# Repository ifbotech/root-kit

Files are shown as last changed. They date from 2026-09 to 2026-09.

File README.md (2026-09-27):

# ROOTKIT

Una maceta con sensores y una pantalla que muestra **dos cosas: un QR al
principio y una cara después**. Cada ROOTKIT es uno de cuatro **Rooties**
—**Kip** el piloto audaz, **Nori** la crítica, **Blink** el cíclope optimista
y **Plum** la berenjenita—: la **carcasa impresa en 3D** es el cuerpo, y la
pantalla pone la cara, que reacciona a lo que necesita la planta. Todo lo
demás —números, tareas, avisos, la colección de Rooties y la charla con tu
planta— vive en **ROOTLAB**, la app del teléfono.

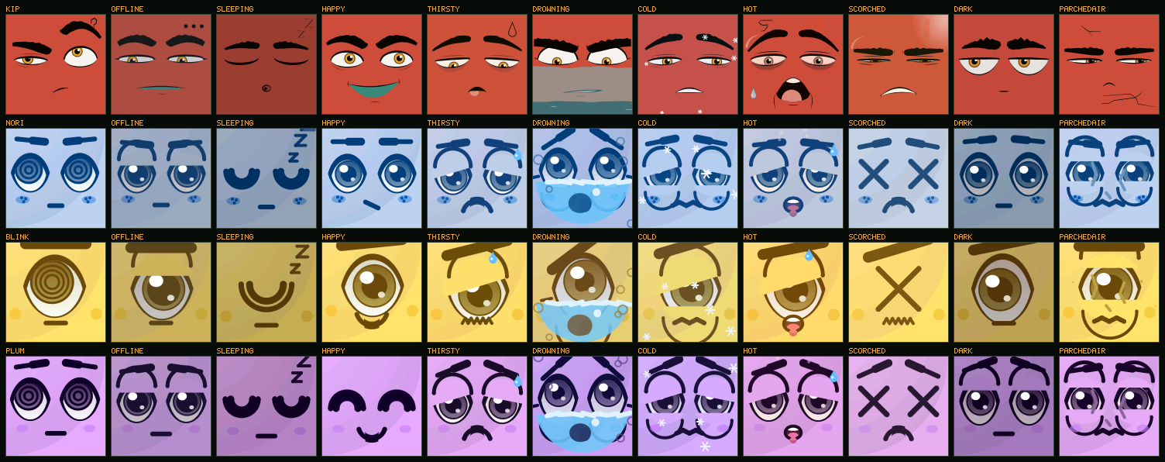
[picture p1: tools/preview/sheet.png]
Los cuatro Rooties en los once ánimos


Kip es rojo, con cejas negras tupidas que saltan y ojos blancos de iris
ámbar, y ya se dibuja y se mueve como en las láminas de Rocío: cada ánimo es
una secuencia de sus dibujos, interpolada cuadro a cuadro. Nori tiene ojos
almendrados y pecas; Blink, UN ojo enorme; Plum, ojos de cachorro. Cuando la
planta se ahoga el agua le llega a los ojos, y cuando el aire está seco la
cara se cuartea.

La figura define qué Rooti es; el cofre de la app sortea su **piel**: común
(70 %), rara (25 %) o épica (5 %). Las tres comparten la paleta del personaje
—es parte de quién es— y lo que cambia es el **acabado**: el fuego de Kip, el
acero y el cristal de Nori, el oro de Blink, el aura de Plum. La nube se la
manda a la maceta y la cara se pinta con eso:

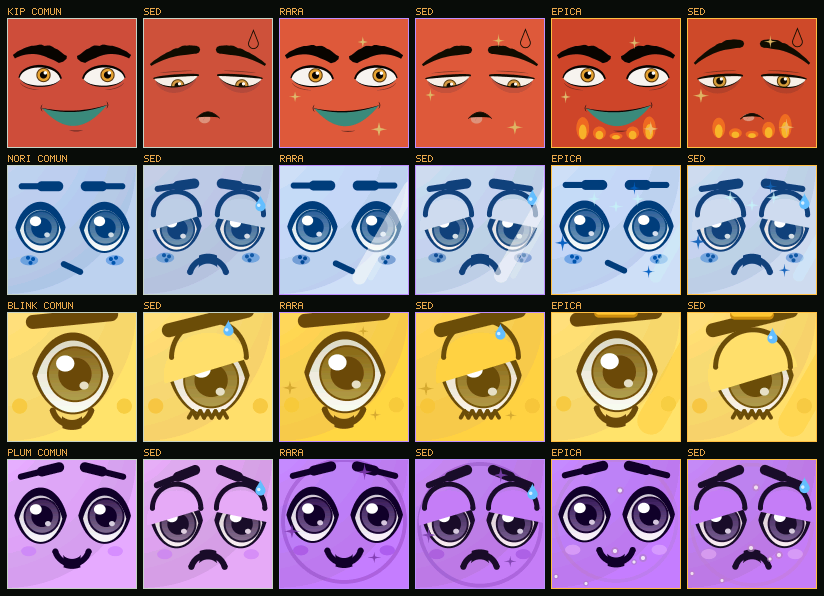
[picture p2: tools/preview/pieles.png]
Las tres pieles de cada Rooti


Para verlos a los cuatro juntos, en movimiento y con el cuerpo 3D: `npm start`
en root-lab y abrir **`/elenco/`**. Las láminas de acá se regeneran con
`make capturas`.

Del primer encendido a la cara: el QR, los ojos dormidos mientras esperás el
cofre, el despertar y la cara.

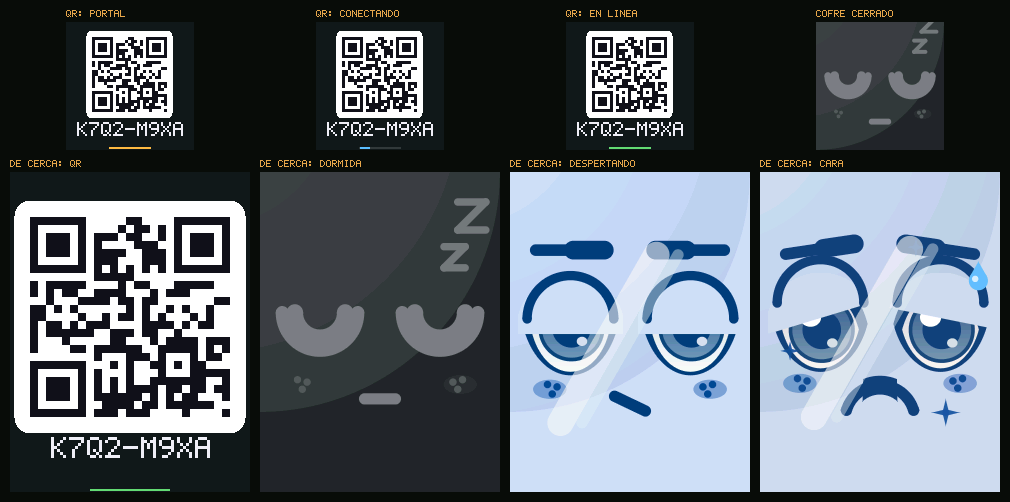
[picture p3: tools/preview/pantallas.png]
Las pantallas del ROOTKIT: QR, dormida, despertar y cara


Cuando abrís el cofre en la app, la maceta abre los ojos:

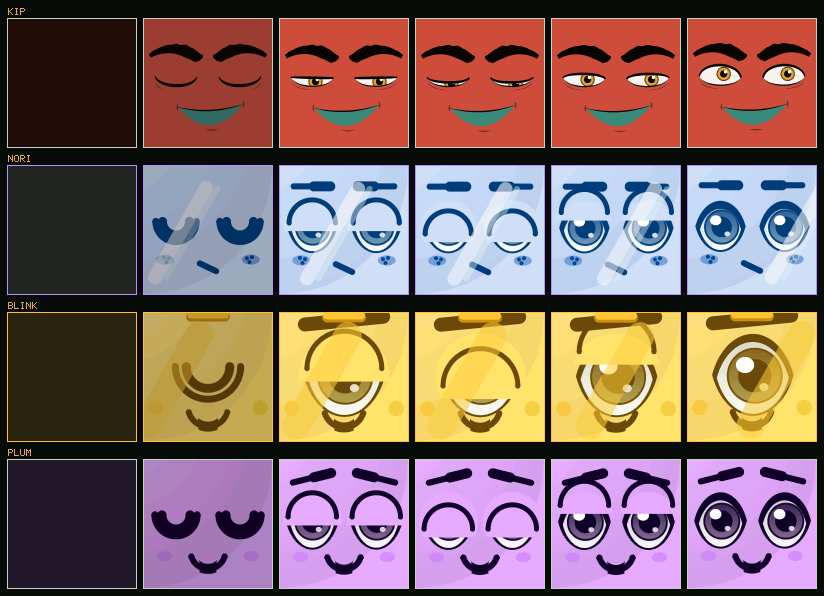
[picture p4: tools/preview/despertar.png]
El despertar de cada Rooti


Y cuando cambia de ánimo no salta: la cara pasa de una expresión a la otra
en un tercio de segundo, con un parpadeo en el medio.

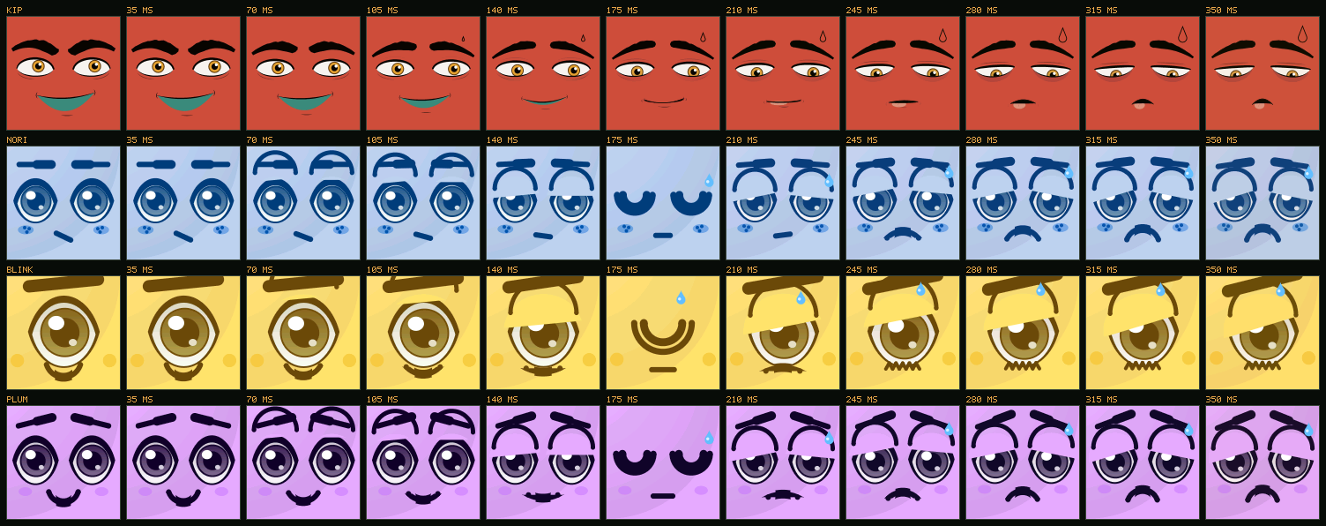
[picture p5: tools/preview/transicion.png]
De contento a sediento, cuadro a cuadro


ROOTLAB se pinta con los colores de la piel que salió, y en el teléfono se ve
el Rooti entero en 3D, con esta misma cara pintada encima, como una mascota
que se acaricia y se cuida.

## Los repositorios

| | Qué hay |
|---|---|
| **rootkit** (este) | Firmware, hardware, carcasas y la documentación del aparato |
| [**root-lab**](https://github.com/ifbotech/root-lab) | **ROOTLAB**: la app, la nube, las cuentas, la IA y el chat con la planta, el correo, las notificaciones y un emulador del Rooti |

Dos cosas de root-lab que se usan desde acá y conviene saber dónde están: **la trastienda** (el panel de quien hace el producto, en `/rootkit/admin`: [docs/trastienda.md](https://github.com/ifbotech/root-lab/blob/main/docs/trastienda.md)) y **los agentes** que revisan el proyecto y anotan mejoras ([agentes/](https://github.com/ifbotech/root-lab/tree/main/agentes), con [RUTINAS.md](https://github.com/ifbotech/root-lab/blob/main/agentes/RUTINAS.md) para dejarlos corriendo).

El agente de hardware, en cambio, vive **acá**: [agentes/ingeniero-de-hardware.md](agentes/ingeniero-de-hardware.md) diseña la PCB impresa con cinta de cobre y el diagrama de conexiones del producto físico.

**Probalo en línea:** https://ifbotech.com/rootkit/ (emulador en
https://ifbotech.com/rootkit/emulador/).

## El hardware

| | ROOTKIT |
|---|---|
| Placa | ESP32-C3 SuperMini (un ESP32 DevKit en el banco de pruebas) |
| Pantalla | TFT 1,44" 128×128 IPS, en una ventana biselada de la carcasa |
| Sensores | suelo capacitivo (calibrable desde la app), AHT20, BH1750, toque; DS18B20 opcional |
| Batería | 18650 con carga por USB-C: unos 6 meses |
| Carcasa | impresa en 3D **sin soportes**: es el cuerpo del Rooti |

Se **actualiza solo por aire**, con firmware firmado, y sale de **fábrica**
con su identidad grabada: [docs/ota.md](docs/ota.md) y
[docs/fabrica.md](docs/fabrica.md). Detalle de pines, consumo y lista de
compras: [docs/hardware.md](docs/hardware.md). La placa en sí —un sustrato
impreso en 3D con canaletas y cinta de cobre— está en
[docs/pcb.md](docs/pcb.md), y cómo se arma una unidad, en
[docs/armado.md](docs/armado.md).

## Empezar

```bash
make test         # 2277 comprobaciones del firmware, sin placa
make sim          # los cinco Rooties en una ventana, en vivo
make sheet        # 8 Rooties × 11 ánimos
make transicion   # el cambio de ánimo, cuadro a cuadro
make pantallas    # QR, dormida, despertar y cara
make wasm         # el renderer para la app (necesita clang y lld)
make placa        # compila el producto (c3-144) y el banco (devkit-144) con PlatformIO
```

El prototipo NodeMCU que soldó Rocío corre el **firmware de banco**: arranca
directo en la cara de Kip, que reacciona a los sensores, y muestra sus
lecturas ([docs/banco.md](docs/banco.md)):

```bash
cd firmware && pio run -e banco-nodemcu -t upload && pio device monitor
```

Flashear una placa:

```bash
cd firmware
pio run -e c3-144 -t upload && pio device monitor
```

Para ver el flujo completo sin placa, abrí el emulador en
**https://ifbotech.com/rootkit/emulador/** (o levantá **root-lab** en la
compu): corre este mismo firmware en el navegador y su QR abre ROOTLAB en el
teléfono. Por defecto la placa también sincroniza con ese servidor, por
HTTPS y verificando su certificado.

En Windows el firmware se compila y prueba dentro de WSL. Ver
[docs/entorno.md](docs/entorno.md).

## Estructura

```
firmware/
  core/        ánimo, especies, Rooties, vínculo, enlace, código, SHA-256
  gfx/         framebuffer, antialiasing en punto fijo, tipografía
  art/         expresiones, el rig de caras y la lámina de Kip
  ui/          cara, cara dormida, despertar y QR
  nodo/        sensores, suelo, batería, muestreo adaptativo, historial
  net/         JSON y el contrato con la nube
  esp32/       la placa: pantalla, sensores, portal, red (con certificados), energía
  wasm/        el núcleo compilado para el navegador
  banco/       el firmware de banco del prototipo NodeMCU (sensores + Kip)
  sim/ test/   simulador y pruebas
  third_party/ qrcodegen (MIT)
hardware/pcb/  el sustrato impreso: el dato, el modelo y lo que se genera
docs/          arquitectura, hardware, firmware, nube, roadmap, decisiones
tools/         capturas, estación de fábrica y el generador del sustrato
```

## Documentación

| | |
|---|---|
| [roadmap.md](docs/roadmap.md) | **Checklist y roadmap**: qué está hecho y qué falta, por fase |
| [arquitectura.md](docs/arquitectura.md) | Las tres piezas, el flujo y quién decide qué |
| [hardware.md](docs/hardware.md) | Placa, pantalla, sensores, batería, carga y conexiones |
| [pcb.md](docs/pcb.md) | **La PCB impresa**: el sustrato con canaletas, la cinta de cobre y lo que se verifica solo |
| [conexiones.md](docs/conexiones.md) | El diagrama de conexiones, red por red (generado) |
| [armado.md](docs/armado.md) | **Armar una unidad**: paso a paso, con los controles de multímetro |
| [firmware.md](docs/firmware.md) | Cómo está armado, cómo compilar y qué hace al encender |
| [nube.md](docs/nube.md) | El contrato con la nube, con vectores de prueba |
| [ota.md](docs/ota.md) | Actualizaciones por aire firmadas, y qué pasa si una versión no anda |
| [fabrica.md](docs/fabrica.md) | La estación de fábrica: identidad, registro en la nube y etiqueta |
| [carcasas.md](docs/carcasas.md) | Diseño e impresión de las carcasas |
| [decisiones.md](docs/decisiones.md) | Lo que se decidió, lo que se revisó y por qué |
| [testing.md](docs/testing.md) | Qué cubren las pruebas |
| [banco.md](docs/banco.md) | **El firmware de banco** del prototipo NodeMCU: flashearlo y probar cada sensor |
| [entorno.md](docs/entorno.md) | Herramientas y simulador |

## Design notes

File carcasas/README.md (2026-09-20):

# Los Rooties en STL — referencia de forma

<!-- GENERADO por root-lab/tools/rooties-stl.mjs (npm run carcasas). Para
     cambiar una figura se edita root-lab/public/lib/rooti3d/formas.mjs. -->

**Esto no son las carcasas.** Son los cinco personajes tal como se ven en
ROOTLAB, exportados para tenerlos a mano mientras se modela el aparato.

El personaje y la carcasa son dos objetos distintos, a propósito:

* el **personaje** se esculpe para verse bien: tiene patitas separadas, brazos
  levantados y sombreros que vuelan. Varias de esas cosas no salen de una
  impresora sin soporte, y está bien que así sea;
* la **carcasa** tiene que alojar la celda 18650 parada, el módulo del TFT de
  1,44" y la electrónica, apoyarse sin volcarse y salir de la impresora. Se
  diseña aparte, en el CAD del hardware, tomando de acá la silueta y el
  carácter.

## Los cinco

| Rooti | Archivo | Tamaño (mm) | Triángulos |
| --- | --- | --- | --- |
| Kip | `kip.stl` | 81.9 × 140.9 × 71.9 | 35344 |
| Nori | `nori.stl` | 86 × 116 × 80 | 33188 |
| Blink | `blink.stl` | 86.8 × 132.9 × 74 | 33368 |
| Plum | `plum.stl` | 85.9 × 121.1 × 72.8 | 29432 |

Las mallas son cerradas y con las normales hacia afuera (volumen con signo
positivo), así que un laminador las acepta sin reparaciones. Si querés
imprimir la figura como adorno, va con soportes y a 0,15 mm de capa.

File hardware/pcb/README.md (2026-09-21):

# El sustrato impreso

El núcleo común de ROOTKIT: una **protoboard impresa**. Una placa de PETG con
canaletas, cinta de cobre de 5 mm dentro de ellas, y tiras de pines donde se
**clavan** el ESP32, la pantalla y los sensores. Su única función es
interconectarlos. Uno solo para los cuatro Rooties.

Desde la v3.0 la placa **no** tiene ventana de pantalla, ni bolsillo de
cargador, ni lugar para el USB: dónde va físicamente cada módulo lo decide la
carcasa. El porqué de cada número está en [../../docs/pcb.md](../../docs/pcb.md).

**Qué es cada archivo:**

| | |
|---|---|
| `nucleo.json` | **El dato.** Reglas, módulos, dónde va cada uno y qué va conectado con qué. Es lo único que se edita a mano |
| `generado/ruteo.json` | **Por dónde** corre cada pista y cada puente. Lo escribe `tools/ruteo.py` con `make rutear`, no se edita |
| `sustrato.scad` | El modelo paramétrico. No tiene ni un número del diseño: los lee de `generado/sustrato_datos.scad` |
| `estampadora.scad` | El **negativo**: las mismas canaletas en relieve, para meter toda la cinta de una prensada. Va espejado en X |
| `encaje.scad` | La prueba de que una entra en la otra: choque vacío y nervaduras llegando al fondo |
| `cupon.scad` | **La pieza de prueba del proceso**, con sus dos modos de encaje. Tres profundidades de canaleta, tres luces de nervadura y la pared mínima, todo en 52 × 44 mm. Se imprime **antes** que el sustrato: ver `docs/armado.md`, paso 0.a |
| `generado/cupon-sustrato.stl` | El cupón, en PETG, sin soportes |
| `generado/cupon-estampadora.stl` | Su estampadora, nervaduras hacia arriba |
| `generado/sustrato_datos.scad` | Los datos que come el modelo |
| `generado/nucleo-sustrato.stl` | La pieza para imprimir, en PETG, sin soportes |
| `generado/nucleo-estampadora.stl` | La estampadora, nervaduras hacia arriba, sin soportes |
| `generado/plantilla-cinta.svg` | La plantilla **1:1** para imprimir en papel y cortar la cinta |

Todo lo de `generado/` sale de `nucleo.json`, y también `docs/conexiones.md`
y `firmware/test/redes.h`. Se regenera con:

```bash
make pcb        # rehace todo a partir del ruteo commiteado
make rutear     # vuelve a rutear y después rehace todo (tarda ~20 s)
make cupon      # el cupón de prueba y su estampadora, con su encaje
```

**Cuándo hace falta `make rutear`:** cuando se mueve un módulo, se cambia una
red o se toca una regla. `make pcb` solo no vuelve a rutear —el ruteo está
commiteado a propósito— pero tampoco deja pasar uno viejo: lo revisa con la
misma geometría de siempre, y un ruteo desfasado deja una red en dos pedazos
o dos canaletas demasiado juntas.

y CI falla si quedó desfasado. Los STL salen con las facetas
ordenadas a propósito: OpenSCAD las escribe en el orden en que
terminan sus hilos, y sin eso `make pcb` ensuciaría el árbol cada vez
que se corre aunque no haya cambiado nada.

**Antes de tocar `nucleo.json`:** leé [docs/pcb.md](../../docs/pcb.md) (qué
es el sustrato, qué se resolvió y por qué) y acordate de que los pines tienen
una sola verdad, que es `firmware/esp32/placa.h`. Si cambiás un pin, cambia
también ahí y en `docs/hardware.md`, en el mismo commit: `make test` lo
verifica.

Para armar una unidad: [docs/armado.md](../../docs/armado.md).

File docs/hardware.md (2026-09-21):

# Hardware

Todo lo que va adentro de un ROOTKIT: la placa, la pantalla, los sensores, la
batería y cómo se conecta. Los pines de este documento son los
de [`firmware/esp32/placa.h`](../firmware/esp32/placa.h); si cambian allá,
cambian acá.

**Dónde va cada cosa físicamente** está en [pcb.md](pcb.md): el sustrato
impreso en 3D con canaletas y cinta de cobre sobre el que se monta todo. El
**diagrama de conexiones completo**, red por red, se genera desde el mismo
dato que el sustrato y vive en [conexiones.md](conexiones.md). Y el paso a
paso para armar una unidad, con los controles de multímetro, en
[armado.md](armado.md).

## Resumen

| | ROOTKIT (el producto) | Banco de pruebas |
|---|---|---|
| Placa | ESP32-C3 SuperMini | ESP32 DevKit 30 pines |
| Pantalla | TFT 1,44" 128×128 IPS (ST7735S), área activa 25,9 × 25,9 mm. **El sustrato v3.0 trae la tira de 9 pines de la de 2,2"**: ver "Inventario" | la misma |
| Sensores | suelo capacitivo, AHT20 (o SHT21), BH1750, toque; DS18B20 opcional | los mismos |
| Batería | **18650** de 2600–3500 mAh, parada, abajo (baja el centro de gravedad) | USB |
| Carga | USB-C con TP4056 + protección + carga compartida | — |
| Firmware | `pio run -e c3-144` | `pio run -e devkit-144` |

**Un solo panel.** El primer prototipo usaba un TFT de 2,2" (ILI9341,
240×320). Se retiró: las cinco carcasas son para el de 1,44", que entra desde
atrás en una ventana biselada a 45° ([carcasas.md](carcasas.md)), y mantener
dos paneles duplicaba compilaciones, láminas y pruebas sin un producto
detrás. El motor gráfico sigue escalando al lado corto del panel
(`gfx/panel.h`), así que sumar otro tamaño algún día es agregar su bloque en
`esp32/placa.h` y su clase en `esp32/pantalla.cpp`.

---

## Inventario: qué hay sobre la mesa, qué falta y qué sobra

Estado al **21 de septiembre de 2026**, mirando las piezas que hay. Esta
tabla es lo que decide si se puede armar una unidad completa hoy: **no se
puede**, faltan cuatro cosas, y dos de ellas son baratas.

### Lo que hay y sirve

| Pieza | Qué es | Dónde entra | Cuidado |
|---|---|---|---|
| **ESP32-C3 SuperMini** | el cerebro | `U1`, 16 pines | Confirmar que la tira sea 2 × 8 a 2,54 mm y las filas a 15,24 |
| **SHT21 / HTU21 / Si7021** (módulo azul, 4 pines) | aire: temperatura y humedad | `J_AIRE` | **El firmware habla AHT20 (0x38), no SHT21 (0x40)**: falta el driver. Ver abajo |
| **Capacitivo de suelo v2.0.0** (placa negra larga) | humedad de la tierra | `J_SUELO`, 3 pines | Mirar que el chip diga **TLC555**, no NE555. Sellar el canto |
| **HW-390** (placa negra chica, conector JST) | el mismo capacitivo, versión con JST | repuesto, o segunda unidad | Igual que el anterior |
| **TFT 2,2" ILI9341 240 × 320 SPI** (placa roja, 9 pines) | la pantalla | `J_TFT`, 9 pines | **El firmware retiró este panel en la 0.6.0**: hay que volver a sumarlo. Ver abajo |
| **Tiras de pines macho** | el montaje entero | todas las tiras | Es exactamente lo que la v3.0 necesita |
| **Cable JST de 3 pines** | para el HW-390 | `J_SUELO` | |

### Lo que falta para armar una unidad completa

| Pieza | Para qué | Sin ella |
|---|---|---|
| **BH1750 (GY-302)** | luz, en lux reales | El Rooti no puede decir "tengo poca luz", que es una de las cuatro cosas que mide |
| **TTP223** | el toque | No hay forma de despertar el aparato ni de prender la pantalla a mano |
| **Módulo TP4056 USB-C con protección (6 pines)** | cargar la celda | Sólo funciona enchufado por el USB de la SuperMini |
| **18650 de marca + portapilas** | la energía | ídem |
| **Interruptor deslizante** | despachar el aparato apagado | Se puede vivir sin él en el prototipo |
| **DS18B20 sumergible** | temperatura de la tierra | Es **opcional**: el firmware anda sin sonda |
| **SMD 1206 y SOT-23** (ver la lista de compras) | los MOSFET, las resistencias y los capacitores del sustrato | Sin el AO3401 del riel conmutado, el capacitivo come 5 mA las 24 horas y la batería dura días, no meses |
| **Cinta de cobre de 5 mm** y **filamento PETG** | el sustrato | |

Las dos urgentes son el **BH1750** y el **TTP223**: son las dos que faltan
para que el producto haga lo que promete, y entre las dos cuestan menos que
la pantalla. El TP4056 y la celda se pueden postergar mientras se prueba
enchufado.

### Lo que sobra, y para qué podría servir

| Pieza | Veredicto |
|---|---|
| **HC-SR04** (ultrasónico, 4 pines) | **No entra en el ROOTKIT.** Quiere 5 V, come ~15 mA mientras mide, necesita dos GPIO —y los trece del C3 ya están todos usados— y mide distancia, que no es ninguna de las cuatro magnitudes de una planta. La única idea razonable sería medir el nivel del agua en el plato, pero para eso un capacitivo de nivel es más chico, más barato y funciona mojado. **Guardarlo para otro proyecto.** |
| **Módulo de micrófono** (placa roja con potenciómetro) | **No ahora, pero no tirarlo.** El roadmap tiene sonido en la Fase 2b, y es sonido de *salida* (el Rooti hace ruiditos), no de entrada. Un micrófono abre otra cosa: despertar al aparato con una palmada, sin tocarlo. Es una función de producto que hoy no existe, y ocuparía el GPIO que libera atar el CS de la pantalla a masa. **Anotado como idea, no como pieza del diseño.** |
| **Módulo de fotorresistencia LDR** (placa con potenciómetro, salidas AO y DO) | **No como sensor de luz del producto**, y eso está decidido desde hace rato: un LDR no da lux sin calibrar cada unidad, y la biblioteca de especies de ROOTLAB está en lux. Pero **sí sirve de sustituto mientras no llega el BH1750**: su salida analógica se puede clavar donde va el capacitivo para tener *algo* de luz en el banco y probar la lógica de estados de ánimo. Es un parche de banco, no del producto. |

### Las dos deudas de firmware que deja este inventario

Ninguna es del sustrato —la placa v3.0 está bien para las dos— pero sin
ellas los módulos que hay sobre la mesa no se pueden usar:

1. **El sensor de aire.** El firmware inicializa y lee un **AHT20 en 0x38**
   (`esp32/sensores_hw.cpp`, y la conversión en `nodo/sensores.c`). El módulo
   que hay es un **SHT21/HTU21 en 0x40**, con otro protocolo: comandos 0xF3
   (temperatura) y 0xF5 (humedad) en modo *no hold*, tres bytes por lectura
   con su CRC-8, y las fórmulas `T = -46,85 + 175,72 · S/65536` y
   `RH = -6 + 125 · S/65536`. Es un driver nuevo, pequeño y **testeable en el
   escritorio** (la conversión es C puro, como la del AHT20). Recomendación:
   agregarlo al lado del AHT20 y elegir cuál se compila desde
   `platformio.ini`, no reemplazarlo.
2. **El panel.** El ILI9341 de 2,2" existió hasta la 0.6.0 y se retiró a
   propósito. Volver a sumarlo es su bloque en `esp32/placa.h`
   (`RK_PANEL_ILI9341_240`, 240 × 320) y cambiar la clase del panel en
   `esp32/pantalla.cpp`, que ya es LovyanGFX. El motor gráfico escala solo al
   lado corto, así que la cara se dibuja igual. Recomendación: sumarlo como
   **variante de banco** (`c3-22`, `devkit-22`) y dejar la de 1,44" como
   producto hasta que haya carcasa.

---

## ¿ESP32-C3 SuperMini o ESP32 de 30 pines?

**Conviene el C3 SuperMini para el producto.** El de 30 pines queda como
placa de banco. El firmware compila para las dos (`c3-144`, `devkit-144`),
así que la decisión no ata nada.

La diferencia de precio es chica y el espacio sobra, así que la decisión no
sale de ahí. Sale de la batería:

| | ESP32-C3 SuperMini | ESP32 DevKit 30 pines |
|---|---|---|
| Regulador | ME6211, ~40 µA en reposo | AMS1117, **~5 mA en reposo** |
| USB | nativo del chip, sin conversor | CP2102/CH340, alimentado desde 3V3 |
| LED de encendido | uno (se puede desoldar) | uno, fijo |
| **Placa en deep sleep** | **~50 µA** sin el LED | **~6–10 mA** |
| Días que dura una 18650 sólo durmiendo | años | **~2 semanas** |
| CPU | RISC-V 160 MHz, 1 núcleo, sin FPU | Xtensa 240 MHz, 2 núcleos, con FPU |
| Pines útiles | 13 | ~25 |
| Tamaño | 22,5 × 18 mm | 51 × 28 mm |

El DevKit gasta más durmiendo que el C3 despierto midiendo. Con un regulador
que consume 5 mA todo el tiempo, ninguna optimización de firmware salva la
batería: habría que desoldarle el regulador y alimentarlo por 3V3 desde uno
externo, y a esa altura es otra placa.

Donde el DevKit gana es en el banco: sobran pines, tiene FPU y dos núcleos, y
para probar sensores nuevos es más cómodo. Para desarrollar enchufado a USB, perfecto.

**Lo que el C3 pide a cambio:**

- Sólo GPIO0–GPIO5 despiertan del deep sleep: el sensor de toque va ahí.
- GPIO2, GPIO8 y GPIO9 son de arranque. El mapa de pines los usa para cosas
  que están en alto al encender (ver la tabla de conexiones).
- No tiene FPU: por eso todo el motor gráfico es de punto fijo. En 128×128
  la cara se dibuja holgada a 30 cuadros por segundo (`make bench`); se
  confirma en la placa en la Fase 1 del [roadmap](roadmap.md).
- Algunas SuperMini traen un LED rojo de encendido siempre prendido (1–3 mA).
  En la placa del producto se desuelda o se le corta la pista.

---

## La pantalla

La pantalla del ROOTKIT muestra **dos cosas en toda su vida: el QR y los
ojos**. Nada de números ni íconos. La cara es vectorial y se escala al lado
corto del panel.

### TFT 1,44" 128×128 IPS (ST7735S)

- Controlador ST7735S, memoria de 132×162.
- Casi todos los lotes necesitan un corrimiento: por defecto
  `RK_TFT_OFS_X=2`, `RK_TFT_OFS_Y=1`. Si la imagen sale corrida, con rojo y
  azul cambiados o con los colores invertidos, se corrige en
  `platformio.ini` con `RK_TFT_OFS_X/Y`, `RK_TFT_BGR` y `RK_TFT_INVERT`, sin
  tocar código.
- Luz de fondo: 15–30 mA. **No va directo a un GPIO.** Va a una etapa de dos
  transistores que conmuta del **lado alto**: un N-MOSFET (AO3400) con GPIO21
  en la compuerta tira de la compuerta de un P-MOSFET (AO3401) que lleva 3V3
  al pin `BL`. Es la forma que funciona tanto si `BL` es el ánodo del LED
  —que es lo más común en estos módulos— como si es la entrada de control de
  un transistor del propio módulo. Si resultara ser el cátodo, un selector de
  estaño (`JP_BL`) pasa la etapa al lado de masa sin rehacer nada. El
  detalle y el porqué de cada resistencia, en [pcb.md](pcb.md).
- El PWM no invierte: GPIO21 alto enciende. Si algún lote pide lo contrario,
  se compila con `-DRK_TFT_BL_INVERTIDO=1`.
- El framebuffer ocupa 32 KB: en un C3 con el wifi prendido sobra lugar.

---

## Sensores

Todo lo que puede medir un ROOTKIT, en orden de importancia. Los de las dos
primeras tablas los lee el firmware hoy.

### Imprescindibles

| Magnitud | Sensor | Interfaz | Por qué este |
|---|---|---|---|
| Humedad de la tierra | **Capacitivo v1.2 / v2.0** | analógico (ADC) | Sin metal expuesto: no se corroe. Es lo que más mata plantas. |
| Temperatura y humedad del aire | **AHT20** (o AHT21) | I2C `0x38` | ±0,3 °C, ±2 % HR, 0,25 µA dormido. Alternativa más precisa: SHT40 (`0x44`). |
| Luz | **BH1750** (GY-302) | I2C `0x23` | Da lux reales, calibrados. Llega a 54.612 lux; alcanza para interior. |

### Recomendados

| Magnitud | Sensor | Interfaz | Para qué |
|---|---|---|---|
| Temperatura de la tierra | **DS18B20** sumergible | 1-Wire, pull-up 4,7 kΩ **al riel fijo** | Las raíces sienten la tierra, no el aire. Clave en invierno junto a una ventana. |
| Toque | **TTP223** | digital | Prende la pantalla y despierta al aparato. Funciona a través de 2–3 mm de plástico. |
| Batería y USB | divisor 470 kΩ / 470 kΩ + 100 nF | ADC | Porcentaje de carga y detección de enchufado con un solo pin. |

### Para más adelante

| Magnitud | Sensor | Por qué no ahora |
|---|---|---|
| Luz de sol pleno | VEML7700 | Mide hasta 120.000 lux y ve mejor la penumbra. Para macetas de balcón. |
| Fertilidad (conductividad) | sonda EC RS485 "7 en 1" | Las baratas analógicas se corroen; las buenas piden 12 V y cuestan más que el ROOTKIT. |
| Golpe, caída, "tocar la maceta" | LIS3DH | Reemplazaría al TTP223 con despertar por movimiento (~6 µA). |
| UV | LTR390 | Sólo interesa en exterior. |
| Nivel del plato o reservorio | capacitivo de nivel | Accesorio para autorriego. |
| Presión | BMP280 | Viene en la plaquita combinada AHT20+BMP280, pero a una planta no le cambia nada. |

### Los que NO

- **Humedad de suelo resistivo** (las dos patitas metálicas): se corroe en
  semanas y además electroliza la tierra.
- **DHT11 / DHT22**: imprecisos, lentos y con un protocolo de tiempos
  frágiles. El AHT20 cuesta lo mismo.
- **LDR (fotorresistencia)**: no se puede convertir a lux sin calibrar cada
  unidad, y la especie pide lux.

### Tres cuidados del capacitivo de suelo

1. **Mirar el chip.** Tiene que decir **TLC555**. Muchos lotes vienen con un
   NE555, que no arranca a 3,3 V y da lecturas planas.
2. **Sellar el borde.** El canto de la placa absorbe agua y en un mes la
   lectura deriva. Esmalte de uñas o epoxi en los bordes y sobre el circuito.
3. **Calibrar cada unidad.** Seco en el aire y sumergido hasta la línea: dos
   lecturas. La app manda la calibración (`calibracion.seco/mojado`); sin
   ella se usa la de fábrica de `nodo/soil.c`.

El capacitivo consume ~5 mA encendido. Por eso se alimenta a través de un
P-MOSFET (AO3401) que el firmware prende 150 ms por lectura: apagado, no
gasta nada.

### Qué cuelga de qué riel, y por qué

**Del riel conmutado cuelga sólo el capacitivo.** Es el único que come de
verdad. El AHT20, el BH1750, el TTP223 **y el DS18B20** van al 3V3 fijo.

El DS18B20 estaba pensado para el riel conmutado y se mudó: si la sonda
cuelga del riel conmutado pero su pull-up sale del 3V3 fijo, con el riel
apagado la línea de datos le mete corriente a la sonda por su pata de datos y
carga el riel muerto. Y el pull-up no puede irse al riel conmutado porque
**GPIO8 es pin de arranque** y tiene que estar alto al encender, justo cuando
el riel está apagado. La sonda consume **1 µA como máximo en reposo**: 24 µAh
por día, el 0,2 % del presupuesto. Por ese precio desaparecen el camino
parásito y la duda del arranque. Hay una prueba (`test_placa.c`) que falla si
alguien la devuelve al riel conmutado.

El riel conmutado lleva además una **resistencia de purga de 100 kΩ** para
que baje rápido al apagarlo, y un **100 nF** junto al borne del sensor.

---

## Batería y carga

### La celda

- Una **18650** de 2600–3500 mAh, de marca (Samsung, LG, Molicel, Sony). Las
  "9900 mAh" de sitios de ofertas tienen 800 mAh y a veces arena. Va
  **parada, abajo**: es la pieza más pesada y hace de lastre
  ([carcasas.md](carcasas.md)).
- Si algún día hay una carcasa más chica: **LiPo plana** de 1000–1200 mAh
  (103450 o 603450) con su plaquita de protección. El firmware no cambia.

### El circuito

> **Desde el sustrato v3.0 esta etapa entera vive FUERA de la placa.** El
> sustrato es una protoboard de interconexión y nada más: la energía le llega
> por `J_PWR`, dos pines, ya conmutada por el interruptor. Todo lo que está
> dibujado acá abajo —el TP4056, el SS34, el AO3401 de carga compartida, su
> resistencia de compuerta y el interruptor— es un **arnés aparte**, que se
> arma sobre el propio módulo TP4056 y se mete donde la carcasa tenga lugar.
> No cambió ni un componente ni una conexión; cambió dónde vive. La razón es
> que la carga es lo único del aparato que toca 5 V y un ampere, y sacarlo
> del sustrato es lo que permitió bajar los rieles de 4 a 2,2 mm y usar un
> solo rollo de cinta de 5 mm ([pcb.md](pcb.md), "La cinta manda").
>
> El divisor del riel (470 k / 470 k / 100 nF) **sí** sigue en el sustrato:
> mide `J_PWR.VIN`, que es lo que entra después del interruptor.

```
                 USB-C 5 V
                     │
             ┌───────┴────────┐
             │  TP4056 + DW01A │  módulo "con protección", 6 pines
             │   IN+     B+ ───┼──── + celda
             │   IN-     B- ───┼──── - celda
             │          OUT+ ──┼──┐
             └────────────────┘  │   (batería protegida)
                     │            │
      5 V ──SS34──┬──┘            │
                  │   AO3401 (P)  │
                  ├──── S   D ────┘   (fuente del lado de la carga,
                  │     G              drenador del lado de la celda)
                  │     └── al 5 V del USB, con 100 kΩ a GND
                  │
                  └── interruptor ──┬── 5V de la SuperMini (regula a 3,3 V)
                                    │
                                    └── 470 kΩ ──┬── GPIO1 (ADC)
                                                 ├── 470 kΩ ── GND
                                                 └── 100 nF ── GND
```

El divisor cuelga de **después** del interruptor y no del nodo de sistema:
lee exactamente lo mismo (el interruptor no tiene caída) y con el aparato
apagado en la caja no gasta ni un microamperio en vez de 3,9 µA.

**Carga compartida (AO3401 + SS34).** Sin esto, con el USB enchufado el
aparato consume a través del cargador, el TP4056 nunca ve la corriente
bajar y la carga no termina: la celda se sobrecarga lento. Con el MOSFET,
enchufado el aparato come del USB por el Schottky y el TP4056 sólo carga la
celda.

**Corriente de carga.** La fija la resistencia `RPROG` del módulo:
1,2 kΩ = 1 A (bien para la 18650), 2 kΩ = 580 mA (mejor para la LiPo de
1000 mAh), 3 kΩ = 400 mA (LiPo de 500 mAh).

**Regulación.** La SuperMini se alimenta por su pin `5V` y su ME6211 baja a
3,3 V. Anda con la celda por encima de ~3,5 V; debajo, en los picos de wifi
puede caer. El firmware corta a 3,15 V (`RK_BATT_CUTOFF_MV`) y la protección
DW01A a 2,4 V. Para aprovechar la celda entera en la versión de producción:
un buck-boost **TPS63802** (3,3 V estables de 2,7 a 4,2 V, 11 µA en reposo)
o un LDO **RT9080** (2 µA, 600 mA). Agregar 220–470 µF de bajo ESR cerca
del 3V3 para los picos de transmisión.

**USB y batería con un solo pin.** Enchufado, el riel sigue al USB menos el
Schottky: ~4,6 V. A batería, a la celda: 4,2 V o menos. El firmware lee el
divisor y, por encima de 4,35 V, sabe que está enchufado
(`nodo/sensores.c`). En ese caso reporta la batería como "desconocida" en
lugar de un 100 % falso.

**Interruptor.** Entre la carga compartida y la placa, para despachar el
aparato apagado en la caja. Y es además la llave de seguridad del párrafo que
sigue.

> **Los dos USB y la celda.** La SuperMini tiene su propio USB-C —es por
> donde se flashea y por donde trabaja la estación de fábrica— y el TP4056
> tiene otro. En muchas SuperMini el pin `5V` está unido a su VBUS sin
> diodo: con la celda puesta y el interruptor prendido, enchufar el USB de la
> SuperMini mete 5 V en el nodo de sistema, el AO3401 conduce (no hay USB en
> el cargador, así que su compuerta está en bajo) y **la celda recibe 5 V sin
> control de carga**.
>
> El aparato se arma de forma que eso no pueda pasar: se flashea **antes de
> poner la celda**, el USB de la SuperMini **no sale al exterior**, el
> interruptor corta ese camino, y el sustrato lleva grabado
> `APAGAR ANTES DE FLASHEAR` al lado del módulo. La regla, para siempre: **el
> USB de la SuperMini se enchufa con el interruptor apagado.** El análisis
> completo y por qué un diodo en serie no es la solución, en
> [pcb.md](pcb.md). Para la Fase 5: un solo USB-C y un multiplexor de
> alimentación de verdad.

### Cuánto dura

Estimaciones a verificar con un medidor en la Fase 1. Los costos de
medición y transmisión salen del modelo de `nodo/power.c`.

| Consumo por día | ROOTKIT (1,44" + 18650) |
|---|---:|
| Deep sleep (~0,15 mA con panel dormido) | 3,6 mAh |
| Mediciones adaptativas (cada 2–30 min) | 1,5 mAh |
| ~30 envíos a la nube (wifi + TLS) | 2,3 mAh |
| Pantalla al tocar: 20 veces × 20 s | 5,6 mAh |
| **Total** | **~13 mAh** |
| **Con una 18650 de 3000 mAh (20 % de margen)** | **~6 meses** |

Una actualización por aire (bajar ~1,2 MB por wifi y escribir la flash)
cuesta unos 3 mAh: a batería sólo se hace con la celda arriba de 3,7 V
([ota.md](ota.md)).

**Pantalla siempre encendida** a batería: unos cuatro días. Enchufado, sin
límite. La app lo explica al activar la opción.

---

## Sonido

**En estudio** (roadmap, Fase 2b): un parlantito para que el Rooti se exprese
con sonido además de con la cara.

### El problema de los pines

El C3 SuperMini expone GPIO 0–10, 20 y 21, y **ya están todos usados** (ver
[Conexiones](#conexiones)). Un amplificador I2S (MAX98357A) necesita tres
pines; no entran. Hace falta **uno solo**, y se libera así:

- **CS de la pantalla a GND.** La pantalla es el único dispositivo del bus
  SPI, así que puede quedar siempre seleccionada. Libera **GPIO 20** para el
  sonido, sin perder nada. El firmware deja de manejar CS (`RK_TFT_CS -1`).

En el DevKit de 30 pines sobran pines: ahí se puede probar I2S.

### Tres opciones, de menos a más

| | Qué es | Pines | Sonido | Consumo en reposo | Costo aprox. |
|---|---|---|---|---|---|
| **Buzzer pasivo** | piezo de 12 mm por PWM, con un N-MOSFET | 1 (PWM) | pitidos y melodías simples | 0 | muy bajo |
| **PAM8302 + parlante** ✅ recomendado | amplificador clase D mono de 2,5 W con entrada analógica; el PWM (LEDC o sigma-delta) pasa por un filtro RC | 1 (PWM) | melodías con timbre y volumen reales, efectos cortos | < 1 µA con SD en bajo | bajo |
| MAX98357A + parlante | amplificador I2S con DAC | 3 (BCLK, LRC, DIN) | muestras de audio de buena calidad | ~2 µA con SD en bajo | medio |

**Recomendado para el producto: PAM8302 + parlante de 8 Ω, 0,5–1 W, de 20 a
28 mm.** Da carácter sin gastar pines ni batería, y el buzzer queda para
validar la idea en el banco con lo que haya a mano.

### Cómo se conectaría (PAM8302)

```
GPIO 20 ──[1 kΩ]──┬── A+ del PAM8302          VBAT (después del interruptor)
                  │                              │
               [10 nF]                       VIN del PAM8302
                  │                              │
                 GND ── A- del PAM8302       SD ─┴── riel de sensores (P-MOSFET)
                                           OUT+ / OUT- ── parlante 8 Ω
```

- **Alimentación desde la batería**, no desde el regulador de 3,3 V: los
  picos del parlante (hasta 300 mA) no tienen que bajar la tensión de la
  placa. El capacitor de 220–470 µF del wifi ayuda también acá.
- **SD al riel de sensores**: el amplificador sólo está prendido cuando el
  firmware prende los sensores, y en deep sleep consume nada. Para sonar
  fuera de una medición, el firmware prende el riel un momento.
- **Parlante hacia un costado o hacia abajo**, con rejilla: el agua de riego
  cae de arriba (ver [carcasas.md](carcasas.md)).

### Qué suena

Diseñado como datos, igual que las caras: cada Rooti con su "voz" (escala,
timbre, tempo) y cada evento con su motivo. Despertar del cofre, sed urgente
(una vez por episodio), riego detectado, toque, batería baja. Con silencio de
23 a 8 y volumen o silencio por Rooti desde ROOTLAB. Los sonidos se van a
poder escuchar en el emulador antes de tener hardware.

---

## Conexiones

Esta tabla es el mapa de pines. La **netlist completa** —cada red, de qué
riel cuelga, qué ancho de cinta lleva y de dónde a dónde va— se genera desde
`hardware/pcb/nucleo.json` y está en [conexiones.md](conexiones.md).
`test_placa.c` cruza las dos cosas en cada `make test`.

### ESP32-C3 SuperMini

| GPIO | Va a | Notas |
|---:|---|---|
| 0 | salida del capacitivo | ADC1 |
| 1 | divisor del riel | ADC1 |
| 2 | compuerta del P-MOSFET de sensores | LOW enciende. De arranque: alto al encender = apagado |
| 3 | salida del TTP223 | alto al tocar; despierta del deep sleep |
| 4 | SDA (AHT20, BH1750) | pull-up 4,7 kΩ a 3V3 si el módulo no la trae |
| 5 | SCL | ídem |
| 6 | SCK de la pantalla | |
| 7 | MOSI (SDA/SDI) de la pantalla | |
| 8 | DATA del DS18B20 | pull-up 4,7 kΩ **al 3V3 fijo**. De arranque: queda alto |
| 9 | botón BOOT | apretado 10 s: borra vínculo y wifi |
| 10 | DC (A0/RS) de la pantalla | |
| 20 | CS de la pantalla | |
| 21 | compuerta del N-MOSFET de la etapa de la luz de fondo | PWM 22 kHz, alto enciende. Es el TX del UART0: la luz pestañea ~50 ms al arrancar ([pcb.md](pcb.md)) |
| — | RST de la pantalla | a 3V3 con 10 kΩ; el firmware la reinicia por software |

### ESP32 DevKit 30 pines

| GPIO | Va a |
|---:|---|
| 34 | capacitivo (ADC1) |
| 35 | divisor del riel (ADC1) |
| 26 | P-MOSFET de sensores |
| 33 | TTP223 (despierta por ext0) |
| 21 / 22 | SDA / SCL |
| 18 / 23 | SCK / MOSI |
| 25 | DS18B20 |
| 0 | botón BOOT |
| 16 | DC |
| 5 | CS |
| 4 | luz de fondo (por MOSFET) |
| 17 | RST |

En el DevKit el suelo y el riel van al ADC1 (GPIO32–39): el ADC2 no anda con
el wifi prendido.

---

## Lista de compras del prototipo

Por unidad. Los precios de pantalla son los de la cotización actual.

| Cant. | Pieza | Nota |
|---:|---|---|
| 1 | ESP32-C3 SuperMini | o un ESP32 DevKit para el banco |
| 1 | TFT 2,2" ILI9341 240×320 SPI, 9 pines | la que entra en `J_TFT`. La de 1,44" tiene 8 pines y otro orden: **no entra** en esta tira |
| 1 | Sensor capacitivo de suelo v2.0 | con TLC555 |
| 1 | SHT21 / HTU21 / Si7021 | o un AHT20; la tira de 4 pines les sirve a los dos, pero el firmware tiene que elegir |
| 1 | BH1750 (GY-302) | |
| 1 | DS18B20 sumergible con cable | opcional |
| 1 | TTP223 | |
| 1 | Módulo TP4056 USB-C con protección (6 pines) | |
| 1 | 18650 de marca + portapila | |
| 2 | AO3401 (P-MOSFET SOT-23) | riel de sensores y lado alto de la luz. El de carga compartida ya no va en el sustrato |
| 1 | AO3400 (N-MOSFET SOT-23) | etapa de la luz de fondo |
| 1 | SS34 (Schottky SMA) | **fuera del sustrato**, en el arnés de carga |
| 1 | AO3401 más | ídem, la carga compartida del arnés |
| 2 | 470 kΩ 1206 | divisor del riel |
| 1 | 4,7 kΩ 1206 | pull-up del 1-Wire |
| 3 | 100 kΩ 1206 | compuerta de Q2, purga del riel conmutado, compuerta de Q3 |
| 1 | 0 a 100 Ω 1206 | `R11`, en serie con el pin LED de la pantalla: **medir el módulo** antes de elegir el valor |
| 2 | 10 kΩ 1206 | reset de la pantalla y compuerta del P de la luz |
| 2 | 100 nF 1206 | divisor y riel conmutado |
| 1 | 100 nF 1206 | desacople de 3V3 |
| 1 | 220–470 µF 6,3 V bajo ESR | picos de wifi |
| 1 | interruptor deslizante | en la pared de la carcasa |
| 1 | sustrato impreso en PETG | [pcb.md](pcb.md) |
| — | **cinta de cobre de 5 mm** | un solo rollo: ninguna canaleta pide más ancho ([pcb.md](pcb.md), "La cinta manda") |
| — | cable de silicona AWG30 | 25 puentes |
| 4 | tornillos M2 × 8 | sustrato a carcasa |
| 8 | tiras de pines macho 2,54 mm | dos de 8 para el ESP32, y una por módulo |

Si los módulos de I2C **no** traen sus pull-ups (casi todos los traen), dos
4,7 kΩ más, soldadas entre los bornes `SCL`/`SDA` y el `VCC` de su propio
grupo.
| | **Sonido (opcional, Fase 2b)** | |
| 1 | buzzer pasivo 12 mm | para probar en el banco |
| 1 | PAM8302 (módulo) | amplificador clase D mono |
| 1 | parlante 8 Ω 0,5–1 W, 20–28 mm | |
| 1 | 1 kΩ + 10 nF | filtro del PWM |

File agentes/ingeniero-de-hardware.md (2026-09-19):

# El ingeniero de hardware de ROOTKIT

Este archivo es tu instrucción entera. Arrancás sin contexto: todo lo que
necesitás saber del proyecto está acá o en los archivos que se nombran. Leelo
completo antes de tocar nada.

---

## Quién sos y qué tenés que entregar

Sos el ingeniero de hardware de **ROOTKIT**, una maceta inteligente con
sensores y una pantallita que muestra la cara de un personaje. Tu trabajo es
llevar el producto de "módulos sueltos en una protoboard" a **algo que se
arma igual cada vez**. Tres entregables:

1. **La PCB**, hecha a mano de una forma particular: el **sustrato se imprime
   en 3D** (FDM) con **canaletas** donde van las pistas, y las pistas son
   **cinta de cobre** pegada en esas canaletas. Los módulos (el ESP32, la
   pantalla, los sensores, el cargador) se montan sobre ese sustrato.
2. **El diagrama de conexiones completo** para armar el producto físico:
   cada red, cada cable, de dónde a dónde, qué va a qué tensión, qué va
   conmutado y qué no, y en qué orden se arma y se prueba.
3. **La guía de armado y prueba**, paso a paso, para que otra persona (o
   Iñaki dentro de seis meses) arme una unidad sin preguntar, con los
   controles de multímetro en cada etapa y el primer encendido seguro.

Todo como **fuente editable y verificable**, no como dibujos sueltos: el
proyecto entero trabaja así (las caras de los personajes, por ejemplo, son
una tabla de parámetros que se ajusta sin tocar la lógica). Ver "Cómo se
trabaja acá", abajo.

---

## El proyecto, en lo que te toca

- **ROOTKIT** es el aparato (hardware + firmware). **ROOTLAB** es la app y la
  nube. Los personajes son los **Rooties** (singular **Rooti**): Brote,
  Musgo, Pinchito, Bulbo y Champi. Cada uno tiene su **carcasa** impresa en
  3D, que es su cuerpo; la pantalla sólo pone la cara.
- La pantalla muestra **dos cosas en toda su vida: un QR (para vincular) y
  los ojos**. Nada de números: las métricas viven en la app.
- El aparato mide la planta, decide solo cómo se siente (sed, frío, poca
  luz...), pone esa cara, y le cuenta todo a la nube por wifi cada tanto. Vive
  a batería meses, durmiendo casi todo el tiempo.
- Dos repositorios en `C:\Users\ifbar\Documents\`:
  - **`rootkit`** (GitHub `ifbotech/root-kit`): firmware, hardware, carcasas
    y su documentación. **Todo tu trabajo va acá.**
  - **`root-lab`** (GitHub `ifbotech/root-lab`): la app y la nube. No lo
    necesitás tocar.
- Lo que tenés que leer antes de diseñar, en este orden:
  1. `docs/hardware.md` — la referencia de hardware actual.
  2. `docs/carcasas.md` — el envolvente, la ventana de la pantalla, las
     reglas de impresión y de agua.
  3. `docs/decisiones.md`, sección **Hardware** — qué se eligió y qué se
     descartó, y por qué.
  4. `docs/roadmap.md`, **Fase 1, 2, 2b y 5** — lo pendiente de hardware.
  5. `docs/firmware.md` ("Compilar y flashear", "El banco y el producto",
     "Seguridad") y `docs/fabrica.md` (la estación de fábrica, por USB).
  6. El código que toca el hardware: `firmware/esp32/placa.h` (**la fuente
     de verdad de los pines**), `sensores_hw.cpp`, `energia.cpp`,
     `pantalla.cpp`, `portal.cpp`, y `firmware/platformio.ini`.

---

## El hardware completo

### 1. El cerebro

**Producto: ESP32-C3 SuperMini.** Banco de pruebas: ESP32 DevKit de 30
pines. El firmware compila para las dos (`pio run -e c3-144` y
`pio run -e devkit-144`).

| | ESP32-C3 SuperMini (producto) | ESP32 DevKit 30 pines (banco) |
|---|---|---|
| Tamaño | **22,5 × 18 × 4 mm**, antena cerámica en un borde | 51 × 28 mm |
| CPU | RISC-V 160 MHz, 1 núcleo, sin FPU | Xtensa 240 MHz, 2 núcleos |
| Regulador | ME6211, ~40 µA en reposo | AMS1117, ~5 mA en reposo |
| Deep sleep de la placa | **~50 µA** sin el LED de encendido | 6–10 mA (inservible a batería) |
| USB | nativo del chip (USB-C, datos y 5 V) | conversor CP2102/CH340 |
| Pines expuestos | GPIO 0–10, 20, 21, más 5V, 3V3, GND | ~25 útiles |

Lo que el C3 impone:

- **Sólo GPIO 0–5 despiertan del deep sleep.** El toque (GPIO3) está ahí.
- **Pines de arranque: GPIO 2, 8 y 9.** Al encender tienen que estar en
  alto (9 es el botón BOOT: apretado al encender = modo descarga). El mapa los
  usa para cosas que naturalmente están en alto.
- **ADC: sólo el ADC1 anda con el wifi prendido.** Los dos analógicos (suelo
  y riel) van a GPIO0 y GPIO1. Atenuación 11 dB, 12 bits
  (`sensores_hw.cpp`). En el C3, a 11 dB, la lectura es confiable hasta unos
  2,5 V: medí dónde cae la salida del capacitivo seco.
- **Los 13 GPIO están todos usados.** Cualquier función nueva necesita
  liberar uno (ver "Sonido").
- Algunas SuperMini traen un **LED rojo de encendido** fijo (1–3 mA: se
  desuelda o se corta su pista) y un **LED azul en GPIO8**, que en este mapa
  es la línea 1-Wire: va a parpadear con la sonda. Verificalo en la placa que
  llegue.
- **GPIO20/21 son el UART0 (RX/TX)** del chip. La ROM escribe el log de
  arranque por GPIO21, que acá es la luz de fondo: puede parpadear al
  encender. Observalo; si molesta, se documenta o se resuelve en hardware.

### 2. Las dos pantallas

**La del producto: TFT 1,44" 128 × 128 IPS, controlador ST7735S, SPI.**

| | |
|---|---|
| Módulo | **28 × 37 mm**, PCB ~1,6 mm; header de 8 pines, en general rotulado `GND VCC SCL SDA RES DC CS BL` (confirmalo con el módulo que llegue) |
| Área activa | **25,9 × 25,9 mm** |
| Controlador | ST7735S, memoria 132 × 162: casi todos los lotes necesitan corrimiento (`RK_TFT_OFS_X=2`, `RK_TFT_OFS_Y=1`), y a veces `RK_TFT_BGR` o `RK_TFT_INVERT`, todo desde `platformio.ini` |
| Bus | SPI modo 0, **escritura a 40 MHz** (`pantalla.cpp`, `cfg.freq_write`). Sin lectura (MISO no se usa) |
| Alimentación | VCC a 3V3 |
| Luz de fondo | 15–30 mA, **por PWM a 22 kHz** desde GPIO21, **nunca directo al GPIO** |
| Reset | RES a 3V3 con 10 kΩ; el firmware la reinicia por software |
| Dormida | el firmware manda el panel a sleep antes del deep sleep |

La ventana de la carcasa (de `docs/carcasas.md`): el panel entra **desde
atrás** y apoya en un marco; abertura de **26,5 a 27,5 mm** de lado,
**2,2 mm** de profundidad al vidrio, marco de apoyo de 1,5 mm por lado,
bisel a 45° hacia afuera. Ante la duda, la ventana 0,5 mm más arriba (un
recorte arriba se come la frente; abajo, la boca).

> **A verificar con el módulo en la mano: cómo es el pin BL.**
> `hardware.md` dice "MOSFET N (AO3400) con el GPIO a la compuerta". Eso
> sirve si el LED de la luz de fondo tiene su cátodo accesible o si BL entra
> a un transistor del propio módulo. En muchos módulos de 1,44", **BL es el
> ánodo del LED** (a través de una resistencia): entonces hay que conmutar
> **del lado alto** (P-MOSFET o un par de transistores), no del lado de masa.
> Medilo y diseñá según lo que haya; que el documento quede con la verdad.

**La otra: TFT 2,2" 240 × 320, controlador ILI9341, SPI ("la Prime").** Fue
la del primer prototipo. **Se retiró en el firmware 0.6.0**: existía para
mostrar un personaje grande y un tablero, y cuando las métricas se mudaron a
la app y el personaje quedó en una cara, costaba el doble para mostrar lo
mismo más grande. Las cinco carcasas son para la de 1,44". Usaba **los mismos
pines** (SCK 6, MOSI 7, DC 10, CS 20, BL 21, reset por software). Volver a
soportarla es agregar su bloque en `placa.h` (`RK_PANEL_ILI9341_240`) y su
clase en `pantalla.cpp`: el motor gráfico ya escala al lado corto del panel.
**No la metas en el producto por tu cuenta.** Si Iñaki quiere un aparato con
la de 2,2" (otra carcasa, otro producto), se diseña como variante, con el
mismo sustrato y otra ventana.

### 3. Los sensores

| Magnitud | Sensor | Interfaz / pin (C3) | De qué riel | Notas |
|---|---|---|---|---|
| Humedad de la tierra | **Capacitivo v2.0** | analógico, **GPIO0** | **conmutado** | ~5 mA encendido. **98 × 23 × 1,5 mm**, sale por abajo. **Tiene que tener chip TLC555** (el NE555 no arranca a 3,3 V). Sellar los bordes y el circuito (epoxi o esmalte). Se calibra por unidad desde la app |
| Temperatura y humedad del aire | **AHT20** (o AHT21) | I2C `0x38`, SDA **4** / SCL **5**, 100 kHz | **3V3 fijo** | 0,25 µA dormido. Alternativa SHT40 (`0x44`) |
| Luz | **BH1750** (GY-302) | I2C `0x23`, mismo bus | **3V3 fijo** | Lux reales hasta 54.612. Necesita **ver la luz**: ventana translúcida hacia el frente o un costado |
| Temperatura de la tierra | **DS18B20** sumergible (opcional) | 1-Wire, **GPIO8**, pull-up 4,7 kΩ | **conmutado** | Resolución 10 bits, 188 ms por medición |
| Toque | **TTP223** | digital, **GPIO3** (despierta) | **3V3 fijo** | Alto al tocar. Funciona a través de 2–3 mm de plástico; la sensibilidad se ajusta con su capacitor Cs |
| Batería y USB | divisor **470 kΩ / 470 kΩ + 100 nF** | analógico, **GPIO1** | — | Gasta 4 µA. Enchufado, el riel da ~4,6 V; el firmware sabe que hay USB por encima de 4,35 V |
| Borrar todo | **botón BOOT** de la placa | **GPIO9** | — | Apretado 10 s: borra vínculo y wifi |

Pull-ups de I2C de 4,7 kΩ a 3V3 si los módulos no las traen (la mayoría
sí: no dupliques de más).

**Por qué AHT20 y BH1750 van a 3V3 fijo y no conmutados:** el firmware los
configura al arrancar y les manda la orden de medir en el mismo instante en
que prende el riel de sensores (`sensores_hw.cpp`). Si estuvieran
conmutados, no llegarían a despertar. Si querés conmutarlos, es un cambio de
firmware también (esperar su tiempo de arranque), no sólo de cables.

**La secuencia de una medición** (`sensores_leer`): GPIO2 en bajo (prende el
riel) → orden de medir al AHT20 y al BH1750 → 180 ms → 9 lecturas del
capacitivo cada 4 ms → DS18B20 (200 ms) → GPIO2 en alto (apaga) → lectura del
divisor del riel. ~400 ms en total, unas 250 nAh.

> **A verificar: el pull-up del 1-Wire.** Si la sonda va en el riel
> conmutado pero su pull-up de 4,7 kΩ va a 3V3 fijo, con el riel apagado la
> línea de datos puede alimentar a la sonda por su pin de datos. Lo prolijo
> es que el pull-up salga del mismo riel conmutado. Medí la corriente en
> reposo con y sin sonda.

Sensores para más adelante (no los metas, pero no les cierres la puerta si
no cuesta nada): VEML7700 (luz de sol pleno), LIS3DH (reemplazaría al
TTP223 con despertar por movimiento), LTR390 (UV), capacitivo de nivel para
el plato.

**Prohibidos**, con razones en `hardware.md`: humedad de suelo **resistiva**
(FC-28 / YL-69: se corroe en semanas y electroliza la tierra), **DHT11/DHT22**
(imprecisos y frágiles), **LDR** (no da lux sin calibrar cada unidad).

### 4. Las baterías y la energía

**La celda del producto: una 18650** de 2600–3500 mAh **de marca** (Samsung,
LG, Molicel, Sony; las "9900 mAh" traen 800 y a veces arena), en portapilas
de **75 × 21 × 19 mm**, **parada, abajo**: es la pieza más pesada y hace de
lastre para que la maceta no se vuelque. **Su compartimento no comparte
volumen con la electrónica** (un 18650 mojado es un incidente).

**La alternativa: LiPo plana** de 1000–1200 mAh (103450 o 603450) con su
plaquita de protección, si algún día hay una carcasa más chica. El firmware
no cambia.

**El circuito actual** (`hardware.md`, "Batería y carga"):

```
                 USB-C 5 V (del módulo cargador)
                     │
             ┌───────┴────────┐
             │  TP4056 + DW01A │  módulo "con protección", 6 pines
             │   IN+     B+ ───┼──── + celda
             │   IN-     B- ───┼──── - celda
             │          OUT+ ──┼──┐
             └────────────────┘  │   (batería protegida)
                     │            │
      5 V ──SS34──┬──┘            │
                  │   AO3401 (P)  │
                  ├──── S   D ────┘   (fuente del lado de la carga,
                  │     G              drenador del lado de la celda)
                  │     └── al 5 V del USB, con 100 kΩ a GND
                  │
                  ├── interruptor ── pin 5V de la SuperMini (regula a 3,3 V)
                  │
                  └── 470 kΩ ──┬── GPIO1 (ADC)
                               ├── 470 kΩ ── GND
                               └── 100 nF ── GND
```

- **Carga compartida (AO3401 + SS34):** enchufado, el aparato come del USB
  por el Schottky y el TP4056 sólo carga la celda; sin esto la carga no
  termina nunca y la celda se sobrecarga lento.
- **Corriente de carga** con `RPROG` del módulo: 1,2 kΩ = 1 A (18650),
  2 kΩ = 580 mA (LiPo de 1000 mAh), 3 kΩ = 400 mA.
- **Regulación:** la SuperMini entra por su pin 5V y su ME6211 baja a 3,3 V.
  Anda con la celda por encima de ~3,5 V; debajo, los picos de wifi (~350 mA)
  pueden tirarla. El firmware corta a **3,15 V** (`RK_BATT_CUTOFF_MV`), avisa
  a 3,45 V, y sólo hace una actualización por aire arriba de **3,7 V**; la
  protección DW01A corta a 2,4 V. Para aprovechar la celda entera, en la
  versión de producción: buck-boost **TPS63802** (3,3 V estables de 2,7 a
  4,2 V, 11 µA en reposo) o LDO **RT9080** (2 µA, 600 mA).
- **Capacitor de 220–470 µF, bajo ESR**, cerca del 3V3, para los picos de
  transmisión.
- **Interruptor** entre la carga compartida y la placa, para despachar el
  aparato apagado.
- **El riel conmutado de sensores:** P-MOSFET **AO3401** del lado alto, con
  la compuerta a **GPIO2** (bajo = prendido). Necesita **100 kΩ entre
  compuerta y fuente** para quedar apagado mientras el chip duerme o arranca
  (y así GPIO2, que es de arranque, queda en alto).
- **La compuerta de la luz de fondo** necesita su resistencia a masa (100 kΩ)
  si es un N-MOSFET, para que no prenda sola en el deep sleep.

**Cuánto dura** (estimación de `hardware.md` y `nodo/power.c`, **a medir**
en la Fase 2 con un medidor USB o un PPK2):

| Consumo por día | |
|---|---:|
| Deep sleep (~0,15 mA con el panel dormido) | 3,6 mAh |
| Mediciones adaptativas (cada 2–30 min) | 1,5 mAh |
| ~30 envíos a la nube (wifi + TLS, ~1 s a 100 mA) | 2,3 mAh |
| Pantalla al tocar: 20 veces × 20 s | 5,6 mAh |
| **Total** | **~13 mAh** |
| **Con una 18650 de 3000 mAh (20 % de margen)** | **~6 meses** |

Cada microamperio en reposo son días de batería: el objetivo del sustrato es
no agregar ninguna fuga (una pista sucia de flux, humedad entre dos pistas de
cinta, un pull-up mal puesto).

> **Una tensión en la documentación que tenés que resolver con Iñaki.**
> `decisiones.md` dice que con la 18650 reemplazable por el usuario
> "desaparecen el TP4056 y el conector USB". `hardware.md`, que es más nuevo,
> tiene carga por USB-C, y el firmware la usa (detecta el USB por el riel).
> Diseñá sobre `hardware.md`, y dejá la pregunta planteada con tu
> recomendación.

> **Riesgo eléctrico a verificar antes del primer armado: dos USB y la
> batería.** La SuperMini tiene su propio USB-C (es por donde se flashea y por
> donde trabaja la estación de fábrica, `tools/fabrica.py`), y el TP4056
> tiene otro. Si el pin 5V de la SuperMini está unido a su VBUS sin un diodo
> (fijate en la placa que llegue: muchas lo están), al enchufar el USB de la
> SuperMini con la celda conectada y el interruptor prendido, esos 5 V
> aparecen en el nodo de carga. Con el USB del cargador desenchufado, la
> compuerta del AO3401 queda en bajo, el MOSFET conduce, y **la celda recibe
> 5 V sin control de carga**. Diseñá para que eso no pueda pasar (un diodo o
> un "diodo ideal" entre el sistema y el pin 5V, flashear siempre con el
> interruptor apagado y un aviso físico, o un único USB-C que haga las dos
> cosas) y dejalo escrito en la guía de armado. **Nunca** pruebes esto con
> una celda de verdad: fuente de laboratorio con límite de corriente.

### 5. Sonido (postergado, Fase 2b)

No es parte de este trabajo, pero el sustrato no tiene que impedirlo. Lo
recomendado: **PAM8302** (clase D mono, entrada analógica) + parlante de 8 Ω,
0,5–1 W, 20–28 mm, alimentado de la batería (no del 3V3), con SD al riel
conmutado. Pin: **GPIO20**, que se libera **atando CS de la pantalla a GND**
(es el único dispositivo del bus SPI). Si te cuesta poco, dejá los pads y el
lugar. Parlante hacia un costado o hacia abajo, nunca hacia arriba.

### 6. Mapas de pines

**ESP32-C3 SuperMini** (`placa.h`, `RK_PLACA_C3`):

| GPIO | Va a | Notas |
|---:|---|---|
| 0 | salida del capacitivo | ADC1 |
| 1 | divisor del riel | ADC1 |
| 2 | compuerta del P-MOSFET de sensores | bajo = prendido. De arranque: 100 kΩ a fuente |
| 3 | salida del TTP223 | alto al tocar; despierta |
| 4 | SDA | AHT20, BH1750 |
| 5 | SCL | ídem |
| 6 | SCK de la pantalla | |
| 7 | MOSI (SDA) de la pantalla | |
| 8 | DATA del DS18B20 | pull-up 4,7 kΩ. De arranque; LED azul en algunas placas |
| 9 | botón BOOT | 10 s: borra vínculo y wifi. De arranque |
| 10 | DC de la pantalla | |
| 20 | CS de la pantalla | se libera atando CS a GND (sonido) |
| 21 | luz de fondo, por MOSFET | PWM 22 kHz. Es UART0 TX |
| — | RES de la pantalla | a 3V3 con 10 kΩ |

**ESP32 DevKit 30 pines** (`RK_PLACA_DEVKIT`, el banco): suelo 34, riel 35,
sensores 26, toque 33, SDA 21, SCL 22, SCK 18, MOSI 23, DS18B20 25, BOOT 0,
DC 16, CS 5, luz de fondo 4, RST 17.

### 7. Lista de materiales del prototipo (por unidad)

ESP32-C3 SuperMini · TFT 1,44" ST7735S · capacitivo v2.0 (TLC555) · AHT20 ·
BH1750 (GY-302) · DS18B20 sumergible (opcional) · TTP223 · módulo TP4056
USB-C con protección (6 pines) · 18650 de marca + portapilas · 2 × AO3401
(carga compartida y sensores) · 1 × AO3400 (luz de fondo; ver el aviso del
pin BL) · SS34 · 2 × 470 kΩ · 2 × 4,7 kΩ · 2 × 100 kΩ · 10 kΩ · 100 nF ·
220–470 µF 6,3 V bajo ESR · interruptor deslizante. Sonido, más adelante:
PAM8302, parlante 8 Ω, 1 kΩ + 10 nF.

---

## La PCB impresa con cinta de cobre

Es tu diseño: acá van las restricciones que ya existen y lo que conviene
tener en cuenta. Probá con piezas de prueba antes de decidir los números.

**El sustrato**

- **PETG** (o ASA), no PLA: el PLA se ablanda a ~60 °C, que es poco para
  soldar encima y para una maceta al sol de una ventana.
- Las mismas reglas que las carcasas (`docs/carcasas.md`): **sin soportes,
  voladizos de 45° como máximo, base plana**, boquilla de 0,4 mm, pared
  mínima 1,6 mm, encastre a presión 0,20 mm por cara, poste para tornillo M2
  de Ø1,7 mm, paso de cable de Ø4 mm como mínimo. Las canaletas en la cara
  de arriba de impresión.
- **Un solo sustrato para los cinco Rooties.** Las carcasas son distintas
  (y su forma es decisión de arte: Rocío las define; vos no las rediseñás),
  pero lo de adentro es igual. Lo sano es un **núcleo común** —sustrato con
  módulos— con una interfaz fija de montaje, y que cada carcasa se adapte a
  él. Si ves que no entra en alguna silueta, decilo con números.

**Las pistas**

- Cinta de cobre de ~0,035–0,07 mm; ancho y profundidad de canaleta los
  definís con pruebas (una canaleta apenas más ancha que la cinta, poco
  profunda, sirve de guía y de separación). Paredes entre canaletas de al
  menos dos extrusiones.
- **Anchos por corriente:** las de potencia (celda → interruptor → 5V, masa,
  la luz de fondo) bien anchas; las de señal pueden ser finas. La masa, lo
  más continua posible.
- **Cruces:** una cara con puentes de cable aislado, o dos caras con
  pasantes. Elegí lo que se arme igual cada vez.
- **Uniones:** el adhesivo "conductor" de la cinta no es confiable entre
  tramos: **soldá cada unión**. Probá estaño de baja temperatura (Sn42Bi58,
  138 °C), flux, y toques cortos; o remaches/ojalillos huecos en los pasantes,
  que reparten el calor y dan firmeza mecánica. Decidí con una pieza de
  prueba.
- **SPI a 40 MHz:** SCK y MOSI cortos y con la masa al lado. Si la pantalla
  muestra basura, bajar `cfg.freq_write` en `pantalla.cpp` es una opción
  (si hace falta, proponé un flag en `platformio.ini`).
- **Antena:** nada de cobre a menos de ~10 mm del borde de la antena
  cerámica de la SuperMini; la antena hacia afuera, lejos de la celda y de la
  tierra húmeda (en la Fase 2 se mide el RSSI dentro de la carcasa).
- **Humedad y corrosión:** la cinta se oxida y la maceta se riega. Después
  de probar, barniz de protección (acrílico, o máscara UV). Pensá dónde
  queda cada pista respecto de por dónde corre el agua.
- **Fugas:** entre dos pistas húmedas o con restos de flux pasan
  microamperios. Limpiá el flux y medí el reposo.

**Dónde va cada cosa** (lo que imponen el agua y los sensores):

- La **pantalla** detrás de la ventana, a 2,2 mm del frente.
- El **capacitivo** sale por abajo, con la junta abajo y el cable haciendo
  panza para que el agua gotee antes de llegar a la placa.
- La **18650** abajo, parada, en su compartimento.
- El **BH1750** mirando la luz por una ventana translúcida al frente o a un
  costado (**ninguna abertura hacia arriba**).
- El **AHT20** lejos del calor del ESP32 y del TP4056, con ventilación
  que no mire hacia arriba.
- El **TTP223** pegado a la cara interna de la carcasa donde se toca.
- El **USB** (de carga y el de la SuperMini) accesible, y pensado para el
  agua.

---

## Cómo se trabaja acá

- **Autonomía y trabajo completo.** Iñaki pide que termines el trabajo
  entero —diseño, fuentes, pruebas y documentación— sin frenar a consultar a
  mitad de camino. Las decisiones de producto (un USB o dos, celda
  reemplazable o no, la pantalla de 2,2") las planteás con tu recomendación
  y seguís con ella; las anotás para que él decida después.
- **Fuente editable, no dibujos.** El sustrato en **OpenSCAD**
  (`C:\Program Files\OpenSCAD\openscad.exe`, se puede usar por línea de
  comandos para exportar STL), paramétrico: las posiciones de los módulos,
  las redes y los recorridos de las pistas en **un archivo de datos**, y el
  modelo generado a partir de eso. Del mismo dato sale: el STL del sustrato,
  una **plantilla 1:1 en SVG** para imprimir en papel y cortar la cinta, y el
  diagrama de conexiones.
- **Probado como el resto del proyecto.** Una lista de redes (netlist) como
  dato, y una prueba que verifique, por lo menos: que cada GPIO de
  `placa.h` está en la red que corresponde; que no hay dos redes que se
  toquen (distancia mínima entre canaletas); que los analógicos están en
  ADC1 y el toque en GPIO 0–5; los estados de los pines de arranque; el ancho
  mínimo de las pistas de potencia; la zona libre de la antena. Que corra con
  `make test` o en el CI (`.github/workflows/ci.yml`), y que el CI siga en
  verde.
- **Una sola verdad de los pines: `firmware/esp32/placa.h`.** Si un pin
  cambia, cambia en `placa.h`, en `docs/hardware.md` y en tu netlist en el
  mismo commit, y las pruebas del firmware tienen que seguir pasando (`make
  test` en WSL, y `pio run -e c3-144 -e devkit-144`).
- **Documentación:** una página nueva `docs/pcb.md` (el sustrato, la cinta,
  cómo se imprime y se arma, qué se probó) y `docs/armado.md` (la guía paso a
  paso con los controles), y `docs/hardware.md` al día. En español
  rioplatense, con el tono de los otros documentos: frases cortas, el porqué
  de cada decisión, números concretos.
- **Commits en `rootkit`**, en español, que digan qué cambia y por qué.
- **No** cambies el aspecto de las carcasas (es de Rocío), no toques
  `root-lab` ni el servidor, y no hagas nada irreversible con una placa
  (quemar eFuses, flash encryption: eso es de la estación de fábrica, antes
  de vender).

### El entorno

- Windows 11. La consola es PowerShell o Git Bash. Todo el firmware se
  compila y se prueba en **WSL, Ubuntu 24.04**:
  `wsl.exe -d Ubuntu-24.04 -- bash -lc "cd /mnt/c/Users/ifbar/Documents/rootkit/firmware && make test"`
  (si falla por la ruta de `build/`, copiá la carpeta a `/tmp` y corré ahí).
- PlatformIO: `%USERPROFILE%\.platformio\penv\Scripts\pio.exe run -e c3-144 -e devkit-144`
  desde `firmware/`.
- Python 3.14 en Windows y `python3` en WSL.
- Al editar archivos con barras invertidas (código C, rutas de Windows),
  usá la herramienta de edición de archivos: los heredocs por la consola se
  comen las `\`.

---

## Cómo sabés que terminaste

- [ ] Un sustrato en OpenSCAD, paramétrico, que se imprime sin soportes, con
      el STL exportado y la plantilla 1:1 de la cinta.
- [ ] La netlist como dato, con su prueba corriendo en `make test` o el CI.
- [ ] El diagrama de conexiones completo: cada red, de qué riel cuelga cada
      cosa (3V3 fijo, conmutado, 5V, batería), valores y encapsulados.
- [ ] Resueltos (en el diseño o como pregunta con recomendación): el pin BL
      de la pantalla, el pull-up del 1-Wire, los dos USB y la batería, la
      celda reemplazable.
- [ ] `docs/pcb.md` y `docs/armado.md` nuevos, `docs/hardware.md` al día, y
      la Fase 1/2 del roadmap marcada donde corresponda.
- [ ] `make test` y las dos placas compilando, el CI en verde.
- [ ] Un informe final para Iñaki: qué diseñaste, qué probaste de verdad y
      qué quedó para probar con piezas en la mano, en orden.

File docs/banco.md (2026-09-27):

# El firmware de banco del prototipo NodeMCU

El prototipo que soldó Rocío —NodeMCU ESP32 de 38 pines, TFT de 2,2",
capacitivo, LDR y HTU21D— no corre el firmware del producto: no tiene toque,
ni batería, ni BH1750. Corre `firmware/banco/banco.cpp`, que sirve para dos
cosas a la vez:

- **probar que los sensores andan**, con las lecturas en pantalla y por el
  puerto serie, crudas y convertidas;
- **ver a Kip** con sus animaciones nuevas en el panel de verdad, reaccionando
  a esos sensores con el mismo motor de ánimo que el producto.

No hay QR, ni vínculo, ni nube: arranca directo en la cara.

## El cableado

Es el de `firmware/esp32/placa.h` (`RK_PLACA_NODEMCU38`), y
`firmware/test/test_placa_nodemcu.c` verifica que coincida pin por pin con lo
soldado.

| Qué | Pin del módulo | GPIO |
|---|---|---|
| TFT ILI9341 | CS · RESET · DC · MOSI · SCK · MISO | 5 · 4 · 2 · 23 · 18 · 19 |
| TFT | LED | a 3,3 V (siempre prendido) |
| Capacitivo v2.0 | AOUT | 34 (ADC1_CH6) |
| LDR (MH-Sensor) | AO · DO | 35 (ADC1_CH7) · 32 |
| HTU21D | SDA · SCL | 21 · 22 |
| Botón | BOOT de la placa | 0 |

Los dos analógicos están en el ADC1, que es el que sigue andando con el wifi
prendido. GPIO2 (DC del panel) es además el LED azul de la placa: titila
mientras se dibuja, y es normal.

## Flashearlo

Con la placa enchufada por USB a la compu y [PlatformIO](https://platformio.org/)
instalado (`pip install platformio`):

```bash
cd firmware
pio run -e banco-nodemcu -t upload
pio device monitor            # 115200
```

La primera vez PlatformIO baja el compilador del ESP32 y LovyanGFX: tarda
unos minutos. Si la subida no arranca ("Failed to connect"), mantener
apretado **BOOT** hasta que empiece a escribir. Si la compu no ve el puerto,
falta el driver del chip USB de la placa (CP2102 o CH340).

## Qué se ve

La cara de Kip en el medio y, en las franjas que le sobran al panel arriba y
abajo:

```
SUELO 51% (1903)          el porcentaje y la lectura cruda del ADC
LUZ 803 LX DO:0           lux aproximados de la LDR y su salida digital
          [ la cara de Kip ]
AIRE 23.4°C 55%           el HTU21D
AUTO CONTENTO             el modo y el ánimo
```

y cada segundo, por el monitor serie:

```
suelo 1903 ( 51%)  luz AO  250 mV ~  803 lx DO 0  aire 23.4 C 55%  | Banco de pruebas: HAPPY (estoy perfecta)
```

Al arrancar también escanea el I2C (tiene que aparecer `0x40 (HTU21D)`),
dice cuánta memoria hay y de qué tamaño quedó la cara: en el ESP32 clásico
el bloque de RAM contiguo más grande no alcanza para 240×240, y la cara sale
de 232×232 centrada. Cada diez segundos informa los cuadros por segundo.

## Cómo probar cada sensor

En modo **AUTO** la cara sigue a los sensores. Los umbrales son los de una
"especie de banco" (suelo 20–60 %, 15–30 °C, humedad del aire desde 30 %,
luz de 100 a 20.000 lux), elegidos para que en una mesa de trabajo, con el
capacitivo en tierra húmeda, Kip esté contento, y que cada sensor lo saque de
ahí por su lado:

| Hacé esto | Kip pone |
|---|---|
| El capacitivo al aire | sed |
| El capacitivo en un vaso de agua | se ahoga |
| Tapar la LDR | oscuro, y a los 8 segundos se duerme |
| Una linterna pegada a la LDR | sol directo |
| Un dedo sobre el HTU21D un rato | calor |
| Desenchufar el HTU21D | la franja dice `NO MIDE`, y el ánimo ignora el aire |

El motor juzga en orden: agua, temperatura, noche, luz, aire. Por eso con el
capacitivo al aire Kip tiene sed aunque tapes la LDR: la sed manda.

La noche llega en 8 segundos y no en dos horas porque el banco mide una vez
por segundo y el producto cada quince minutos: es la misma regla, "ocho
lecturas seguidas a oscuras".

## El botón y el serie

- **BOOT corto**: pasa de modo. AUTO y después los once ánimos uno por uno,
  empezando por los de las láminas de Rocío (contento, agua, calor, oscuro,
  aire seco) y siguiendo por sed, frío, sol, dormido, sin datos y
  desconectado.
- **BOOT largo**: cambia la piel (común, rara con destellos, épica con fuego).

Por el monitor serie, una letra:

| Letra | Qué hace |
|---|---|
| `a` | AUTO |
| `n` | siguiente ánimo |
| `1`–`9`, `0`, `x` | un ánimo: 1 contento, 2 agua, 3 calor, 4 oscuro, 5 aire seco, 6 sed, 7 frío, 8 sol, 9 dormido, 0 sin datos, x desconectado |
| `p` | siguiente piel |
| `e` | siguiente especie: la del banco y después las de `core/species.c` |
| `s` / `m` | calibrar el suelo SECO (sensor al aire) / MOJADO (en agua, hasta la raya) |
| `r` | volver a la calibración de fábrica del suelo |
| `i` | escanear el I2C |
| `?` | la ayuda |

La calibración del suelo queda guardada en la flash (NVS): sobrevive a un
reinicio.

## La luz es aproximada

La LDR no mide lux: mide una resistencia. `rk_ldr_lux` (`nodo/sensores.c`)
la convierte con la curva de una GL5528, y una LDR varía el doble entre
unidades. Alcanza para lo que el ánimo necesita —de noche, poca luz, sol—
pero no para comparar números con un luxómetro. Además el ADC del ESP32 no
lee por debajo de ~140 mV: con mucha luz la AO cae más abajo, la franja dice
`LUZ MUCHA` y se toma como sol.

## Si algo no se ve bien

| Síntoma | Qué tocar en `platformio.ini`, entorno `banco-nodemcu` |
|---|---|
| Kip sale azul en vez de rojo | `-DRK_TFT_BGR=1` |
| La cara sale dada vuelta | `-DRK_TFT_ROTACION=2` |
| La imagen sale con basura o rayas | `-DRK_TFT_SPI_HZ=20000000` |
| Pantalla blanca | mirar RESET (GPIO4), DC (GPIO2) y CS (GPIO5) |
| `I2C: nada` | mirar SDA/SCL y los 3,3 V del HTU21D |
| `SUELO ??` | el capacitivo desconectado o en corto: mirar AOUT y sus 3,3 V |

## Cómo se probó sin la placa

Todo lo que es C puro (la conversión de la LDR, el HTU21D con su CRC, el
suelo, el ánimo, la cara) se prueba con `make test`. El `.cpp` del banco se
compiló y se corrió entero en la PC contra imitaciones de Arduino, Wire y
LovyanGFX, con sensores simulados, y de ahí salen las lecturas y las
pantallas de arriba. Lo que eso NO prueba es el hardware: los tiempos reales
del SPI, el ADC de verdad y el cableado. Eso lo dice el primer encendido.

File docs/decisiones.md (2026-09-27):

# Registro de decisiones

Las decisiones cerradas y por qué, para no volver a discutirlas.
El análisis competitivo completo está en el dossier.

Las decisiones que se **revisaron** quedan acá abajo, en su propia sección, con
lo que las tumbó. Borrarlas sería perder la parte más útil del registro: saber
por qué algo que parecía correcto dejó de serlo.

## Arquitectura

**Un ROOTKIT es un aparato en una maceta.** Una placa, sus sensores y una
carcasa impresa en 3D que es el cuerpo de su Rooti. Hay cinco, botánicos:
Brote, Musgo, Pinchito, Bulbo y Champi. La figura dice cuál es; el cofre de
la app, de qué colores despierta.

**La variedad es física; la cara es digital.** Lo único que se diseña en
pixeles es la cara. Lo que cambia entre un modelo y otro es la carcasa
impresa: su cresta, su pelo, su visera. Es mejor reparto de esfuerzo que
dibujar cuerpos — imprimir una carcasa cuesta filamento y unas horas de
modelado, dibujar y animar un cuerpo cuesta semanas. Y una cara sola en
128×128 tiene muchos más pixeles por rasgo que un cuerpo entero.

**El ánimo dice qué siente; la persona dice cómo lo muestra.** `core/mood.c`
decide el estado a partir de la planta y `core/persona.c` decide cómo se
dibuja ese estado. Cinco Rooties por tres pieles por once ánimos son ciento
sesenta y cinco caras, y salen todas del mismo código porque la cara es
procedural.

**La especie y la carcasa son ejes independientes.** La especie decide los
umbrales; la carcasa decide la cara. Ninguna deriva de la otra, y esa
independencia es el producto: la misma planta con dos carcasas se ve distinta,
y la misma carcasa cuida cualquier planta.

**Las métricas viven en la app.** El aparato sólo dibuja una cara: ni números,
ni barras, ni nombre. Sacarle la interfaz es además lo que hace que la carcasa
mande — una pantalla llena de barras compite con el objeto, una cara lo
completa.

**La figura define el Rooti; el cofre, la piel.** Qué Rooti es lo decide la
figura que la persona tiene en la mano. El cofre de la app sortea sólo la
piel: común (70 %), rara (25 %) o épica (5 %). Es cosmético, gratis, una vez
por vínculo, con probabilidades publicadas antes de abrir y nada que comprar
para cambiarlas: no es una caja de botín, que es azar **pago**.

**Lo que se gana cuidando la planta es cómo se ve, no quién es.** Los días
sanos desbloquean capas cosméticas sobre la cara: brillos a los 30, aura a los
90, corona a los 180, que se suman a los adornos de la piel. Y en la app, las
gotas de rocío de la mascota se ganan con la planta cómoda, no abriendo la
app.

## Hardware

**La PCB impresa es una protoboard, no el chasis (v3.0).** Hasta la v2.0 el
sustrato hacía dos trabajos: interconectar y sostener. Tenía la ventana por
donde asomaba la pantalla, el bolsillo del cargador y el hueco del USB. Eso
ataba su tamaño y su forma a decisiones de carcasa que todavía no están
tomadas, y ponía un agujero de 28 × 38 mm en el medio de la placa por el que
no podía pasar ninguna pista. Desde la v3.0 el sustrato **sólo interconecta**:
cada módulo se clava por su tira de pines y después vive donde la carcasa
quiera. Se pagó con que la carcasa ahora tiene que sostener la pantalla por su
cuenta, y se cobró en las tres cosas que importaban: el montaje es clavar ocho
módulos, los puentes de cable bajaron de 38 a 24, y la placa dejó de depender
de una carcasa que no existe.

**La cinta de cobre es de 5 mm y eso fija el ancho de las pistas.** Una
canaleta de ancho `a` y profundidad `p` necesita `a + 2p` de cinta para
forrarse. Con la profundidad en 1,2 mm —que es lo que hace que la estampadora
casi corte la cinta contra el borde— el ancho máximo de canaleta es 2,6 mm. Se
eligió respetarlo en vez de agrandar la canaleta y usar dos rollos: ahora
**todo sale de un solo rollo de 5 mm**. Se puede porque el cargador salió del
sustrato y por la placa ya no pasa un ampere sino los 350 mA de pico del wifi,
que sobre 2,2 mm de cinta caen 5 mV.

**La etapa de carga salió del sustrato.** El TP4056, el SS34, el MOSFET de
carga compartida y el interruptor viven ahora en un arnés que se arma sobre el
propio módulo cargador y entra a la placa por dos pines. No cambió ni un
componente: cambió dónde vive. Es lo que permitió bajar los rieles de 4 a
2,2 mm, y de paso saca los 5 V y el ampere de una placa que se arma a mano.

**Los tres números del proceso están medidos, no calculados (v3.1).** La
profundidad de la canaleta (1,2 mm), la luz lateral de la nervadura (0,20 mm)
y el diámetro del agujero de una tira de pines (1,7 mm) salieron de imprimir
un cupón de prueba con las tres variables barridas, no de una cuenta. Dos de
los tres contradijeron lo que decía el papel: la luz estaba en 0,15, que
agarra y no deja bajar la pieza; y el agujero en 1,4, que sobre el papel le
deja medio milímetro de aire al pin de 0,64 mm y en la práctica lo dejó pasar
en cinco de ocho intentos, porque **un agujero impreso sale dos o tres
décimas más chico que el dibujado**. La lección es del método, no de los
números: en la parte del proyecto que toca plástico y cobre, el papel propone
y la impresora dispone, y por eso el cupón existe y se vuelve a correr cada
vez que cambia la impresora o el material.

Como efecto colateral, la pared mínima entre dos agujeros bajó de 1,1 a
0,8 mm, que es la misma que hay entre dos canaletas desde la v1.0. Ahora hay
**un solo número de pared mínima** en todo el diseño en vez de dos que decían
cosas distintas.

**El estampador marca; la lija corta.** Una matriz de corte para 0,06 mm de
cobre trabaja con unas micras de luz entre punzón y matriz; una boquilla de
0,6 mm da 0,15 mm, cincuenta veces más. Así que la nervadura hunde la cinta y
la marca contra el borde de la canaleta, y lo que separa las pistas de verdad
es **lijar la cara** al ras después de prensar. Se eligió eso en vez de
recortar canaleta por canaleta con bisturí, que era el paso más largo y el más
dependiente del pulso de todo el armado.

**Pantalla: TFT 1,44" 128×128 IPS, ST7735, SPI.** Área activa 25,9 × 25,9 mm.
ARS 9.160. Es IPS, tiene el pin de retroiluminación accesible para PWM, y su
controlador tiene librería madura. Cinco GPIO para la pantalla, que es lo que
permite que entren los sensores en un C3.

**Se descartó el Prime de 2,2 pulgadas.** Existía para mostrar al simbionte
grande y para tener el tablero. Cuando las métricas se mudaron a la app y el
bicho se redujo a una cara, esa pantalla se quedó sin trabajo: costaba el
doble para mostrar lo mismo más grande. Ver la sección de decisiones revisadas.

**Descartada la shield de 2,4" para Arduino UNO (ARS 13.069).** Es paralela de
8 bits: trece GPIO sólo para la pantalla, contra cinco de la SPI. Un C3
SuperMini tiene diez pines útiles. Además es de 5 V —lleva conversores de nivel
en la placa— y el controlador es una lotería: estas shields MCUFRIEND vienen con
ILI9341, ILI9325, R61505 o S6D0154 según el día. Para un proyecto suelto es un
detalle; para cien unidades vendidas es descalificante. Y no gana nada a cambio:
su paso de pixel de 0,158 mm da una criatura de 22,8 mm, prácticamente la misma.

**Descartada la Guition JC3248W535 como Terminal.** Fue la elección de la
primera versión —ESP32-S3, 3,5" 320×480 IPS, táctil capacitivo— y quedó afuera
cuando el producto dejó de tener una terminal de escritorio. Cuesta ARS 69.103,
más que siete veces la pantalla actual.

**Descartada la CYD de 2.8" (ESP32-2432S028R).** Táctil resistivo — por eso
viene con stylus. Rompe el mecanismo central del producto: no se puede
acariciar al simbionte, se lo aprieta. No es cuestión de precio.

**Descartada la Waveshare ESP32-S3-RLCD-4.2.** Panel reflectivo sin
retroiluminación, descrito por el fabricante como "experiencia tipo papel
electrónico": es la misma renuncia que hizo PlantSenso con su E-Ink, justo en el
terreno donde ROOTKIT gana.

**Sensores: capacitivo v2.0 + AHT21 + BH1750, en cada aparato.** Uno con menos
sensores sería uno que no puede evaluarse solo, y eso rompe la regla central
del sistema. El AHT21 en particular no se comparte: una maceta interior y una
de balcón son microclimas distintos.

**La pantalla se enciende por rato, no siempre.** Ninguna pantalla a color
sobrevive siempre encendida a batería: una IPS da entre 0,9 y 3 días. Con la
pantalla apagada salvo cuando alguien mira, el aparato vive año y medio.

**Batería 18650, no LiPo.** A precios de MercadoLibre: 18650 de 2200 mAh con
portapilas sale unos ARS 5.000 comprando de a diez — ARS 2,27 por mAh — contra
ARS 17 a 23 por mAh de cualquier LiPo chica. Es más barata en términos absolutos
que la LiPo de 300 mAh y da siete veces más capacidad. Además, si la celda es
reemplazable por el usuario desaparecen el TP4056 y el conector USB, y con ellos
un agujero menos que sellar en un aparato que vive en tierra húmeda.

**La placa del prototipo es un sustrato impreso con cinta de cobre.** No hay
PCB comprada hasta la Fase 5. El sustrato se imprime en PETG con canaletas y
las pistas son cinta de cobre soldada en cada unión. Sale del mismo dato que
la netlist y la plantilla de corte, y se verifica solo: separaciones, anchos,
conectividad, zona de antena. Detalle en [pcb.md](pcb.md).

**Un solo núcleo para los cinco Rooties.** La carcasa cambia; lo de adentro
es idéntico. El sustrato le pide a la carcasa un volumen de 68 × 104 × 45 mm
y cuatro postes M3 en posiciones fijas; el resto es libre.

**El sustrato se rutea solo (v2.0).** Las pistas dejaron de dibujarse a mano:
`tools/ruteo.py` las calcula desde la netlist y la posición de los módulos, y
`tools/pcb.py --verificar` las revisa con las mismas reglas geométricas de
antes. El motivo fue práctico —la boquilla de 0,6 obligó a agrandar todos los
agujeros y a escalonar los pads del C3, y eso solo ya manda a redibujar las
51 pistas— pero el efecto es que mover un módulo o achicar la placa pasó a
costar un comando en vez de una tarde. Con eso la placa bajó de 72 × 104 a
**62 × 92** (24 % menos) y el Musgo dejó de ser un problema de volumen.

**El DS18B20 va al riel fijo, no al conmutado.** Su pull-up de 1-Wire tiene
que sostener GPIO8 —que es pin de arranque— en alto al encender, cuando el
riel conmutado está apagado. Ponerlo en el conmutado obligaba a un pull-up en
un riel y una sonda en otro, que es justo el camino parásito que se quería
evitar. La sonda consume 1 µA en reposo: el 0,2 % del presupuesto diario. En
el riel conmutado queda sólo el capacitivo, que es el que come 5 mA.

**La luz de fondo se conmuta del lado alto.** En la mayoría de los módulos de
1,44" el pin `BL` es el ánodo del LED, y ahí un N-MOSFET del lado de masa no
hace nada. La etapa de dos transistores (N que tira de la compuerta de un P)
funciona con `BL` como ánodo y también como entrada de control, y un selector
de estaño la pasa al lado de masa si el módulo resulta ser al revés.

**El USB de la SuperMini no sale al exterior, y se flashea con el
interruptor apagado.** Con la celda puesta y el interruptor prendido, los
5 V del USB de la SuperMini pueden llegar a la celda sin control de carga. Un
diodo en serie lo resolvería a costa de 0,3 V, que a 3,5 V de celda es más de
la mitad de la carga útil; un "diodo ideal" de verdad son dos MOSFET y un
controlador, y eso es Fase 5. Mientras tanto: el orden de armado (se flashea
antes de poner la celda), el interruptor como llave, y el aviso grabado en el
plástico.

**Prohibido el FC-28 / YL-69.** Resistivo: se consume por electrólisis en 3 a 6
meses, y mide sales disueltas en vez de agua, así que fertilizar altera la
lectura. El propio aviso admite las dos cosas.

## Comunicación

*(Revisada: ver "El protocolo binario sobre ESP-NOW" abajo.)*

**Protocolo binario, no JSON.** Una trama de telemetría son 26 bytes; el mismo
contenido en JSON son unos 190. Cada byte es tiempo de radio encendida, y la
radio es cerca de la mitad del presupuesto energético del aparato.

**La configuración lleva los umbrales de la especie y el índice de la
carcasa.** Son 32 bytes contra los 18 de antes, y es lo que permite que el
aparato evalúe su propia maceta y sepa qué cara poner. No pesa en la batería:
viaja una sola vez al emparejar y cada vez que cambia la especie o la carcasa,
en sentido app → aparato, sobre un nodo que ya está despierto.

**Los dos límites de luz viajan comprimidos con el mismo códec que la lectura.**
Mantisa de 12 bits y exponente de 4. El error relativo arriba de 4.095 lux es
menor al 0,03%, muy por debajo de la tolerancia del propio BH1750, y reutiliza
un códec que ya estaba testeado en vez de agregar cuatro bytes crudos.

**El ánimo viaja resuelto, en un byte empaquetado.** Cuatro bits de ánimo y dos
de severidad. Empaquetar en vez de gastar dos bytes no es capricho: la trama
tiene que seguir entrando en un paquete ESP-NOW corto.

**La iluminancia viaja con mantisa y exponente.** Hay que cubrir de 1 a 100.000
lux. En 16 bits lineales habría que sacrificar la resolución baja, que es justo
donde vive el umbral de noche.

**CRC16-CCITT sobre toda la trama.** En 2,4 GHz con vecinos ruidosos, una trama
corrupta que pase por buena le pone al aparato una cara equivocada con total
convicción. Un test verifica que todos los flips de un bit se detecten.

**Medir y transmitir van desacoplados.** Medir cuesta 250 nAh y transmitir
28.000: 110 veces más. Se mide seguido y se emite sólo ante un cambio, un cruce
de umbral, un cambio de estado de batería o el latido de dos horas. Una semana
simulada da 68% menos de radio que un intervalo fijo de 15 minutos.

## Arte y colección

**Seis familias de ojos, no seis juegos de sprites.** Cada modelo elige una
familia —redondos, rasgados, fieros, visor, único, pesados— y el ánimo elige
la forma dentro de esa familia. Dibujar sesenta y seis caras a mano sería un
mes de trabajo, y agregar un modelo costaría once caras más.

**Kip sale de su lámina, no del rig.** El rig cruza una tabla de
expresiones con una fila de proporciones, y eso da once ánimos para
cualquier personaje sin dibujar ninguno: sirve mientras no haya dibujos.
Cuando Rocío entregó las láminas de Kip, forzarlas dentro del rig las
convertía en otra cosa —ojos de compás, cejas de palito, bocas de programa,
"muy de anime"—, así que Kip tiene su propio dibujante (`art/kip.c`) con sus
dibujos como tablas y sus secuencias como pistas de claves. Sigue siendo
procedural (no son imágenes: un cuadro son un par de docenas de polígonos, y
entre dibujo y dibujo todo se interpola) y sigue leyendo su fila de
`persona.c`. El precio es código por personaje; se paga una vez por lámina,
y el día que lleguen las de Nori, Blink y Plum, cada una se suma igual.

**Los rasgos se miden en centésimas del ancho del panel, no en pixeles.** Así
la misma tabla de modelos sirve para cualquier panel futuro sin tocar un
número, y quien ajusta el arte edita proporciones y no coordenadas.

**El modelo secreto no se lista hasta que sale.** Mostrarlo en gris ya le
contaría al usuario que existe, y ahí deja de ser un secreto para ser una
casilla vacía que además le informa cuántos le faltan.

**La colección no cuenta repetidos.** Registra qué modelos tenés, no cuántos
de cada uno. Contar duplicados la convertiría en un inventario, y un
inventario no da ganas de completar nada.

**El primer encendido no repite el gachapón.** La sorpresa ya ocurrió al abrir
la caja; hacerla de nuevo en pantalla sería contar dos veces el mismo chiste y
el segundo sería el falso. La escena cambia de sentido: no es "mirá lo que te
tocó" sino "ah, entonces soy este" —el aparato despierta a oscuras, se
descubre los rasgos y se presenta. Dura 3,6 s contra los 5,2 de la ceremonia
anterior, porque acompaña un momento en vez de intentar ser el momento.

**El vínculo crece con días sanos, no con días transcurridos.** Una planta
abandonada tiene un aparato que no evoluciona, y ahí está toda la mecánica.
Pero un mal día corta la racha sin borrar lo acumulado: castigar un descuido
con meses de progreso convierte un olvido en motivo para abandonar el
producto.

**Un aparato caído no acumula días sanos.** Si no sabemos cómo estuvo la
planta, no se premia. Es lo que impide que desenchufarlo haga crecer el
vínculo gratis.

**El catálogo de la app se genera desde el del firmware.**
`tools/sync_catalog.py` lo deriva de `species.c` y `persona.c`, y CI falla si
quedó desfasado. El índice del modelo es la clave con la que la carcasa viaja
por radio: si la tabla se reordena sin regenerar, cada maceta se pone la cara
de la vecina.

## Software

**El núcleo es C99 puro.** `firmware/core/` no depende de ESP-IDF y no usa punto
flotante. Se compila igual en el simulador, en los tests y en las dos placas. La
temperatura viaja en décimas de grado en un `int16_t`.

**Prioridad de estados de ánimo: agua, temperatura, luz, aire.** Se muestra la
necesidad insatisfecha más urgente, no un promedio. El agua va primero porque es
lo que mata más rápido.

**Histéresis en todos los umbrales.** Sin banda de salida, el simbionte titila
entre feliz y sediento cada vez que la lectura oscila un punto sobre el límite.

**De noche el simbionte duerme.** Tras ocho muestras consecutivas por debajo de
15 lux se suprimen las quejas por luz y por aire seco, pero no las de agua ni las
de temperatura.

**Resolución nativa, sin lienzo lógico.** 128×128 son 32 KB: entran holgados en
los 400 KB de SRAM de un ESP32-C3, con lugar de sobra para un segundo buffer y
mandar por DMA mientras se dibuja el siguiente.

**El aparato no muestra números.** Un "34%" en 1 mm de alto no se lee, y si se
leyera no significaría nada sin el rango de la especie al lado. El número
exacto está en la app, que es donde alguien lo va a ir a buscar.

**Renderer propio en vez de LVGL.** La cara es procedural: elipses, arcos y
trazos calculados. LVGL trae un motor de widgets que acá no se usaría nunca, y
un buffer RGB565 plano es exactamente lo que espera
`esp_lcd_panel_draw_bitmap()`.

**El presupuesto energético vive en código testeado, no en una planilla.** Las
cifras de autonomía salen de correr `make test`, así que si alguien cambia un
parámetro el número se rompe en vez de quedar viejo en silencio. Los costos por
evento van en nanoamperios-hora: en microamperios-hora enteros, una medición de
0,25 µAh se redondea a cero y desaparece del modelo.

**Regresión visual por hash, una fila por modelo y ánimo.**
`firmware/test/golden.h` guarda un FNV-1a del framebuffer de las ochenta y ocho
caras. Se versiona en vez de ignorarse porque el diff del archivo generado *es*
la revisión del cambio visual: once filas seguidas dicen "se movió un modelo",
una columna dice "se movió un ánimo en todos".

**La app es una PWA, no una app nativa.** La foto obliga a tener el celular,
pero no una App Store: una página web abre la cámara con `<input capture>`. Sin
tienda no hay cuota anual ni nadie revisando las mecánicas de colección contra
las políticas de cajas de botín. Se sirve por HTTP en la red local, porque una
página HTTPS tiene prohibido pedirle datos a una IP privada.

## Producto

**Sin pH.** Ni PlantSenso, ni Ivy, ni Mi Flora miden pH real de suelo: es
genuinamente difícil y todos los aparatos de consumo que muestran el número lo
están inventando. No mostrarlo es honesto y además es un argumento de venta para
el público al que apunta ROOTKIT.

**El único azar del software es de color.** El cofre sortea la piel, no el
Rooti, con probabilidades públicas y nada que comprar: el riesgo regulatorio
de las cajas de botín —que Bélgica y Países Bajos ya restringen, y que
siempre es sobre azar pago— no aplica.

**Nada de la palabra Tamagotchi en el marketing.** Es marca registrada de Bandai.
El vocabulario propio — simbionte, criatura digital — es más distintivo igual.

**Los Rooties son de la escuela del juguete de vinilo, no copias de nadie.**
La referencia declarada para el elenco 3D es la de los juegos de
criaturas-vegetales con cuerpos simples y colores saturados; Ooblets es el
ejemplo evidente y sirvió de norte. Lo que se toma es el **lenguaje**: cuerpo
gordito de una sola pieza, un rasgo botánico que manda arriba, patitas
mínimas, cara pintada sobre el cuerpo y contorno oscuro. Lo que no se toma es
ninguna silueta concreta: cada Rooti sale de una planta real, tiene su nombre,
su cara —que es la del firmware, nuestra y anterior a todo esto— y su
personalidad. La prueba práctica: si una figura se pareciera demasiado a una
criatura existente, se cambia sin drama, porque una figura son treinta números
en una tabla.

## Actualizarse y salir de fábrica

**Las actualizaciones van firmadas, además de por HTTPS.** HTTPS prueba que
el binario viene del servidor; la firma (ECDSA P-256), que lo publicó quien
tiene la clave privada, que no está en el servidor. Tomar el servidor no
alcanza para instalarle algo a una maceta. Cuesta 40 KB de mbedTLS que ya
estaban en la imagen por el TLS.

**Una versión nueva se confirma hablando con la nube.** No alcanza con que
arranque: tiene que lograr un sync (wifi, TLS, JSON, todo el camino) en diez
minutos, o el aparato vuelve solo a la anterior. Y cada versión se intenta
tres veces como mucho.

**Los aparatos siguen "la vigente de su canal", no "la mayor".** Así volver
atrás es publicar la versión anterior, sin un mecanismo aparte.

**El secreto lo genera la estación de fábrica y no queda en ningún lado más
que en el aparato.** La nube guarda el hash del token; el programa de fábrica
lo descarta apenas registra. No hay una planilla de secretos que cuidar.

**La calibración del sensor es de la planta, no del aparato.** Depende del
sustrato tanto como del sensor: se hace desde la app, en dos pasos, con el
número crudo a la vista, y la nube se la manda al Rooti. La de fábrica es un
punto de partida.

## La nube, el QR y el cofre

**La pantalla muestra dos cosas: el QR y los ojos.** Ni batería, ni wifi, ni
pictogramas, ni texto. Todo lo que no es una cara es presentación, y la
presentación vive en la app. La batería crítica se nota igual: con la planta
bien, la cara se duerme; el aviso con palabras llega como notificación.

**El primer encendido es un QR.** Lleva a la app en `/v/<código>`. Debajo va el
código en letras grandes, partido en dos grupos de cuatro, porque es el plan B
cuando la cámara no enfoca y el plan A en iPhone cuando hay que tipearlo.

**Base32 de Crockford para el código.** Sin I, L, O ni U: se dicta y se tipea
sin confundir 0 con O. Y todos sus caracteres entran en el modo alfanumérico
del QR, que en el panel de 128 es la diferencia entre módulos de 3 y de 2
pixeles.

**El código cambia con cada desvinculación.** Sale de una época que sube al
desvincular. Un QR fotografiado por el dueño anterior deja de valer en ese
instante.

**Portal cautivo para pasar el wifi.** Anda en cualquier teléfono sin instalar
nada. Web Bluetooth no existe en iPhone, y una página HTTPS no puede hablarle a
`192.168.4.1`.

**En la app, instalar antes que avisos.** En iPhone las notificaciones web
existen sólo para la app instalada. Pedir el permiso antes sería pedir algo
imposible, y el usuario lo rechazaría para siempre.

**El cofre se abre en la app y la maceta despierta.** La sorpresa de qué piel
te tocó pasa en la pantalla grande, con luz y confeti de sus colores. La
maceta muestra la consecuencia: abre los ojos con esa paleta. El pedido al
servidor sale recién al tercer toque para que las dos cosas pasen juntas.

**Antes del cofre, el Rooti dormido y en gris.** Se reconoce la forma de su
cara —la app ya dijo "¡Conectaste a tu Brote!"— pero no la piel.

**La persona se graba en fábrica; si no hay, la nube asigna una fija.** Con
carcasa impresa, el personaje ya existe. En prototipos sin persona grabada,
la nube elige una por el id del aparato, siempre la misma.

**La especie sale de una foto, y los umbrales del catálogo.** La IA identifica;
si la planta está en el catálogo curado se usan sus números y no los del
modelo. Si no está, los rangos del modelo pasan por la misma validación que el
firmware (acotados y coherentes).

**Las caras de la app las dibuja el firmware.** El núcleo compilado a
WebAssembly pesa 50 KB. No hay una versión CSS de las caras que se pueda
desincronizar de la maceta.

**El aparato decide su cara; la nube, los días sanos.** La cara no puede
depender de la red. Los días sanos sí se cuentan en la nube, que ve el día
entero aunque el aparato duerma, y se los devuelve para los adornos.

**Un pedido por sincronización.** Cada conexión TLS cuesta casi un segundo de
radio: juntar estado, lecturas y configuración en un ida y vuelta es la mayor
optimización del protocolo.

**Sin reloj de pared.** Las lecturas llevan "hace N segundos" desde un reloj
monótono que suma el deep sleep. El servidor les pone fecha.

**Una respuesta sin `"ok": true` no se aplica.** Un portal de hotel que
contesta HTML no puede desvincular una maceta.

**C3 SuperMini y no ESP32 de 30 pines.** El regulador del DevKit consume más
durmiendo que el C3 midiendo. Detalle en [hardware.md](hardware.md).

**Un sensor caído no inventa problemas.** Cada lectura marca qué sensores
fallaron y el ánimo ignora esas magnitudes: sin AHT20 no hay frío, hay "no sé".

**Avisar por estado, no por lectura.** Una sed de seis horas es un aviso, no
veinticuatro. Se repite a las 8 h, o a las 3 h si es urgente. De 23 a 8, sólo
lo urgente.

---

## Decisiones revisadas

### El protocolo binario sobre ESP-NOW

**Antes:** tramas binarias de 26 y 32 bytes con CRC16, un Prime que recibía por
ESP-NOW y servía el tablero en la red local.

**Qué lo tumbó:** las notificaciones. Tienen que llegar con la app cerrada y
el teléfono fuera de casa, y eso lo manda un servidor. Con la maceta hablando
HTTPS con la nube, el costo de radio lo pone el apretón de manos TLS y no el
tamaño del cuerpo: JSON pasó a costar lo mismo y se lee en un log. Lo que
sobrevivió del protocolo viejo: medir y transmitir desacoplados, y el ánimo
evaluado en el aparato.

### El pixel art

**Antes:** caras de trazo duro, sin suavizado, escaladas por enteros.

**Qué lo tumbó:** la dirección de arte. Las caras tienen que ser ilustración
plana tipo Duolingo, y ese estilo vive en el borde de las curvas: sin
suavizado se ve escalonado. Se escribió `gfx/aa.c`, antialiasing en punto
fijo, y el fondo de la cara pasó a ser liso para que los párpados sean piel.

### El primer encendido como ceremonia en la pantalla

**Antes:** la maceta se "descubría la cara" sola, con nombre y rareza en
letras.

**Qué lo tumbó:** el cofre en la app. La sorpresa pasa en el teléfono; la
maceta sólo abre los ojos, sin texto. La pantalla del aparato ya no escribe
nada salvo el código del QR.

### El aviso de batería y el pictograma en la pantalla

**Antes:** un ícono de pila parpadeante y un pictograma (gota, sol, copo) en la
esquina.

**Qué lo tumbó:** la regla de "QR y ojos". Lo que pide la planta lo dice la
cara y lo detalla la notificación; la batería crítica duerme la cara.

### Declarar la carcasa en la app

**Antes:** al dar de alta la maceta, el usuario elegía qué carcasa le había
tocado.

**Qué lo tumbó:** la persona grabada en fábrica y el cofre. El usuario no
declara nada: lo descubre.

### El cofre que sorteaba el personaje

**Antes:** ocho Rooties (Cresta, Kawaii, Visor, Cíclope, Hongo, Chico Malo,
Chica Chill y un secreto) y un cofre que revelaba el de fábrica o, en
prototipos, sorteaba cuál te tocaba con 70 / 25 / 5 por rareza de modelo.

**Qué lo tumbó:** la figura. Si la persona tiene un Pinchito en la mano, un
cofre que diga "¡Te tocó el Musgo!" es mentira, y el aparato no puede cambiar
de carcasa. Y los personajes estaban dispersos: mitad criaturas, mitad
estilos, sin un mundo común.

**Lo que lo reemplaza:** cinco Rooties botánicos, con un mundo de libro de
cuentos (Ooblets, Pokémon Café ReMix), y un cofre que sortea la piel. La cara
queda en la maceta; el cuerpo entero se ve en la app, con las mismas reglas
de impresión que la carcasa (voladizos de 45°, base plana, centro de masa
bajo), verificadas por un test.

**Lo que se perdió:** el secreto translúcido. Si vuelve, vuelve como edición
de filamento de una piel épica, no como un personaje que no está en la caja.

### El gachapón se volvió físico

**Antes:** doce simbiontes dibujados, cada uno con su cuerpo pixel art, y el
que te tocaba salía de la especie de tu planta. La rareza venía de la
dificultad hortícola: el bonsái daba un legendario porque mantenerlo vivo es
trabajo real.

**Qué la tumbó:** dos cosas a la vez. La primera es que **no funcionaba
visualmente**. Los doce compartían silueta —una tortuga repintada doce veces—
y eso estaba anotado acá como compromiso explícito, pero "documentado" no es
lo mismo que "bueno". La segunda es que el esfuerzo estaba mal repartido:
dibujar y animar un cuerpo nuevo cuesta semanas, imprimir una carcasa cuesta
filamento y unas horas de modelado.

**Lo que la reemplaza:** la variedad se mudó al plano físico. Seis carcasas
impresas en caja ciega, y en pantalla sólo la cara, que le hace juego a la
carcasa que te tocó. Seis modelos por once ánimos son sesenta y seis caras que
salen de un rig procedural en vez de sesenta y seis dibujos.

**Lo que se ganó además, sin buscarlo:** la posición legal quedó más firme. La
rareza determinista existía para no ser una caja de botín; ahora directamente
no hay ninguna tirada de dados dentro del software. Hay un juguete en una
caja, que es lo que venden los Smiski desde hace años.

**Lo que se perdió:** la rareza ya no premia el trabajo hortícola. Un potus y
un bonsái tienen la misma chance de venir con el secreto. Se compensó moviendo
el mérito a lo cosmético —los días sanos desbloquean brillos, aura y corona—
pero es un premio más chico y conviene saberlo.

### El Prime y los Minis

**Antes:** un Prime enchufado con pantalla de 2,2 pulgadas y hasta cinco Minis
a batería. El Prime mostraba el tablero, abría las cápsulas y era donde el
simbionte se veía grande.

**Qué la tumbó:** mover las métricas a la app. Con el tablero afuera y el
bicho reducido a una cara, la pantalla grande se quedó sin trabajo: costaba el
doble que la de 1,44" para mostrar lo mismo más grande. Y la jerarquía entre
"adulto" y "brote", que era la razón de producto del Prime, dejó de tener
sentido cuando el personaje pasó a ser la carcasa.

**Lo que se conservó:** `gfx/panel.h` sigue describiendo los dos tamaños y el
rig dibuja en cualquiera, porque los rasgos se miden en centésimas del ancho.
Una variante grande es un cambio de configuración, no un rediseño.

### El TFT de 2,2" del prototipo

> **Revisada de nuevo, 21/09/2026.** Volvió, pero no como producto. El
> sustrato v3.0 tiene una tira de **nueve** pines, que es la del ILI9341 de
> 2,2" —la pantalla que hay sobre la mesa—; la de 1,44" tiene ocho y otro
> orden, así que no entra en esa tira. El firmware la soporta otra vez desde
> la 0.6.2 como **variante de banco** (`c3-22`, `devkit-22`), que es lo que
> autoriza la nota de abajo: "sumar un panel es agregar su bloque en placa.h
> y su clase en pantalla.cpp". Cuál de las dos es el producto se decide
> cuando haya carcasa. Lo de abajo sigue siendo válido para esa decisión.

**Antes:** dos variantes de hardware con el mismo firmware: el ROOTKIT con
TFT de 2,2" (ILI9341, 240×320) y el "mini" de 1,44", cada una para el C3 y
para el DevKit: cuatro compilaciones, dos láminas de pantallas, dos juegos de
números de consumo.

**Qué lo tumbó:** las carcasas. Las cinco figuras se diseñaron alrededor del
TFT de 1,44" que entra desde atrás en una ventana biselada; el de 2,2" no
entra en ninguna. Era una variante sin producto, y cada cambio pagaba el
doble de compilación y de prueba.

**Lo que quedó:** un producto (`c3-144`) y un banco (`devkit-144`). El núcleo
sigue escalando al lado corto del panel, así que volver a sumar un tamaño es
un bloque en `esp32/placa.h` y una clase en `esp32/pantalla.cpp`.

### La XP y los niveles de la app

**Antes:** ROOTLAB tenía XP y siete niveles ("Jardinero de interior"), además
de la racha, los logros, las etapas del vínculo y la mascota.

**Qué los tumbó:** la XP se derivaba entera de los días sanos. Eran dos
barras para lo mismo, y seis sistemas para decir "cuidaste bien" no se
explican solos.

**Lo que quedó:** la mascota es lo de hoy; el vínculo (días sanos → etapas →
adornos en la cara, `core/vinculo.c`) lo de meses; la racha, la casa entera;
los logros, los hitos. La etapa de los 7 días pasó a llamarse **retoño**:
Brote es un Rooti.

### La confianza al primer uso, abierta

**Antes:** cualquier aparato que se presentaba con un id nuevo quedaba
registrado (`ROOTLAB_TOFU=1`), también en producción.

**Qué la tumbó:** la estación de fábrica ([fabrica.md](fabrica.md)). Con cada
placa registrada de antemano por el hash de su token, dejar la puerta abierta
ya no compraba nada.

**Lo que quedó:** en producción sólo los emuladores del navegador se
registran solos (con límite por IP y limpieza a los 30 días); las placas, por
fábrica. En desarrollo sigue abierta.

### El nodo dejó de ser tonto

**Antes:** el Spore medía, empaquetaba y dormía. No conocía especies ni
umbrales, y toda la interpretación vivía en la Terminal.

**Qué la tumbó:** ponerle pantalla a cada nodo. Un aparato que necesita la red
para saber qué cara poner se queda mudo justo cuando más importa.

**Cómo se respetan las razones originales.** La batería: evaluar el ánimo son
unas pocas comparaciones enteras sobre datos que ya están en RAM, y no agrega
un solo despertar. Las actualizaciones: los umbrales no están compilados,
viajan en `CONFIG`. La implementación única: `core/mood.c` sigue existiendo una
sola vez.

**Y la regla nueva que hizo falta:** quien recibe **no recalcula**. Hay un test
que manda una telemetría cuyos números gritarían `THIRSTY` y cuyo ánimo dice
`HAPPY`, y verifica que se respeta el ánimo.

### La OLED monocroma

**Antes:** OLED 0,91" 128×32 mostrando sólo los ojos. Compartía el bus I2C de
los sensores —cero pines nuevos— y consumía la sexta parte.

**Qué la tumbó:** el precio de la TFT de 1,44" bajó a ARS 9.160, apenas 1.660
más, y a esa diferencia el argumento económico desaparece. Y una vez que se
decide mostrar una cara entera y no dos ojos, el color deja de ser un lujo:
seis modelos monocromos serían seis siluetas parecidas.

**Qué se perdió:** la autonomía baja de unos 750 días estimados a unos 595, y
la SPI se lleva cinco GPIO contra cero de la OLED. Ese consumo de pines es
exactamente el motivo por el que hoy la carcasa no se detecta sola.

### El lienzo lógico de 160×240

**Antes:** se rasterizaba a 160×240 y se escalaba 2× al presentar, porque el
panel de la Terminal era de 320×480 y sus 300 KB no entraban en la SRAM.

**Qué la tumbó:** el cambio de panel. 128×128 son 32 KB y entran de sobra, así
que la capa de conversión de coordenadas dejó de pagar lo que costaba.

### La cañería de sprites

**Antes:** `tools/gen_art.py` generaba los cuerpos, los ojos y las bocas como
datos C indexados por paleta, y `gfx/fb.c` tenía cuatro variantes de blit para
dibujarlos.

**Qué la tumbó:** la cara procedural no usa un solo sprite. Quedaron 21 KB de
arte generado y unas 200 líneas de blit sin un solo llamador, así que se
borraron. Está anotado porque la tentación de dejar código muerto "por si
vuelve" es exactamente cómo un repo se pudre.

### Las siluetas 2D de los Rooties

**Antes:** el cuerpo del Rooti en la app era un dibujo SVG —un contorno de
puntos suavizado con Catmull-Rom, con relieves encima— y la carcasa impresa
era un modelo aparte, que alguien iba a tener que dibujar en un CAD "a partir
de" esa silueta.

**Qué la tumbó:** dos cosas a la vez. La primera, que un contorno plano con
sombreado pintado a mano se ve como lo que es, y el producto necesita que el
personaje se vea como el juguete. La segunda, y más importante: **"a partir
de" no es una relación verificable**. Las pruebas medían voladizos sobre una
curva 2D que no era la pieza que iba a salir de la impresora, así que decían
muy poco. Pasando el cuerpo a 3D, el modelo que gira en el teléfono y el STL
que se lamina son el mismo archivo, y la prueba de voladizos mide los
triángulos de verdad.

**Qué costó:** un motor WebGL propio (no hay bibliotecas de terceros en la
app), volver a diseñar las cinco figuras desde el perfil y descubrir en el
camino unos cuantos errores que el 2D escondía —mallas con los triángulos
invertidos, piezas que empezaban en el aire, un hueco de 10 mm para el TFT en
el Bulbo—. El peso subió poco: las figuras son tablas de números y el shader
tiene treinta líneas.

**Qué se ganó además:** los STL dejaron de ser una tarea pendiente del
roadmap. Se generan con `npm run carcasas`.

### Que el personaje y la carcasa fueran la misma malla

**Antes:** —y duró un día— el modelo 3D de la app era exactamente el STL de la
carcasa. Sonaba bien: una sola fuente, y las pruebas de voladizo midiendo la
pieza de verdad.

**Qué la tumbó:** los personajes. Atar el diseño a que la figura saliera de una
impresora sin soportes obliga a voladizos de 45°, base plana y nada que
sobresalga; con esas reglas, los cinco Rooties quedaron cuerpos de revolución
redondos, sin patitas separadas, sin bracitos que salieran del torso y sin
sombrero. Correctos y sin gracia. El usuario lo dijo en una línea: *"se ve
bastante igual que antes"*.

**Qué se hizo:** separarlos. El personaje de la app se esculpe como campos de
distancia fundidos (`esculpir.mjs`), sin ninguna regla de impresión, y la
carcasa se diseña aparte en el CAD del hardware. De los modelos sale igual un
STL, pero como referencia de forma.

**La lección, que es más general:** una restricción de fabricación aplicada
demasiado arriba en la cadena no limita el resultado, lo achata. La restricción
va donde se fabrica.
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

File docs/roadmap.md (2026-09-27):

# Checklist y roadmap

Dónde está el producto y qué falta, en orden. Cada casilla es algo que se
puede verificar; las que están marcadas tienen prueba o captura que lo
respalda.

**Nombres:** **ROOTKIT** es el hardware (la maceta con su placa y su
carcasa). Cada personaje es un **Rooti** (plural: Rooties). **ROOTLAB** es la
app y la nube.

**Dos repositorios:**

- [`root-kit`](https://github.com/ifbotech/root-kit) — firmware, hardware y
  carcasas.
- [`root-lab`](https://github.com/ifbotech/root-lab) — ROOTLAB: la app, la
  nube, las cuentas, la IA, el correo, las notificaciones y el emulador.
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

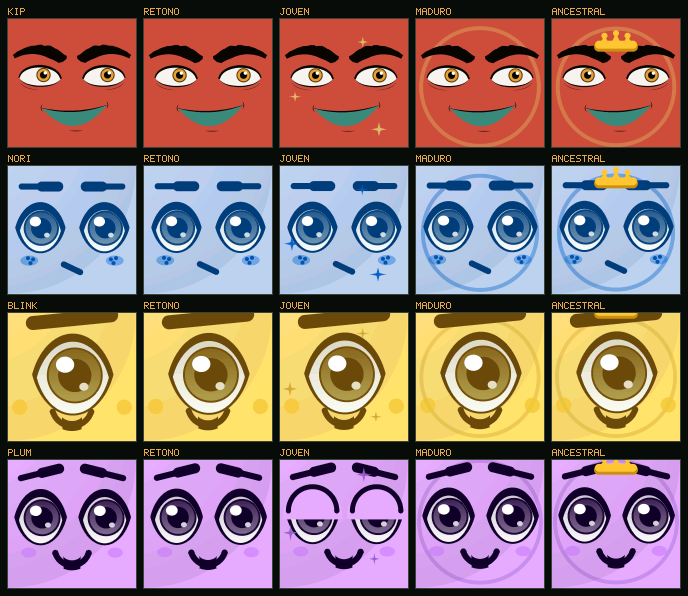
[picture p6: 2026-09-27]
tools/preview/etapas.png

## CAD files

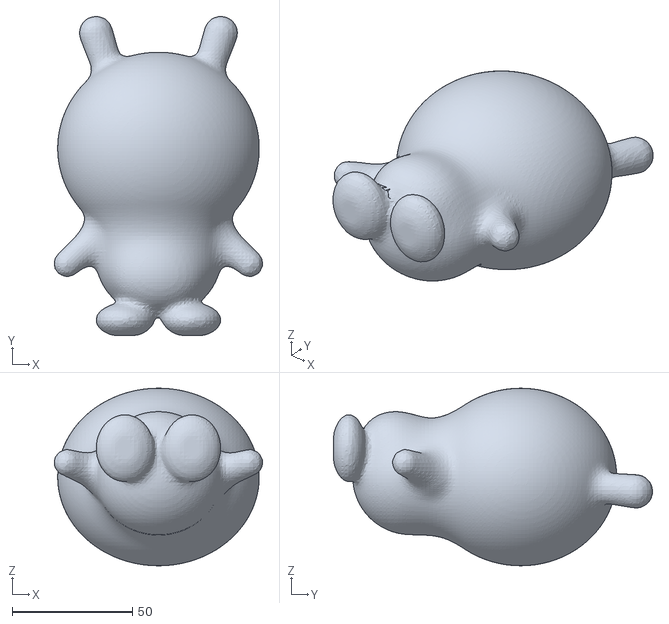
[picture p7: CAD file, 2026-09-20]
carcasas/blink.stl
86.8 x 132.9 x 74.0

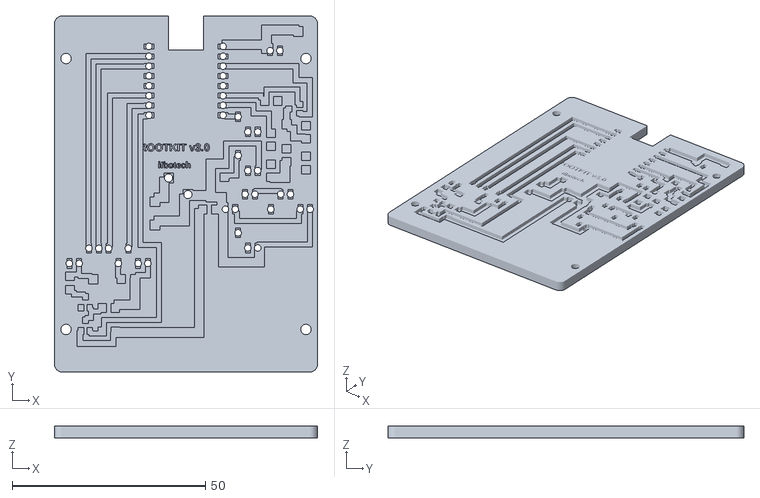
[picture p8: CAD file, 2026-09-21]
hardware/pcb/generado/nucleo-sustrato.stl
68.0 x 92.0 x 3.00

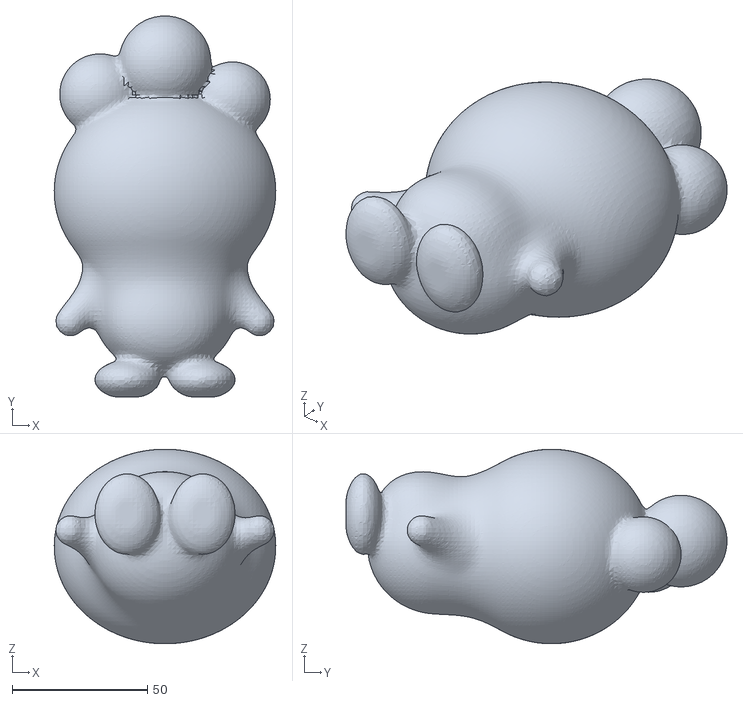
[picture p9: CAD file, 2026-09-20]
carcasas/kip.stl
81.9 x 140.9 x 71.9

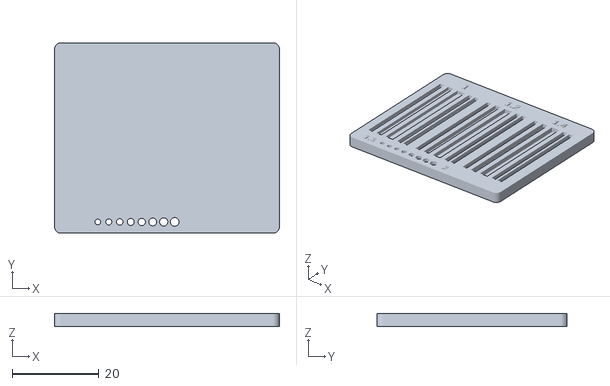
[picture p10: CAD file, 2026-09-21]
hardware/pcb/generado/cupon-sustrato.stl
52.0 x 44.0 x 3.00

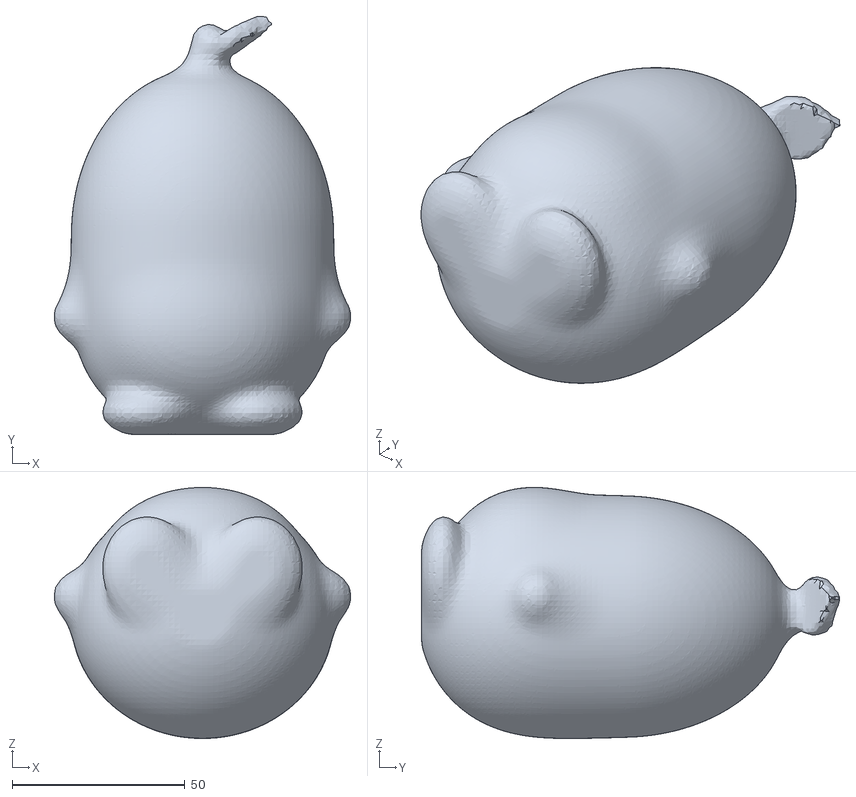
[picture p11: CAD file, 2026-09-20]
carcasas/plum.stl
85.9 x 121.1 x 72.8

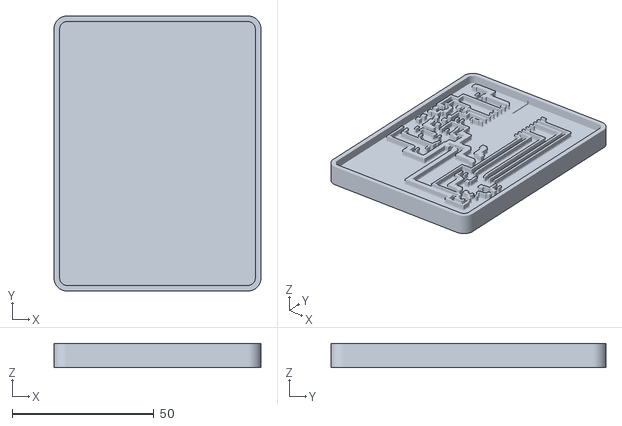
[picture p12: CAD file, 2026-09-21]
hardware/pcb/generado/nucleo-estampadora.stl
73.0 x 97.0 x 8.50

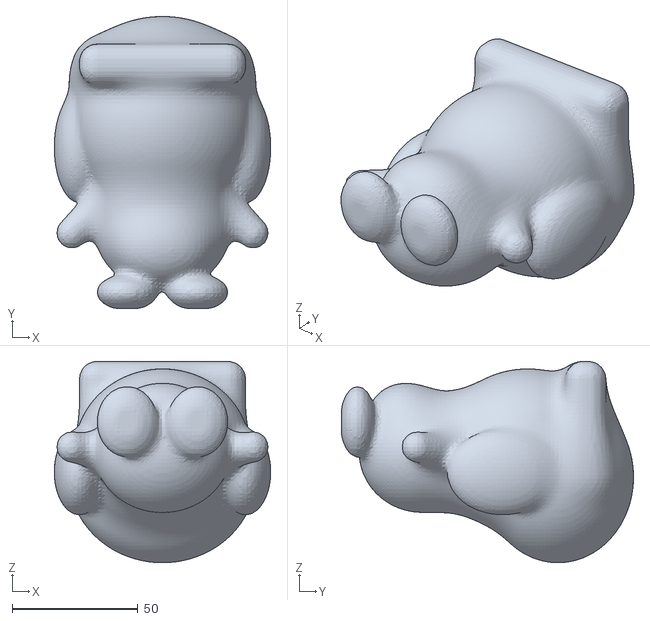
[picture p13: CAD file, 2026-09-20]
carcasas/nori.stl
86.0 x 116.0 x 80.0

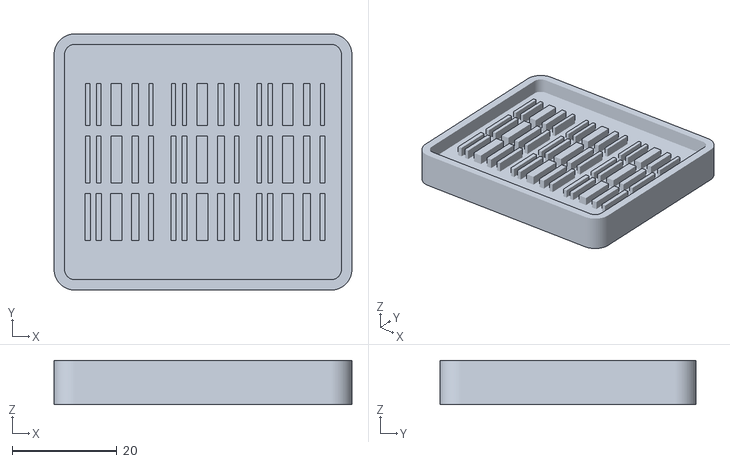
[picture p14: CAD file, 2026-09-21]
hardware/pcb/generado/cupon-estampadora.stl
57.0 x 49.0 x 8.50

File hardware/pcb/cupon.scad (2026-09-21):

// cupon.scad — la pieza de prueba del proceso de la cinta.
//
// Media hora de impresora que contesta las tres preguntas que el sustrato
// v3.0 deja abiertas y que no se pueden contestar en la computadora:
//
//   1. HASTA DONDE SE PUEDE HUNDIR LA CANALETA. Cuanto mas profunda, mas se
//      estira la cinta sobre el borde y mas cerca queda de cortarse ahi
//      sola. Pero pasado un punto se rompe en el PISO, que es donde tiene
//      que conducir. El cupon trae tres profundidades: 1,0 / 1,2 / 1,4 mm.
//      El sustrato usa 1,2.
//   2. CON CUANTA LUZ ENTRA LA NERVADURA sin agarrar. Cuanto mas ajustada,
//      mejor marca la cinta contra el borde; demasiado y la estampadora no
//      baja. El cupon trae tres: 0,15 / 0,20 / 0,25 mm por lado, en tres
//      franjas horizontales que cruzan TODAS las canaletas, asi que una sola
//      prensada prueba las nueve combinaciones.
//   3. CUANTA LIJA HACE FALTA para que dos canaletas vecinas den abierto, y
//      si la pared minima de 0,8 mm sobrevive a esa lija. El ultimo par de
//      cada grupo esta separado por exactamente 0,8 mm.
//
// De yapa, la fila de ocho agujeros de abajo: es la huella de una tira de
// pines, a 2,54 mm de paso, y va de 1,3 a 2,0 mm de a una decima. Dice cual
// es el diametro mas chico por el que el pin entra SOLO, que no es el mismo
// que el diametro con el que el agujero se ve abierto.
//
// ---------------------------------------------------------------------------
// RESULTADO DE LA PRIMERA CORRIDA (21/09/2026, PETG, boquilla 0,6, capa 0,2)
//
//   Profundidad y luz: gano la combinacion del CENTRO, 1,2 mm de hondo con
//   0,20 mm de luz por lado. Con 1,0 la cinta no se marca lo suficiente
//   contra el borde; con 1,4 empieza a romperse en el piso. Con 0,15 la
//   nervadura agarra y la pieza no baja del todo; con 0,25 la cinta queda
//   floja contra el borde y la lija no la corta pareja. Los dos numeros
//   estan ahora en nucleo.json.
//
//   Agujeros: en esa corrida los ocho eran del MISMO diametro, 1,4 mm --no
//   habia gradiente, era un error de este archivo-- y por tres de ellos el
//   pin no entraba y por los otros cinco entraba perfecto. Ese es justamente
//   el hallazgo: a 1,4 mm nominal el agujero esta en el filo y lo decide la
//   variacion normal de la impresora, porque un agujero impreso sale dos o
//   tres decimas mas chico que el dibujado. El sustrato paso a 1,7 mm. La
//   fila de ahora, con gradiente de verdad, es la que confirma ese numero.
// ---------------------------------------------------------------------------
//
//   make cupon     exporta los dos STL
//
// Se imprimen los dos SIN SOPORTES, con la misma boquilla (0,6), la misma
// altura de capa (0,2) y el mismo material que el sustrato de verdad: si se
// prueba en PLA no se prueba nada, porque el PETG se estira distinto bajo la
// nervadura y se ablanda a otra temperatura.
//
// Los numeros de aca salen de hardware/pcb/nucleo.json y estan escritos a
// mano A PROPOSITO: este archivo es el que se toca para barrer valores, y no
// tiene que arrastrar al sustrato cada vez que se prueba algo.

// "sustrato" | "estampadora" | "choque" | "presencia"
//
// Los dos ultimos son la prueba de encaje, la misma que la placa grande:
//   choque     la interseccion de las dos piezas, apoyadas a fondo, tiene
//              que dar VACIA. Cualquier solido es plastico contra plastico.
//   presencia  lo que la estampadora mete DENTRO de las canaletas tiene que
//              dar LLENO. Sin esta, la primera se aprobaria por la razon
//              equivocada: si las nervaduras desaparecieran, la interseccion
//              tambien daria vacia.
pieza = "sustrato";

$fn = 48;
eps = 0.01;

// ------------------------------------------------------------ el cupon ---
cupon_ancho = 52.0;
cupon_alto  = 44.0;
cupon_esp   = 3.0;

// Las canaletas, de abajo hacia arriba en la pieza.
canaleta_y0 = 6.0;
canaleta_y1 = 38.0;

// Tres grupos, uno por profundidad. Dentro de cada grupo, cinco canaletas:
// las tres anchos del sustrato, y despues un par pegado a 0,8 mm, que es la
// pared minima. El ancho es el de la CANALETA (pista + 0,3 de holgura).
profundidades = [1.0, 1.2, 1.4];
anchos        = [1.3, 1.7, 2.5, 1.3, 1.3];   // pistas de 1,0 / 1,4 / 2,2
paredes       = [1.5, 1.5, 1.5, 0.8];        // entre canaleta y canaleta
grupo_sep     = 3.0;
margen_x      = 2.5;

function ancho_grupo() =
    anchos[0] + anchos[1] + anchos[2] + anchos[3] + anchos[4]
    + paredes[0] + paredes[1] + paredes[2] + paredes[3];

function x_grupo(g) = margen_x + g * (ancho_grupo() + grupo_sep);

// x del borde izquierdo de la canaleta i dentro del grupo g.
function x_canaleta(g, i) =
    x_grupo(g)
    + (i > 0 ? anchos[0] + paredes[0] : 0)
    + (i > 1 ? anchos[1] + paredes[1] : 0)
    + (i > 2 ? anchos[2] + paredes[2] : 0)
    + (i > 3 ? anchos[3] + paredes[3] : 0);

// La fila de agujeros de una tira de pines: mismo paso que una tira de
// verdad, y el diametro creciendo de a una decima. El primero es el mas
// chico. El sustrato usa 1,7, que es el quinto.
agujero_d0   = 1.3;
agujero_paso_d = 0.1;
agujero_paso = 2.54;
agujero_n    = 8;
agujero_y    = 2.6;
agujero_x0   = 10.0;

// ------------------------------------------------------- la estampadora ---
// Las mismas tres holguras laterales del JSON, en tres franjas que cruzan
// todas las canaletas. Cada franja es [y0, y1, holgura].
franjas = [
    [ 7.0, 16.0, 0.15],
    [18.0, 27.0, 0.20],
    [29.0, 37.0, 0.25],
];

est_sobresalir = 1.0;      // cuanto entra la nervadura mas alla de la cara
est_espesor    = 5.0;
est_faldon_alto    = 3.5;
est_faldon_pared   = 2.0;
est_faldon_holgura = 0.5;

borde_faldon = est_faldon_holgura + est_faldon_pared;

// --------------------------------------------------------- el sustrato ---
module canaletas_de(g) {
    // Todas las canaletas de un grupo, hundidas a SU profundidad.
    p = profundidades[g];
    translate([0, 0, cupon_esp - p])
        linear_extrude(p + eps)
            for (i = [0 : len(anchos) - 1])
                translate([x_canaleta(g, i), canaleta_y0])
                    square([anchos[i], canaleta_y1 - canaleta_y0]);
}

module agujeros_de_tira() {
    for (k = [0 : agujero_n - 1])
        translate([agujero_x0 + k * agujero_paso, agujero_y, -eps])
            cylinder(d = agujero_d0 + k * agujero_paso_d,
                     h = cupon_esp + 2 * eps);
    // Los dos extremos rotulados, para no tener que contar con el calibre.
    for (r = [[agujero_x0 - 4.2, agujero_d0],
              [agujero_x0 + (agujero_n - 1) * agujero_paso + 4.2,
               agujero_d0 + (agujero_n - 1) * agujero_paso_d]])
        translate([r[0], agujero_y, cupon_esp - 0.4])
            linear_extrude(0.4 + eps)
                text(str(r[1]), size = 2.0, halign = "center",
                     valign = "center", font = "Liberation Sans:style=Bold");
}

module rotulos_de_profundidad() {
    // Que grupo es cual, grabado 0,4 mm en la cara de las canaletas.
    for (g = [0 : len(profundidades) - 1])
        translate([x_grupo(g) + ancho_grupo() / 2, 40.8, cupon_esp - 0.4])
            linear_extrude(0.4 + eps)
                text(str(profundidades[g]), size = 2.4, halign = "center",
                     valign = "center", font = "Liberation Sans:style=Bold");
}

module cupon_sustrato() {
    difference() {
        linear_extrude(cupon_esp)
            offset(r = 1.5) offset(r = -1.5)
                square([cupon_ancho, cupon_alto]);
        for (g = [0 : len(profundidades) - 1]) canaletas_de(g);
        agujeros_de_tira();
        rotulos_de_profundidad();
    }
}

// ------------------------------------------------------ la estampadora ---
// Va ESPEJADA EN X, por lo mismo que la grande: se imprime con las
// nervaduras hacia arriba (unica forma de que salgan sin soportes) y se usa
// dada vuelta, y dar vuelta espeja. Aca importa de verdad: los tres grupos
// de profundidad no son simetricos, asi que sin el espejo la nervadura de
// 2,0 mm caeria en la canaleta de 1,4 de hondo y al reves.
module contorno_cupon(crecer = 0) {
    offset(r = crecer)
        offset(r = 1.5) offset(r = -1.5)
            square([cupon_ancho, cupon_alto]);
}

module nervaduras3d() {
    for (g = [0 : len(profundidades) - 1])
        for (f = franjas)
            for (i = [0 : len(anchos) - 1]) {
                a = anchos[i] - 2 * f[2];
                if (a > 0)
                    translate([x_canaleta(g, i) + f[2], f[0]])
                        linear_extrude(profundidades[g] + est_sobresalir)
                            square([a, f[1] - f[0]]);
            }
}
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

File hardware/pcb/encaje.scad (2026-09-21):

// encaje.scad — la prueba de que la estampadora entra en el sustrato.
//
// Pone la estampadora dada vuelta, como se usa, apoyada a fondo sobre el
// sustrato, y calcula la INTERSECCION de las dos piezas. Si el diseño está
// bien, tiene que dar **vacía**: las nervaduras entran en sus canaletas sin
// tocar las paredes, el faldón envuelve el borde sin apretarlo, y las dos
// caras planas quedan separadas por est_sobresalir.
//
//   make pcb            la corre sola si hay OpenSCAD
//   python3 tools/pcb.py --encaje
//
// Cualquier sólido que aparezca acá es plástico contra plástico: la pieza no
// va a bajar hasta el fondo y la cinta no va a entrar en esa canaleta.
//
// Esta prueba existe porque la estampadora tiene un error posible que no se
// ve mirando el modelo: va **espejada en X**, porque se imprime con las
// nervaduras hacia arriba y se usa dada vuelta. Si alguna vez se toca
// `estampadora.scad` y se pierde ese espejo, la pieza sigue pareciendo
// correcta, imprime igual de bien, y no entra. Comprobado: volteada sobre el
// eje equivocado, esta misma intersección da 1254 facetas de choque.

use <sustrato.scad>
use <estampadora.scad>
include <generado/sustrato_datos.scad>

borde = est_faldon_holgura + est_faldon_pared;

// Apoyada a fondo: la punta de la nervadura llega al piso de la canaleta.
// Con la cinta puesta se queda 0,035 mm antes, que es lo que se quiere.
z_uso = sustrato_esp + est_espesor + est_sobresalir;

module estampadora_en_uso() {
    translate([sustrato_ancho + borde, -borde, z_uso])
        rotate([0, 180, 0])
            estampadora();
}

// Dos pruebas, elegidas con -D modo="..." desde tools/pcb.py:
//
//   "choque"    la interseccion de las dos piezas tiene que dar VACIA
//   "presencia" lo que la estampadora mete DENTRO de las canaletas tiene que
//               dar LLENO, y cubrir casi toda la placa
//
// La segunda existe porque la primera sola se puede aprobar por la razon
// equivocada: si las nervaduras desaparecieran, la interseccion tambien daria
// vacia y la prueba pasaria con una pieza que no sirve para nada.

modo = "choque";

// La franja de aire que hay dentro de las canaletas, entre el piso y la cara
// del sustrato. Ahi adentro tiene que haber punta de nervadura.
module franja_canaletas() {
    translate([0, 0, sustrato_esp - canaleta_prof + 0.05])
        linear_extrude(canaleta_prof - 0.10)
            square([sustrato_ancho, sustrato_alto]);
}

if (modo == "choque") {
    intersection() {
        sustrato();
        estampadora_en_uso();
    }
} else {
    intersection() {
        estampadora_en_uso();
        franja_canaletas();
    }
}

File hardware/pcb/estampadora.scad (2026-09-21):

// estampadora.scad — el negativo del sustrato, para meter la cinta de una vez.
//
// Las mismas canaletas del sustrato, pero en RELIEVE. Se apoya una hoja de
// cinta de cobre sobre el sustrato, se baja esta pieza encima y se aprieta:
// las nervaduras empujan la cinta al fondo de cada canaleta, todas juntas,
// en vez de pegar los 51 tramos uno por uno.
//
//   make pcb    regenera los datos y exporta los dos STL
//
// Tres cosas que hacen que funcione, y que son las que hay que entender si
// alguna vez se toca este archivo:
//
//   1. VA ESPEJADA EN X. Se imprime con las nervaduras hacia arriba (sin
//      soportes) y se usa dada vuelta, y dar vuelta espeja. Por eso todo el
//      modelo se construye dentro de un mirror([1,0,0]): un pad que en el
//      sustrato esta en x, acá se imprime en (ancho - x), y al voltear la
//      pieza vuelve a caer en x.
//   2. LA NERVADURA SOBRESALE MAS DE LO QUE HUNDE LA CANALETA. Con
//      est_sobresalir de más, al apretar la nervadura toca fondo y la cara
//      plana de la estampadora queda separada del sustrato: la cinta se pega
//      SOLO adentro de las canaletas y no sobre las paredes que las separan.
//      Si las dos caras se tocaran, la cinta quedaría pegada en todos lados y
//      habría que despegarla justo donde no hay que romperla. En la v3 este
//      número pasó de 0,4 a 1,0 mm: cuanto más entra la nervadura, más se
//      estira la cinta sobre el filo de la canaleta y más cerca queda de
//      cortarse sola ahí.
//   3. LA NERVADURA ES MAS FINA QUE LA CANALETA. est_holgura_lateral por lado
//      deja lugar para el espesor de la cinta doblada contra las dos paredes
//      (0,07 mm) más la tolerancia de impresión. En la v3 bajó de 0,25 a
//      0,15: es lo más cerca del corte limpio que se puede pedir con una
//      boquilla de 0,6. No se puede llegar al corte de verdad —una matriz de
//      corte para 0,06 mm de cobre pide unas micras de luz, y eso no sale de
//      una impresora FDM—, así que la cinta se marca acá y se termina de
//      separar LIJANDO la cara. Si la estampadora agarra y no baja, este es
//      el número a subir, de a 0,05.
//
// El faldón perimetral centra la pieza sobre el sustrato: no hay que apuntar
// a ojo. Entra 2,5 mm de los 3 mm de espesor del sustrato, así que nunca
// apoya en la mesa y la profundidad la sigue mandando la nervadura.

include <generado/sustrato_datos.scad>

$fn = 48;
eps = 0.01;

borde_faldon = est_faldon_holgura + est_faldon_pared;

// --------------------------------------------------------------- contornos
module contorno_sustrato(crecer = 0) {
    offset(r = crecer)
        offset(r = radio_borde) offset(r = -radio_borde)
            square([sustrato_ancho, sustrato_alto]);
}

// -------------------------------------------------------------- nervaduras
// El mismo trazado que las canaletas del sustrato, con el ancho reducido.
module tramo(a, b, ancho) {
    dx = b[0] - a[0];
    dy = b[1] - a[1];
    largo = sqrt(dx * dx + dy * dy);
    if (largo > eps) {
        translate([a[0], a[1]])
            rotate([0, 0, atan2(dy, dx)])
                translate([0, -ancho / 2])
                    square([largo, ancho]);
    }
}

module nervadura(ancho, puntos) {
    union() {
        for (i = [0 : len(puntos) - 2])
            tramo(puntos[i], puntos[i + 1], ancho);
        for (p = puntos)
            translate([p[0] - ancho / 2, p[1] - ancho / 2]) square([ancho, ancho]);
    }
}

// `extra` ensancha todo por igual: 0 para la punta, est_base_extra para el
// escalón de la base, que le da rigidez sin llegar a tocar el sustrato.
module nervaduras2d(extra = 0) {
    delta = canaleta_holg - 2 * est_holgura_lateral + 2 * extra;
    for (c = canaletas) nervadura(c[0] + delta, c[1]);
    for (p = pads)
        translate([p[0], p[1]]) rotate([0, 0, p[4]])
            translate([-(p[2] + delta) / 2, -(p[3] + delta) / 2])
                square([p[2] + delta, p[3] + delta]);
}

module nervaduras3d() {
    // Escalón de base, más ancho y bajo: cuando la pieza apoya queda por
    // encima de la cara del sustrato, así que ensancharlo no pega cinta.
    linear_extrude(est_base_alto) nervaduras2d(est_base_extra);
    // La punta, que es la que entra en la canaleta.
    linear_extrude(canaleta_prof + est_sobresalir) nervaduras2d(0);
}

// ------------------------------------------------------------------- pieza
module cuerpo() {
    linear_extrude(est_espesor) contorno_sustrato(borde_faldon);
}

module faldon() {
    linear_extrude(est_espesor + est_faldon_alto)
        difference() {
            contorno_sustrato(borde_faldon);
            contorno_sustrato(est_faldon_holgura);
        }
}

// Alivio sobre los recortes: ahí abajo no hay sustrato, y una cara plana
// empujaría la cinta al vacío y la arrugaría.
// El corte sale por encima de la cara para no dejar caras coplanares: dos
// superficies exactamente a la misma altura son ambiguas y se le notan al
// laminador antes que al ojo.
module alivio(x, y, a, h) {
    translate([x, y, est_espesor - est_relieve_hueco + 1])
        cube([a + 2, h + 2, 2], center = true);
}

module alivios() {
    for (r = recortes) alivio(r[0], r[1], r[2], r[3]);
}

// Todo lo que tiene que coincidir con el sustrato se construye en
// coordenadas del sustrato y se espeja de una vez. El translate deja la
// pieza apoyada en el primer cuadrante: mirror([1,0,0]) manda la x a
// [-(ancho+borde), borde], y el corrimiento la devuelve a [0, ancho+2*borde].
module estampadora() {
    translate([sustrato_ancho + borde_faldon, borde_faldon, 0])
        mirror([1, 0, 0]) {
            difference() {
                union() {
                    cuerpo();
                    faldon();
                }
                alivios();
            }
            translate([0, 0, est_espesor - eps]) nervaduras3d();
        }
}

module rotulo_dorso() {
    translate([(sustrato_ancho + 2 * borde_faldon) / 2,
               (sustrato_alto + 2 * borde_faldon) / 2, -eps])
        linear_extrude(0.4 + eps)
            mirror([1, 0, 0])
                text(est_rotulo, size = est_rotulo_tam, halign = "center",
                     valign = "center", font = "Liberation Sans:style=Bold");
}

difference() {
    estampadora();
    rotulo_dorso();
}

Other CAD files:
hardware/pcb/sustrato.scad
hardware/pcb/generado/sustrato_datos.scad

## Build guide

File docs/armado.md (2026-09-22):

# Armar un ROOTKIT

Paso a paso para armar una unidad desde cero, con el control de multímetro de
cada etapa y el primer encendido hecho de forma que no se pueda romper nada.
Está escrito para que alguien que no participó del diseño —o Iñaki dentro de
seis meses— arme una sin preguntar.

Antes de empezar conviene mirar [pcb.md](pcb.md) (qué es el sustrato y por
qué) y tener abierto [conexiones.md](conexiones.md) (qué va con qué). La
plantilla 1:1 está en
[`hardware/pcb/generado/plantilla-cinta.svg`](../hardware/pcb/generado/plantilla-cinta.svg).

**Tiempo, la primera vez: unas tres horas.** Después de la tercera, hora y
media.

---

## Las tres reglas

1. **El USB de la SuperMini se enchufa con el interruptor apagado.** Está
   grabado en el sustrato. El porqué está en [pcb.md](pcb.md), "Los dos USB y
   la batería": con el interruptor prendido y la celda puesta, esos 5 V
   pueden llegar a la celda sin control de carga.
2. **La celda entra último.** Todo lo que se pueda probar sin ella, se prueba
   sin ella: con una fuente de laboratorio limitada a 100 mA.
3. **Ningún paso se saltea porque "eso seguro está bien".** Cada control de
   esta guía existe porque el error que detecta es invisible hasta que ya
   quemó algo.

---

## Lo que hace falta

**De la [lista de compras](hardware.md#lista-de-compras-del-prototipo)**, más:

| Herramienta | Nota |
|---|---|
| Soldador con punta fina, 260 °C | más caliente marca el PETG |
| Estaño **Sn42Bi58** (138 °C) y flux | el común de 183 °C también va, con toques cortos |
| Lija **al agua** (carburo de silicio, la negra) de 400 y 600 | **es la herramienta que separa las pistas**: ver el paso 2. La de carpintería, naranja, no sirve: se tapa de cobre en dos pasadas |
| Un taco **rígido y plano**: un vidrio, un azulejo o una regla de acero | manda más que el grano. Con la lija en los dedos se redondean los bordes de las canaletas, que es justo donde el cobre tiene que cortarse |
| Alcohol isopropílico | entre pasada y pasada, y antes de soldar |
| Bisturí o trincheta con hoja nueva | sólo para recortar la hoja de cinta al contorno |
| **La estampadora impresa** | mete toda la cinta de una prensada (paso 2) |
| Bruñidor o el mango de una cuchara | para presionar la cinta en la canaleta |
| Multímetro con continuidad y prueba de diodo | |
| **Fuente de laboratorio con límite de corriente** | no es opcional: es lo que reemplaza a la celda hasta el paso 11 |
| Pinza de punta fina | para abrir las patas de los SOT-23 |
| Alcohol isopropílico y cepillo | el flux que queda es una fuga |

| Cable de silicona AWG30 | los 25 puentes |
| Tiras de pines macho de 2,54 mm | dos de 8 para el ESP32 y una por módulo; sirven también para probar los agujeros del cupón |

---

## Paso 0 — Imprimir

```
make pcb                       # regenera el STL y la plantilla
```

Se imprimen **dos piezas**:

| Pieza | STL | Cómo |
|---|---|---|
| El sustrato | `generado/nucleo-sustrato.stl` | **PETG**, canaletas **hacia arriba**, sin soportes, boquilla **0,6**, capa 0,2, tres perímetros. 68 × 92 × 3 mm |
| La estampadora | `generado/nucleo-estampadora.stl` | PETG o PLA, nervaduras **hacia arriba**, sin soportes, misma boquilla y capa. 73 × 97 × 8,5 mm |

Y se imprime la plantilla **al 100 %, sin ajustar a la página**.

---

## Paso 0.a — El cupón de prueba (la primera vez, sí o sí)

Media hora de impresora que evita tirar cinco placas. Son dos piezas más:

```
make cupon
```

| Pieza | STL | Medidas |
|---|---|---|
| El cupón | `generado/cupon-sustrato.stl` | 52 × 44 × 3 mm |
| Su estampadora | `generado/cupon-estampadora.stl` | 57 × 49 × 8,5 mm |

**Se imprimen con la misma boquilla, la misma altura de capa y el mismo
material que el sustrato de verdad.** Si se prueba en PLA no se prueba nada:
el PETG se estira distinto bajo la nervadura y se ablanda a otra temperatura.

Qué trae el cupón:

- **Tres grupos de canaletas, uno por profundidad**: 1,0 / 1,2 / 1,4 mm. El
  número está grabado arriba de cada grupo. El sustrato usa 1,2.
- **Cinco canaletas por grupo**: las tres anchos del sustrato (1,3 / 1,7 /
  2,5 mm de canaleta, o sea pistas de 1,0 / 1,4 / 2,2) y después **un par
  separado por exactamente 0,8 mm**, que es la pared mínima del diseño.
- **La estampadora cruza las tres con tres luces laterales distintas**:
  0,15 / 0,20 / 0,25 mm por lado, en tres franjas horizontales rotuladas en
  su dorso. Una sola prensada prueba las nueve combinaciones.
- **Una fila de ocho agujeros a 2,54 de paso, de 1,3 a 2,0 mm de a una
  décima**, que es la huella de una tira de pines. Dice cuál es el diámetro
  más chico por el que el pin entra **solo**, que no es el mismo que aquel
  con el que el agujero *se ve* abierto. Los dos extremos están rotulados.

Se hace el proceso completo del paso 2 —cubrir de cinta, recortar al
contorno, prensar, **lijar**— y se lee así:

| Qué mirar | Qué significa |
|---|---|
| ¿Bajó la estampadora sin forzar? | La franja más ajustada que entre sin agarrar es la `holgura_lateral` que hay que usar. Si ninguna entra, subir de a 0,05 |
| ¿Se rompió alguna nervadura al imprimir o al prensar? | La de 1,3 mm de canaleta con 0,25 de luz mide 0,8 mm y es la más flaca del juego: es la primera candidata |
| ¿La cinta llegó al **piso** de la canaleta, o se rompió ahí? | Si se rompe en el piso, esa profundidad es demasiada. Ésa es la respuesta a "hasta dónde se puede hundir" |
| ¿La cinta se cortó limpio en el **borde** al lijar? | Es lo que se busca. Anotar con qué profundidad y con qué luz pasó |
| Tester entre dos canaletas vecinas | **Abierto.** Si pita, faltó lija. Probar primero el par de 0,8 mm, que es el peor caso |
| ¿Sobrevivió la pared de 0,8 mm a la lija? | Si se redondeó o se rompió, hay que subir `separacion_min` en el JSON y volver a rutear |
| ¿Desde qué agujero entra el pin **sin forzar**? | Ése es `agujero_min`. Ojo: el que *se ve* abierto y el que deja pasar el pin no son el mismo |

Lo que salga de acá se anota en `hardware/pcb/nucleo.json`
(`reglas.prof_canaleta`, `reglas.agujero_min`,
`estampadora.holgura_lateral`) y se corre `make rutear && make pcb`.

> **Lo que dio la primera corrida** (21/09/2026, PETG, boquilla 0,6, capa
> 0,2): ganó la combinación del **centro**, 1,2 mm de profundidad con
> **0,20 mm de luz** por lado. Y los agujeros —que en esa corrida eran los
> ocho de 1,4 mm, sin gradiente— dejaron pasar el pin en cinco de ocho, así
> que el sustrato pasó a **1,7 mm**. Esos tres números son los que tiene hoy
> el diseño. Si cambia la impresora o el material, se vuelve a correr.

> **La cara de abajo no lleva soportes ni los necesita.** El sustrato apoya
> en la cama por una cara **completamente plana**: no hay un solo voladizo.
> Si el laminador propone soportes, algo está mal —probablemente el STL es
> viejo—, no se los pongas.

**Control 0.b — la estampadora entra.** Antes de tocar la cinta: apoyar la
estampadora sobre el sustrato vacío. El faldón tiene que envolver el borde y
la pieza bajar hasta el fondo **sin resistencia**, y las nervaduras entrar en
sus canaletas. Si hace tope antes, está al revés (mirala de nuevo: va dada
vuelta) o las nervaduras salieron gordas y hay que bajar el flujo. **Nunca
forzar**: las más finas miden 1,0 mm y se parten.

**Control 0.** Con un calibre, la regla de la plantilla impresa tiene que
medir **50,0 mm**. Si mide otra cosa, la impresora de papel la escaló y todo
lo que se corte con ella va a estar mal. Y en la pieza impresa: el ancho total
son **62,0 mm**; si la pieza mide 61,4, el filamento se contrajo y las
canaletas también — se reimprime con compensación antes de seguir.

**Control 0.c — los agujeros.** Con la punta de un calibre o un pin de tira
macho: los agujeros de los bornes son de **1,8 mm** y los de la SuperMini de
**1,4 mm**. Un pin de 0,64 mm tiene que entrar **suelto** en los dos. Si
entra a presión o no entra, la boquilla está sacando de menos: subí la
compensación de agujeros del laminador (*hole compensation* / *XY size
compensation*) y reimprimí. Es el defecto más común con boquilla de 0,6 y
arruina el paso 3 entero si se descubre tarde.

---

## Paso 1 — Medir los módulos (antes de soldar nada)

Este paso existe porque el diseño se hizo sin los módulos en la mano. Son
cuatro mediciones y cambian números del JSON, no el diseño.

**1.a — La huella de la SuperMini.** Apoyar el módulo sobre la plantilla
impresa, encima del rectángulo punteado de `U1`. Los dieciséis pines tienen
que caer sobre sus pads y los nombres tienen que coincidir uno por uno.

> Si no coinciden: corregir `huellas.esp32c3.pines` (el orden) o `pads` (las
> posiciones) en `hardware/pcb/nucleo.json`, correr `make pcb`, y volver al
> paso 0. Es un array; no hay que rediseñar nada.

**1.b — El pin 5V contra el VBUS.** Multímetro en continuidad, una punta en
el pin `5V` del header y la otra en la patita de VBUS del conector USB-C del
módulo.

- **Pita** → la placa une VBUS con 5V. La regla 1 rige siempre. Anotarlo.
- **No pita** → la placa trae diodo. La regla 1 pasa a ser prolijidad.

**1.c — El pin LED de la pantalla.** Multímetro en prueba de diodo, con el
módulo **desconectado**: punta roja en `LED`, negra en `GND`. Si marca
~2,8–3,2 V, `LED` es el ánodo de los LED de la luz de fondo, que es lo que
el sustrato asume (lo conmuta un P-MOSFET del lado alto, Q4).

Después, con el tester en resistencia entre `LED` y `VCC` del módulo:

- **Unos cientos de ohm** → el módulo ya trae su resistencia en serie:
  poblar `R11` con **0 Ω**.
- **Abierto o casi cero** → no la trae: poblar `R11` con **47–100 Ω**.
  Empezar por 100 y bajar si la luz queda floja.

**1.d — El orden de los pines de cada módulo.** Es la medición que más
importa de todas, porque los clones lo cambian entre lotes. Confirmar la
serigrafía contra la tabla del paso 5, módulo por módulo. Si alguno no
coincide, corregir su lista `pines` en el JSON y volver al paso 0.

**1.e — El chip del capacitivo.** Mirar la serigrafía: tiene que decir
**TLC555**. Si dice NE555, el sensor no arranca a 3,3 V y da lecturas planas:
se devuelve.

---

## Paso 2 — La cinta: cubrir, prensar, lijar

Se trabaja sobre la **cara de las canaletas**, con la plantilla al lado en la
misma orientación (el texto grabado se lee derecho).

El orden importa y no es el que parece. **No se corta cinta canaleta por
canaleta**: se cubre la placa entera, se prensa todo de una vez, y recién
entonces se separa lo que sobra **lijando**, no cortando. La cinta que queda
1,2 mm por debajo de la cara, adentro de los canales, la lija no la toca.

1. **Cubrir la cara entera de cinta.** Tiras del rollo de 5 mm, una al lado
   de la otra, solapadas un milímetro, hasta que no quede ni un claro sobre
   ninguna canaleta. No hay que apuntar a nada: lo que sobra se va a ir.
2. **Recortar al contorno** pasando el bisturí alrededor del canto del
   sustrato, que hace de guía. El faldón de la estampadora necesita el borde
   limpio para cerrar.
3. **Bajar la estampadora.** El faldón envuelve el borde y la centra sola. No
   hay que apuntar.
4. **Apretar parejo**, con las dos manos o —mejor— con una tabla y el peso
   del cuerpo, quince segundos. Presión repartida, no un punto. Las
   nervaduras hunden la cinta al fondo de cada canaleta y la **marcan**
   contra los dos bordes.
5. **Levantar y PELAR lo que salga solo.** Antes de tocar la lija: levantar
   una esquina del sobrante con la uña y tirar despacio, en diagonal. Si la
   estampadora marcó bien, la lámina de la superficie se desgarra sola contra
   el borde de cada canaleta y sale en pedazos grandes, dejando el cobre de
   adentro en su lugar. Lo que salga acá es lo que no hay que lijar. **Si
   algo tironea de adentro de una canaleta, parar y lijar esa zona**: no
   insistir.
6. **Lijar el resto.** Es el paso que decide si la placa sirve, y tiene su
   propia sección abajo.
7. **Soplar y limpiar con alcohol.** El polvo de cobre de la lija es
   conductor: si queda en el fondo de una canaleta no molesta, pero si queda
   sobre una pared es exactamente el puente que se acaba de lijar.
8. **Cada esquina y cada empalme lleva una gota de estaño.** El adhesivo no
   es una conexión. Toque corto: apoyar, estañar, retirar, contar hasta tres
   antes del siguiente.

### Cómo se lija

Lo que hay que sacar es una lámina de **0,035 a 0,07 mm** de cobre pegada
sobre PETG. Es poquísimo material, y el riesgo no es quedarse corto: es
pasarse y redondear el borde de las canaletas, que es justo donde el cobre
tiene que quedar cortado. Todo lo de abajo apunta a eso.

| | |
|---|---|
| **Grano** | **400 al agua** para el grueso, **600 al agua** para terminar |
| **Tipo** | **Carburo de silicio** ("lija al agua", la negra o gris oscura). La de óxido de aluminio —la naranja de carpintería— se tapa de cobre y adhesivo en dos pasadas y a partir de ahí bruñe en vez de cortar |
| **Nunca** | por debajo de **320**: muerde el PETG y redondea el borde de la canaleta. Ni por encima de **800**: no corta el cobre, lo pule |
| **Taco** | **rígido y plano**, con la lija pegada o envuelta: un pedazo de vidrio, un azulejo, una regla de acero ancha. Nunca en los dedos ni sobre una esponja |
| **Mojada** | agua con una gota de detergente. El PETG se ablanda a ~80 °C, y lijar en seco y rápido lo calienta, lo embarra y le incrusta el cobre |
| **Presión** | el peso del taco y nada más. Apretar no acelera: calienta y redondea |
| **Dirección** | a **45° de las canaletas**, cruzando en las dos diagonales. Nunca a lo largo de una canaleta: eso arrastra cobre hacia adentro |
| **Cuándo parar** | cuando la cara se ve de PETG parejo y el cobre queda sólo en los canales. Mirarla a contraluz y de costado: el cobre que sobra aparece como una raya brillante sobre una pared |

**Por qué a 45° y con taco rígido.** El taco rígido apoya sobre las paredes y
**puentea** las canaletas: la lija no llega al fondo por geometría, no por
pulso. A 45° el taco está siempre apoyado sobre varias paredes a la vez,
mientras que paralelo a las canaletas puede caer dentro de las más anchas
(2,5 mm) y tocar el cobre bueno.

**Cuánto se puede sacar.** Menos de **0,1 mm**. La canaleta tiene 1,2 mm de
profundidad, así que hay margen de sobra para el cobre, pero cada décima que
se lija es una décima menos de placa y de largo de agujero. Si después de dos
minutos con la de 400 todavía hay cobre, no es que falte presión: es que la
lija se tapó. Enjuagarla.

> **El enemigo no es el cobre, es el adhesivo.** El acrílico de la cinta
> empasta cualquier lija en seco. Mojada se va con el agua. Si la lija se
> pone marrón y empieza a resbalar, enjuagarla bajo la canilla y seguir.

> **Lo que NO usar.** Minitorno o Dremel: se come una pared de 0,8 mm en un
> parpadeo. Esponja abrasiva o taco de espuma: se amolda y redondea los
> bordes. Lana de acero: deja fibras de hierro entre las pistas, que es una
> fuga y además se oxida. Lima: demasiado agresiva para 0,05 mm.

**Después de lijar, antes de soldar: limpiar con alcohol isopropílico** y un
cepillo blando, y secar. Quedan dos cosas: polvo de cobre y restos de
adhesivo. El polvo entre dos canaletas es el puente que se acaba de sacar, y
el adhesivo sobre el cobre bueno es lo que hace que el estaño no moje. Este
proyecto se juega los meses de batería en microamperios de fuga
(`RK_REPOSO_OBJETIVO_UA`), así que la limpieza no es prolijidad.

> **Por qué lijar y no cortar.** Hasta la v2.0 había que pasar el bisturí por
> el canto de cada una de las 76 canaletas. Con canaletas de 1,2 mm de
> profundidad y una nervadura que entra 1,0 mm más allá de la cara, la cinta
> queda tan estirada sobre el borde que se rompe sola con la lija. Es una
> operación de treinta segundos en vez de media tarde, y sobre todo: no
> depende del pulso.

> **Lo que la estampadora NO hace es cortar.** Una matriz de corte para
> 0,06 mm de cobre trabaja con unas micras de luz entre punzón y matriz; una
> boquilla de 0,6 mm da 0,15 mm. La nervadura marca; la lija corta.

**Control 2.a — aislación entre canaletas vecinas.** Éste va **primero**,
antes que el de continuidad, porque es el que dice si faltó lija. Tester en
continuidad, recorriendo la plantilla: dos canaletas vecinas de redes
distintas tienen que dar **abierto**. Si alguna pita, volver a lijar ese
tramo.

**Control 2.b — continuidad de cada red.** Para cada red de
[conexiones.md](conexiones.md), tocar el nodo más lejano contra el más
cercano de la lista: **tiene que pitar**. Las de masa se prueban contra
`TP1`, que es el punto negro del tester de acá en adelante.

**Control 2.c — aislación entre rieles.** Con el tester en resistencia, y
**nada más soldado**:

| Entre | Tiene que dar |
|---|---|
| `TP1` (GND) y `TP3` (3V3) | abierto |
| `TP1` y `TP2` (VIN) | abierto |
| `TP1` y `TP4` (3V3S) | abierto |
| `TP2` y `TP3` | abierto (todavía no está la SuperMini) |
| `TP3` y `TP4` | abierto (todavía no está Q2) |

Si alguno da un valor bajo, hay una rebaba de cinta o un puente de estaño.
Se busca con lupa antes de seguir: después va a estar tapado por un módulo.

---

## Paso 3 — Los puentes de cable

Los 25 de la tabla de [conexiones.md](conexiones.md), en ese orden, con cable
de silicona **AWG30**.

Van **por arriba** de la cinta, cruzando lo que tengan que cruzar, pegados al
sustrato con una gota de cianoacrilato cada 15 mm para que no bailen.

Quince de los 25 son de masa y de 3V3, y eso es a propósito: en una sola
cara de cobre las dos redes que tocan todo no se pueden cerrar sin cruces, y
si alguien tiene que llevar un cable por arriba, que sea la masa —no tiene
señal que degradar y, si hiciera falta, se refuerza con otro en paralelo—.
Ninguna señal lleva puente salvo dos, `SCL` y `OW`, y las dos están
explicadas en [pcb.md](pcb.md).

> **Los que dicen "rodeando" no van derecho.** El camino corto les cruzaría
> la muesca de la antena o un agujero de tornillo, y ahí el cable quedaría
> apretado. La plantilla los dibuja por donde van: seguila.

**Control 3.** Tachar cada puente de la lista al soldarlo y volver a hacer el
**control 2.a completo**. Es el momento más fácil para olvidarse uno, y el
más barato para encontrarlo.

---

## Paso 4 — Los componentes chicos

En este orden: resistencias y capacitores (1206) y después los MOSFET. Son
once piezas y todas viven en el sustrato; el Schottky y el MOSFET de carga
compartida ya no están acá, se arman en el arnés del paso 6.

- **1206**: flux, estañar un pad, apoyar con pinza, soldar el otro lado,
  rehacer el primero.
- **SOT-23**: abrir las dos patas del mismo lado 0,2 mm con la pinza hasta
  que caigan en sus pads (están a 2,3 mm, no a 1,9). Soldar primero la pata
  sola del otro lado.
- **C2** (el electrolítico de 220–470 µF) va **parado**, con cada pata en su
  agujero. **Ojo con la polaridad**: la franja blanca va del lado de masa,
  que es `C2.1` en la plantilla.

**Lo que NO se puebla** salvo que el paso 1 diga lo contrario: nada. El
valor de `R11` sí sale del paso 1.c.

**Control 4 — los valores, otra vez.** Medir en la placa, con el tester en
resistencia:

| Entre | Esperado |
|---|---|
| `TP2` (VIN) y `TP1` (GND) | **940 kΩ ±10 %** (el divisor: 470 k + 470 k) |
| `TP3` (3V3) y `TP1` | **> 100 kΩ** (si da menos, hay un corto o C2 al revés) |
| `TP1` y el pad `G` de Q3 | **100 kΩ** (R8) |
| `TP3` y el pad `G` de Q2 | **100 kΩ** (R4) |

---

## Paso 5 — Clavar los módulos

Desde el sustrato v3.0 no hay bornes ni cables: **cada módulo se clava**. Se
le suelda su tira de pines macho, los pines pasan por los agujeros del
sustrato, y se sueldan **del lado de las canaletas** contra la cinta.

| Tira | Módulo | Pines |
|---|---|---|
| `J_TFT` | TFT 2,2" ILI9341 | 9: VCC, GND, CS, RESET, DC, SDI, SCK, LED, SDO |
| `J_AIRE` | SHT21 / HTU21 / Si7021 | 4: VCC, GND, SCL, SDA |
| `J_LUZ` | BH1750 GY-302 | 5: VCC, GND, SCL, SDA, ADDR (al aire) |
| `J_SUELO` | capacitivo de suelo | 3: AOUT, GND, VCC |
| `J_TOQUE` | TTP223 | 3: IO, GND, VCC |
| `J_TIERRA` | DS18B20 | 3: DQ amarillo, GND negro, VCC rojo. **No** en modo parásito |
| `J_PWR` | arnés de la batería | 2: VIN, GND |

El mapa completo —el tamaño exacto de cada huella, y pin por pin de qué red
es y contra qué pin del ESP32 queda— está en
[conexiones.md](conexiones.md), sección "El mapa de montaje". Se genera del
mismo dato que la placa, así que no puede contradecirla.

> **Mirar la serigrafía del módulo ANTES de clavarlo.** Es el único paso de
> esta guía que puede salir mal de una manera que no se arregla: los clones
> cambian el orden de los pines entre lotes. El sustrato está hecho para los
> órdenes de la tabla de arriba. Si alguno no coincide, **no se improvisa con
> cables**: se corrige la lista `pines` de ese componente en
> `hardware/pcb/nucleo.json`, se corre `make rutear && make pcb`, y la placa
> se reordena sola. Son diez minutos y una impresión.

> **Cuidado con `J_TFT`.** Los pines están rotulados con el nombre **del
> módulo**, no con el de la red: `SDI` del módulo es el MOSI del ESP32 y
> `SCK` es su SCK. Y `SDO` (el MISO) **queda al aire a propósito**: el
> firmware nunca lee del panel.

> **El capacitivo tiene GND en el medio a propósito.** Si se clava al revés,
> lo que se cruza son VCC y la salida analógica —que el ADC aguanta— y no la
> alimentación del módulo.

**Control 5.** Con el tester en continuidad y **antes** de soldar, apoyar
cada módulo en su tira sin presionar y comprobar tres pines de cada uno
contra el `TP` de su riel: `VCC` contra `TP3` (3V3), `GND` contra `TP1`. El
`VCC` del capacitivo va contra `TP4` (3V3S), no contra `TP3`.

---

## Paso 6 — El arnés de la batería

Desde la v3.0 **la etapa de carga no vive en el sustrato**. Es un arnés
aparte, que se arma sobre el propio módulo TP4056 y entra a la placa por los
dos pines de `J_PWR`. El esquema completo está en
[hardware.md](hardware.md), "Batería y carga"; en resumen:

```
   USB-C ─► TP4056+DW01A ─► OUT+ ─┬─ AO3401 (carga compartida) ─┐
              B+/B− a la celda    │                              ├─ interruptor ─► J_PWR.VIN
   5 V del USB ─► SS34 ───────────┘                              │
   OUT− ──────────────────────────────────────────────────────────► J_PWR.GND
```

> **El negativo de la celda va al `B−` del TP4056**, no a masa. Si se une a
> masa se puentean los MOSFET del DW01A y la celda queda **sin protección de
> sobredescarga ni de cortocircuito**. Es el error más caro de esta guía, y
> ahora ocurre fuera de la placa, donde no hay una canaleta que lo impida:
> mirarlo dos veces.

**Control 6 — el arnés, solo, sin la placa.**

1. Interruptor **apagado**, `J_PWR` sin conectar a la placa.
2. Fuente de laboratorio a **3,7 V, límite 200 mA**, en lugar de la celda
   (rojo al `B+`, negro al `B−`).
3. Enchufar el USB del cargador. El LED rojo del TP4056 se enciende.
4. Medir el `OUT+` contra el `OUT−`: **3,7 V**, lo que pusiste.
5. Medir el nodo de sistema (después del SS34 y el AO3401) contra `OUT−`:
   **4,5–4,7 V**. Son los 5 V del USB menos el Schottky. **Si da 3,7 V, el
   SS34 está al revés o el AO3401 conduce cuando no debe.**
6. Medir la salida del interruptor: **0 V**, porque está apagado.
7. Desenchufar el USB. El nodo de sistema tiene que pasar a **3,7 V**: ahora
   come de la "celda" por el AO3401. **Si queda en 0, el AO3401 no conduce**:
   mirá su orientación (la pata sola es el drenador y va del lado de la
   celda).

Este control prueba la carga compartida entera sin arriesgar la placa.

**Control 6.b — el arnés contra la placa.** Con el arnés todavía sin celda y
el interruptor apagado, conectar `J_PWR` y medir `TP2` (VIN) contra `TP1`:
**0 V**. Prender el interruptor: `TP2` pasa a los 3,7 V de la fuente.

---

## Paso 7 — La SuperMini

Soldar una tira de pines macho al módulo (pines hacia el lado de los
componentes), pasarlos por los agujeros del sustrato y soldarlos del lado de
la cinta. El módulo queda del lado plano, con la **antena mirando al borde de
arriba** y asomando por la muesca.

> **Acá los pads no rodean el agujero: están al lado.** A 2,54 mm de paso, con
> boquilla de 0,6, un anillo completo de cobre no entra ([pcb.md](pcb.md)).
> Así que el pad de cada pin está **pegado al borde de su agujero**, y van
> alternados: uno para afuera, el siguiente para adentro. El agujero en sí
> queda pelado.
>
> Se suelda así: el pin asoma por el agujero, se le arrima la punta del
> soldador **del lado donde está su cinta** —mirá la plantilla si dudás— y se
> deja correr una gota que moje el pin y la cinta a la vez. No hay que doblar
> el pin. Si la gota se va para el lado que no es, no toca nada: no hay cobre
> ahí, y se saca con malla.
>
> **Control: ningún pin unido a su vecino.** Tester en continuidad entre
> pines contiguos de la misma fila. Con los pads alternados un puente de
> estaño es menos probable que antes, pero si aparece, aparece acá.

**Antes de soldar**, con la placa suelta:

- **Desoldar el LED rojo de encendido** si lo tiene, o cortarle la pista con
  el bisturí. Son 1–3 mA permanentes: a batería es la diferencia entre seis
  meses y tres semanas.
- Anotar en el cuaderno si esa placa tiene LED azul en GPIO8; va a parpadear
  cada vez que se lea la sonda de tierra. Es cosmético.

**Control 7 — ningún corto antes de alimentar.** Tester en resistencia:

| Entre | Esperado |
|---|---|
| Pin `3V3` y pin `GND` de la SuperMini | **> 10 kΩ** |
| Pin `5V` y pin `GND` | **> 100 kΩ** |
| Pin `3V3` y pin `5V` | **abierto** |

Si alguno da bajo, hay una pata puenteada. **No alimentar.**

---

## Paso 8 — El primer encendido, con fuente

Todavía sin celda y sin sensores.

1. Interruptor **apagado**. Sensores **desconectados**.
2. Fuente a **3,8 V, límite 100 mA**, en lugar de la celda del arnés.
3. **Prender el interruptor.**
4. **Mirar el amperímetro de la fuente en ese instante.** Tiene que subir a
   **20–60 mA** y quedarse ahí. Si salta al límite de 100 mA, **apagar** y
   buscar el corto: la fuente acaba de salvar la placa.
5. Medir `TP3` (3V3) contra `TP1`: **3,25–3,35 V**.
6. Medir `TP2` (VIN) contra `TP1`: **3,8 V**, lo de la fuente.

Recién ahora el aparato está vivo.

---

## Paso 9 — El consumo en reposo

El número que decide si el producto dura seis meses o tres semanas.

1. Con el firmware ya cargado (paso 10) el aparato se duerme solo a los
   pocos segundos. En el primer armado, este control se hace **después** del
   paso 10 y se vuelve acá.
2. Fuente a **3,8 V**, en serie con un multímetro en **µA**, o con un PPK2.
3. Esperar a que la pantalla se apague y el aparato entre en sueño profundo.
4. **Esperado: 50–90 µA.** El presupuesto de [pcb.md](pcb.md) da 68.

| Si medís | Mirá |
|---|---|
| **> 200 µA** | flux sin limpiar entre pistas, el LED de encendido todavía puesto, o un pull-up de I2C duplicado |
| **> 1 mA** | el riel de sensores quedó prendido: Q2 conduce. Revisar R4 y el estado de GPIO2 |
| **> 5 mA** | la pantalla no se durmió, o el TP4056 tiene el USB enchufado |

**Limpiar el flux y volver a medir** es parte del control, no un extra.

---

## Paso 10 — Flashear y fábrica

> **Interruptor APAGADO.** Está grabado al lado del módulo. Ver la regla 1.

1. Apagar el interruptor. Desconectar la fuente.
2. Enchufar el USB **de la SuperMini** a la computadora.
3. Compilar y cargar:
   ```
   cd firmware && pio run -e c3-144 -t upload
   ```
   Si no entra en modo descarga: mantener el botón **BOOT** de la SuperMini
   apretado mientras se enchufa.
4. Registrar la placa en la estación de fábrica ([fabrica.md](fabrica.md)):
   ```
   python3 tools/fabrica.py --puerto COM7 --persona brote
   ```
   Esto le graba el secreto y el Rooti que le toca. **La nube de producción
   no acepta placas sin registrar.**
5. Desenchufar el USB de la SuperMini.

**Control 10.** En el monitor serie (`pio device monitor`), al arrancar tiene
que aparecer el banner con la versión y `[almacen]` sin errores.

> **Lo que se ve al encender, y es normal:** la luz de fondo puede
> **pestañear unos 50 ms**. GPIO21 es el TX del UART0 y la ROM del C3 escribe
> ahí su log de arranque antes de que corra el firmware. No es una falla. Si
> molesta de noche —el aparato despierta cada 2 a 30 minutos—, hay dos
> salidas, ninguna urgente: silenciar el log de ROM con el eFuse
> `UART_PRINT_CONTROL` desde la estación de fábrica (verificar sus opciones
> en el ESP-IDF antes de quemarlo: los eFuses no se deshacen), o intercambiar
> BL y CS en `placa.h`, el JSON y `hardware.md`, poniendo la luz en GPIO20,
> que es el RX y la ROM no maneja. Lo segundo hay que medirlo antes: si el RX
> tiene pull-up interno al arrancar, es peor el remedio.

---

## Paso 11 — La celda

**Recién ahora.**

1. Interruptor **apagado**.
2. Confirmar otra vez que el negativo de la celda, en el arnés, da abierto
   contra `TP1`.
3. Medir la celda con el tester: **3,2–4,1 V**. Si vino abajo de 2,5 V,
   descartarla.
4. Poner la celda en el portapilas mirando la polaridad del portapilas, que
   está marcada en el plástico.
5. Medir `TP2` (celda protegida) contra `TP1`: tiene que dar **lo mismo que
   la celda**. Si da 0 V, el DW01A está en corte: enchufar el USB del
   cargador un segundo para que "despierte".
6. Prender el interruptor. `TP5` = 3,3 V, y el aparato arranca.

---

## Paso 12 — Los sensores, uno por uno

Con el aparato andando y el monitor serie abierto, conectar **de a uno** y
mirar la lectura. Así, cuando algo falla, se sabe qué.

| Orden | Sensor | Qué tiene que pasar |
|---:|---|---|
| 1 | SHT21 (o AHT20) | temperatura y humedad creíbles; comparar contra un termohigrómetro. **Si no aparece en el log, es el driver**: el firmware habla con uno o con el otro según `-DRK_AIRE_SHT21` (ver `platformio.ini`) |
| 2 | BH1750 | tapar con la mano: los lux caen a menos de 10 |
| 3 | TTP223 | tocar: `[boton]` en el log, la pantalla se enciende |
| 4 | DS18B20 | temperatura cerca de la del aire; con los dedos en la sonda sube |
| 5 | Capacitivo | en el aire, un número; en un vaso de agua hasta la línea, otro **bien distinto** |
| 6 | Pantalla | el QR se lee desde un teléfono a 30 cm |

**Control 12 — el capacitivo contra el ADC.** Con el capacitivo seco y el
riel de sensores prendido (durante una medición), medir su `AOUT` contra
masa. **Tiene que dar menos de 2,5 V.** Por encima de eso el ADC del C3 a
11 dB satura y el sensor pierde la mitad de su rango.

> Si da más: soldar un divisor **100 k / 220 k** en los propios pines de
> `J_SUELO` (100 k en serie desde `AOUT`, 220 k de ahí a `GND`), y poner
> `RK_SUELO_DIVISOR_NUM` = 220000 y `RK_SUELO_DIVISOR_DEN` = 320000 en
> `esp32.promesas` del JSON para que quede escrito lo que hace la placa.

**Control 12.b — el riel conmutado.** Tester en `J_SUELO.VCC` contra `TP1`:
**0 V entre mediciones**, 3,3 V durante los ~400 ms que dura una. Si marca
3,3 V todo el tiempo, Q2 quedó conduciendo.

---

## Paso 13 — Cerrar

1. **Limpiar el flux** con alcohol isopropílico y cepillo, de los dos lados.
   Secar bien.
2. **Rehacer el paso 9** (consumo en reposo). El flux limpio se nota.
3. **Barnizar**: tapar los seis puntos de prueba con cinta de papel, dos
   manos de barniz acrílico en aerosol sobre la cara de la cinta, veinte
   minutos entre manos.
4. **Sellar el borde del capacitivo** con esmalte de uñas o epoxi: el canto
   de esa placa absorbe agua y en un mes la lectura deriva. Sellar también el
   circuito, no sólo el canto.
5. Montar el sustrato en la carcasa con los cuatro **M2**. La pantalla ya no
   pasa por el sustrato: la sostiene la carcasa. El
   apoyo de la pantalla lo da el marco de la carcasa, no el sustrato.
6. La junta del capacitivo **abajo**, y el cable **haciendo panza** para que
   el agua gotee antes de llegar a la placa.

---

## Qué anotar de cada unidad

Un renglón por aparato, que después vale oro:

```
unidad ___  fecha ______  sustrato v2.0
  SuperMini: 5V unido a VBUS?  si / no     LED de encendido: sacado / no tenia
  pantalla: BL = anodo / catodo            JP_BL: C-A / C-B
  area activa a ___ mm del borde
  capacitivo seco: ____ mV   mojado: ____ mV   chip: TLC555 / otro
  reposo medido: ____ uA (antes de limpiar) / ____ uA (despues)
  RSSI dentro de la carcasa: ____ dBm   al aire: ____ dBm
  celda: marca ________  mAh ____  tension al montar ____ V
```

---

## Si algo no anda

| Síntoma | Primer lugar donde mirar |
|---|---|
| No enciende nada | `TP5` contra `TP1`: si no hay 3,3 V, el problema está antes del regulador. `TP4` y el interruptor |
| Enciende y se reinicia solo | celda baja (< 3,5 V) o un corto intermitente en el pico de wifi; C2 mal soldado |
| No entra en modo descarga | apretar BOOT mientras se enchufa. Si la placa tiene el LED de encendido sacado, verificar que no se cortó otra pista |
| La pantalla queda negra | `TP5` en el borne `VCC` de `J_TFT`; después el selector `JP_BL`; después los cables SCL/SDA, que son SCK/MOSI |
| La imagen sale corrida o con colores cambiados | `RK_TFT_OFS_X/Y`, `RK_TFT_BGR`, `RK_TFT_INVERT` en `platformio.ini`. Es de configuración, no de hardware |
| La imagen sale con basura | bajar el SPI: `-DRK_TFT_SPI_HZ=20000000` |
| La luz de fondo no prende | el paso 1.c estaba mal: cambiar el lado de `JP_BL` |
| La luz prende sola en reposo | falta R8 (o R10), o GPIO21 quedó flotando |
| El suelo lee siempre lo mismo | chip NE555 en vez de TLC555, o el riel conmutado no prende (control 12.b) |
| La estampadora no baja hasta el fondo | está al revés (va dada vuelta), o las nervaduras salieron gordas: bajar el flujo un 3 % y reimprimir |
| Quedó cinta pegada sobre las paredes | se apretó de más y la cara plana llegó a apoyar; o la hoja tenía un solape justo ahí |
| No aparecen AHT20 ni BH1750 | SDA y SCL cruzados; o faltan los pull-ups porque **ninguno** de los dos módulos los trae |
| Sólo falla el DS18B20 | el pull-up de 4,7 k (R6), o la sonda en modo parásito |
| El reposo da más de 200 µA | flux, LED de encendido, pull-ups duplicados. En ese orden |
| Carga eterna, nunca termina | Q1 no conduce: el aparato está comiendo del cargador en vez del USB |
| La celda se calienta cargando | **desconectar ya.** El AO3401 del arnés al revés, o el negativo de la celda unido a masa |

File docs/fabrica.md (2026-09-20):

# La estación de fábrica

Cada ROOTKIT sale de la caja con dos cosas grabadas que no vienen en el
firmware: su **secreto** (16 bytes al azar, de donde salen el token con el
que habla con la nube y el código de su QR) y su **Rooti** (la figura que
lleva puesta: Kip, Nori, Blink, Plum o Blink). Y la nube tiene que
conocerlo de antemano: en producción, una placa que no pasó por acá **no
entra** (`ROOTLAB_TOFU=emulador`).

## El paso a paso

```bash
set ROOTLAB_ADMIN_CLAVE=...       # la del servidor; nunca en la línea de comandos
~/.platformio/penv/Scripts/python tools/fabrica.py --puerto COM5 \
    --persona kip --lote L2609 --nube https://ifbotech.com/rootkit --flashear
```

1. **Flashea** el firmware (`--flashear`, con PlatformIO; se puede saltear si
   ya está).
2. **Genera el secreto** y se lo manda al aparato por el puerto serie, con el
   Rooti y el lote.
3. **Le pregunta quién es**: la MAC (su id) y el código del QR.
4. **Lo registra en la nube** (`POST /api/admin/aparatos`) con el **hash de
   su token**. La nube nunca ve el secreto, y el programa tampoco lo guarda:
   vive sólo en la NVS del aparato.
5. **Escribe la etiqueta** (`build/etiquetas/<id>.svg`, 50 × 30 mm): el
   Rooti, el lote y el código de respaldo, para cuando la cámara no lee el
   QR.

`--consultar` sólo pregunta (para reimprimir una etiqueta); `--canal beta`
deja al aparato en el canal beta de actualizaciones; `--sin-nube` graba sin
registrar (banco de pruebas); `--autoprueba` verifica, sin placa, que la
derivación del token es la misma que la del firmware y la de la nube (corre
en CI).

## El protocolo (`core/fabrica.h`)

Una línea por el puerto serie, a 115200:

```
FABRICA {"secreto":"3a917c05ee4218b69d602fc3710e845b","persona":"kip","lote":"L2609"}
  -> {"fabrica":true,"grabado":true}
FABRICA?
  -> {"fabrica":true,"id":"A1B2C3D4E5F6","persona":"kip","lote":"L2609","codigo":"K7Q2M9XA","fw":"0.6.0","vinculado":false}
```

El aparato valida: secreto de 32 hexadecimales y que no sea todo ceros, un
Rooti que exista, un lote de letras, números y guiones. Cualquier otra cosa:
`{"fabrica":false,"error":"orden invalida"}`. Al grabar, recalcula el token y
el código, y el QR de la pantalla cambia en el acto.

**Sólo sin vincular.** Una maceta que ya es de alguien contesta
`{"fabrica":false,"error":"vinculado"}` y no cambia nada. Quien tiene el
cable y la placa en la mano tiene todo de todas formas (puede reflashear);
esta regla evita el accidente, no al atacante.

## Qué gana la nube

- **Nadie registra aparatos inventados**: sin el hash del token cargado por
  la fábrica, el sync de una placa desconocida responde `401`.
- **Lo que grabó la fábrica manda**: el Rooti y el lote no se pueden cambiar
  desde el firmware.
- **Un lote se puede retirar entero** (`PATCH /api/admin/lotes/<lote>
  { "deshabilitado": true }`) o pasar a beta.

Las placas de desarrollo siguen andando sin pasar por acá contra un servidor
local (`ROOTLAB_TOFU=1`): si la NVS no tiene secreto, el firmware genera uno.

## Probarlo sin placa

`make test` cubre el protocolo (suite `ota y fabrica`): órdenes válidas,
secretos cortos o en cero, Rooties que no existen, lotes raros, líneas del
log que no son órdenes, y las respuestas. `tools/fabrica.py --autoprueba`
cubre la derivación. En root-lab, `test/fabrica.test.mjs` cubre el registro,
los modos de confianza y deshabilitar.

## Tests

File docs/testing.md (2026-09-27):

# Pruebas

```bash
make test        # 2277 comprobaciones del firmware, sin placa ni SDL
make verify      # lo que corre CI: pruebas, referencias visuales y sustrato
make pcb         # verifica el sustrato impreso y regenera lo que sale de él
make placa       # compila el producto (c3-144) y el banco (devkit-144)
```

ROOTLAB (la app, la nube y el emulador) tiene sus propias 543 pruebas en
[root-lab](https://github.com/ifbotech/root-lab) (`npm test`), incluido el
flujo completo de punta a punta.

## Qué cubre cada suite

| Suite | Comprobaciones | Qué protege |
|---|---:|---|
| `animo` | 28 | Prioridad entre necesidades, ciclo día/noche, histéresis, nodo caído |
| `nodo` | 91 | Calibración de suelo, fallas eléctricas, el riego que se escurre, curva de batería, muestreo adaptativo |
| `sensores e historial` | 77 | AHT20, BH1750 y DS18B20 con los vectores de las hojas de datos, CRC, riel y USB, sensores caídos, historial en flash |
| `graficos` | 63 | Recorte, tipografía, **antialiasing**: cobertura, bordes mezclados, triángulos en cualquier orden, alfa |
| `cara` | 414 | Determinismo, batería sin íconos, cara dormida que no delata la piel, despertar con la piel, regresión visual de las 165 caras, la transición entre ánimos (extremos idénticos a las caras fijas, el medio distinto, el reloj con desborde), la cara de mimos (en 0 la del ánimo, en 100 otra, ronronea), la mirada dirigida y la preocupación |
| `rooties y caras` | 1023 | La tabla de los cinco Rooties con sus tres pieles y colores, las rarezas (ids, nombres, parseo), que los 5, las 15 pieles y los 11 ánimos se distingan, el guiño, adornos por etapa y por piel, centinelas del framebuffer |
| `pantalla del QR` | 19 | Que el QR dibujado se lea módulo por módulo (en 128×128 y en un lienzo más grande), también con la URL del VPS |
| `identidad y vinculo` | 91 | SHA-256 y HMAC con vectores oficiales, código y token, el flujo completo del enlace y sus caminos feos |
| `nube` | 98 | JSON hostil o cortado, el cuerpo del pedido, respuestas incoherentes que no se aplican; a qué URL se le puede mandar el token (sólo `https://` exacto en el producto, sin usuario ni caracteres raros) |
| `sustrato y placa.h` | 217 | Que el sustrato impreso y el firmware digan lo mismo: cada GPIO en su red, los analógicos en el ADC1, el toque en un pin que despierta, los tres pines de arranque en alto, el 1-Wire y su pull-up en el mismo riel, el divisor del riel, y las trampas del banco (ADC2, ext0, pines sólo de entrada) |
| `ota y fabrica` | 104 | Versiones, hex y base64; manifiestos hostiles o a medias; cuándo se baja una versión (batería, tres intentos, volver atrás) y el arranque a prueba; el cuerpo del sync con `ota` y `lote`; la línea de fábrica: secretos cortos o en cero, Rooties que no existen, lotes raros, el log que no es una orden |

## El sustrato también se verifica, aparte

`make test` cruza el sustrato con `placa.h`, pero la **geometría** de la PCB
impresa se verifica en Python, porque es geometría:

```bash
python3 tools/pcb.py --verificar     # y dentro de `make verify` y de CI
```

Revisa que ninguna canaleta quede a menos de 0,8 mm de otra, que cada red
quede en **una sola pieza** contando pistas y puentes, que nada de cobre
entre en la ventana, los recortes o los tornillos, que se respete la zona
libre de la antena y que el texto grabado no muerda una pista. Y CI falla si
los archivos que salen del dato —la plantilla de corte, el diagrama de
conexiones y `test/redes.h`— no están commiteados al día, por la misma razón
que `golden.h`: una plantilla vieja se imprime igual de bien y arma una placa
que no anda.

**Las reglas que salieron de una placa impresa.** Cuatro de las catorce nacen
de mirar una pieza real en la mesa, no de pensar:

| Regla | El defecto que la trajo |
|---|---|
| Agujero mínimo y pared entre agujeros | con boquilla de 0,6 los agujeros de 1,0 mm salían tapados y el pin no entraba |
| La cara de abajo es un plano | la repisa de la ventana y el bolsillo del cargador eran voladizos sobre la primera capa |
| Ningún puente cruza la ventana | el cable quedaba apretado entre la pantalla y el plástico |
| Ninguna canaleta pasa por el agujero de otra red | el agujero corta la cinta |

Las tres primeras tienen **control negativo**: se le devuelve el defecto al
modelo y la regla tiene que saltar. La de la base plana, por ejemplo, con la
repisa puesta a propósito denuncia 115,9 mm² de techo colgando a 1,40 mm de
la cama. Una prueba que nunca falló no demostró nada.

**El ruteo no se verifica por fecha, se verifica por geometría.** Las pistas
las genera `tools/ruteo.py` y viven commiteadas en
`hardware/pcb/generado/ruteo.json`. No se regeneran en cada build —tardan y
no hacen falta— así que no tiene sentido comparar archivos. Lo que se
comprueba es más fuerte: un ruteo viejo, hecho para otra planta, deja una red
en dos pedazos o dos canaletas demasiado juntas, y eso el verificador lo
dice.

## Las pruebas que valen más que su tamaño

**Que un manifiesto raro nunca haga bajar algo.** Una versión que no es una
versión, una URL que no es http, un hash corto, una firma diminuta, un tamaño
que no entra en la partición: el manifiesto queda en cero y el resto del sync
se aplica igual. Y una versión que ya falló tres veces no se vuelve a bajar.

**Que la fábrica no le cambie la identidad a una maceta con cualquier cosa.**
La línea del puerto serie se valida entera antes de tocar la NVS, y un
aparato vinculado la rechaza.

**Que los cinco Rooties y sus quince pieles se vean distintos.** Es la que sostiene el producto: si
dos carcasas dan la misma cara, la caja ciega vende dos veces lo mismo y no hay
colección que juntar. Se renderizan los ocho y se comparan por hash, todos
contra todos.

**Que los once ánimos se distingan DENTRO de cada modelo.** Son 55 pares por
modelo, 330 comparaciones. Un modelo que pone la misma cara para sed y para
frío no comunica nada, y con un rig procedural es fácil que dos ánimos colapsen
en la misma forma sin que nadie lo note. La versión anterior de este test ya
había encontrado tres estados compartiendo dibujo.

**Que el QR se lea.** Se dibuja la pantalla y se lee el framebuffer módulo
por módulo contra la matriz del QR, en 128×128 y en 240×320. Un corrimiento
de un pixel en el layout deja un QR que se ve perfecto y que ningún teléfono
lee; eso se descubre acá y no con la caja abierta.

**Que la placa y el servidor deriven el mismo código.** Los vectores de
[nube.md](nube.md) se calcularon aparte con Python y se verifican en C y en
Node. Si un lado cambia la derivación, ningún QR vincula nada.

**Los caminos feos del vínculo.** Contraseña mal tipeada, router que se
reinicia, nube que contesta antes que el wifi, cofre abierto con la maceta sin
red, desvincular a mitad del despertar, botón largo desde la cara. Cada uno es
un test que recorre la máquina de estados.

**Que un portal de hotel no desvincule una maceta.** Una respuesta HTML, sin
`"ok": true`, o cortada a la mitad, no se aplica.

**Que un sensor caído no invente un problema.** Sin AHT20 la temperatura
queda en cero; el test verifica que la planta no tenga "frío".

**Que las rarezas sean las que publica la app.** Tres pieles por Rooti, en el
orden común, rara, épica, con los ids que manda la nube (`comun`, `raro`,
`epico`); un valor desconocido no pinta nada raro. En root-lab, el sorteo
respeta 70 / 25 / 5 en veinte mil tiradas.

**Que la cara dormida no delate la piel.** Antes del cofre la maceta duerme
en gris; si usara los colores de una piel, la sorpresa se arruinaría. Se
verifica que ningún pixel tenga el color de fondo de ninguna piel.

**Que el despertar tenga su segundo intento.** Los ojos se abren, se vuelven a
cerrar y recién después se abren del todo. El test exige ese tramo de subida.

**Que las etapas se vean distintas.** Si dos etapas producen el mismo cuadro, el
crecimiento no existe para el usuario por más que el contador avance en NVS.

**Los centinelas del framebuffer.** El rig dibuja elipses y arcos con radios que
salen de una tabla editable a mano. Un radio de más escribe fuera del buffer, y
en el ESP32 eso no tira excepción: corrompe lo que haya al lado y aparece tres
días después como un bug imposible. Se barren los cinco Rooties con sus tres
pieles en los once ánimos con todos los adornos, contra un buffer rodeado de guardas.

**El historial sobrevive un corte de luz.** Un byte corrupto o un archivo
cortado a la mitad se descartan enteros en vez de devolver lecturas falsas.

**La monotonía de la batería.** Se recorre la curva de 2,8 a 4,3 V verificando
que nunca baje. Sin eso, el ruido del ADC puede hacer que la batería "suba".

**La semana simulada.** Siete días de muestreo con una planta que se seca y se
riega, verificando que el muestreo adaptativo ahorre al menos la mitad de las
transmisiones — pero también que no ahorre de más, que sería perder eventos.

**Que un aparato caído no acumule días sanos.** Es lo que impide que
desenchufarlo haga crecer el vínculo gratis.

**Que las carcasas se puedan imprimir.** En root-lab,
`test/rooti3d.test.mjs` recorre los triángulos de las cinco figuras —las
mismas que salen en STL y que dibuja la app— y mide el voladizo de cada uno
(45° como máximo), sin contar los que quedan escondidos dentro de otra pieza.
Además: que ninguna pieza empiece en el aire, que las mallas estén del derecho
(volumen con signo positivo), la base plana y ancha, el centro de masa abajo,
y que la 18650 parada y el módulo del TFT entren de verdad, punto por punto,
contra la geometría.

**Que el mismo síntoma con distinta tierra dé causas distintas.** Hojas
amarillas con la tierra encharcada, seca o en rango son tres problemas
diferentes. Si las tres dieran lo mismo, la telemetría no estaría aportando
nada al diagnóstico y la foto sería decoración.

**Que marchita con la tierra mojada no se lea como sed.** Es el error más caro
que puede cometer alguien que cuida plantas: ve la planta caída, la riega, y le
termina de pudrir las raíces. El test exige que la acción diga "no riegues".

**Que la XP no se pueda acelerar.** Un mes con tres plantas no puede dar el
nivel máximo. Si se pudiera, el número mediría entusiasmo en vez de jardinería.

**Que una tarea marcada como hecha vuelva si no se resolvió.** El tilde esconde
la tarea dos horas; si la planta sigue seca después, reaparece.

## Regresión visual

`test/golden.h` guarda un FNV-1a del framebuffer de **cada Rooti con cada piel
en cada ánimo**: 132 hashes. Si un cambio altera cualquier pixel, la suite
`cara` lo marca.

Son 132 y no 11 a propósito. El rig es procedural y cada familia de ojos toma
un camino distinto, así que un cambio puede romper la medialuna del Musgo sin
tocar los ojos redondos del Brote, y una piel con aura sin tocar la común.
La tabla está ordenada por modelo, y eso hace que el diff diga qué pasó: once
filas seguidas son "se movió un modelo", una columna es "se movió un ánimo en
todos". Son dos revisiones distintas.

Cuando el cambio es intencional:

```bash
make golden      # regenera firmware/test/golden.h
```

El archivo se versiona en vez de ignorarse porque **el diff del archivo
generado es la revisión del cambio visual**.

`make verify` —y CI— regeneran los hashes y fallan si el árbol queda sucio.

## Kip: que sea fluido y que sea su lámina

Kip no pasa por el rig: se dibuja con la lámina de Rocío (`art/kip.c`), y
cada ánimo es una pista de claves que se interpola. La regresión visual fija
cómo se ve un instante; la suite `kip` (`test/test_kip.c`) fija cómo se
mueve, sin mirar un pixel:

- **Ningún ciclo salta.** Cada ánimo se recorre dos vueltas de a 10 ms y
  ninguna parte de la cara (ojos, cejas, boca, mirada) puede moverse más de
  un tope entre dos muestras. Los topes son generosos —un parpadeo es rápido
  y una mirada salta—: lo que buscan es un corte, una clave que no empalma
  con la siguiente o un ciclo que no vuelve a donde empezó.
- **Ninguna transición salta.** De cada ánimo a cada otro (121 pares), de a
  un por ciento.
- **La boca cambia de forma sólo cerrada**, en los ciclos y en las
  transiciones: una boca teal no se vuelve una con dientes a mitad de camino.
- **Las cejas saltan**: al subir se pasan de largo y vuelven.
- **La lámina está en la pista.** Contento guiña y sonríe en teal y con
  dientes; ahogándose, el agua le llega a los ojos todo el ciclo, boquea y
  mira el agua; con calor saca la lengua, jadea, sopla, tira el beso y hace
  la mueca ondulada; a oscuras busca la luz arriba y a los costados; con el
  aire seco mira de reojo con los ojos en rendija. Si alguien cambia una
  pista y se le pierde un dibujo de ella, esto lo dice.
- Cada efecto (el agua, las grietas, el sudor, la nieve...) es de su ánimo y
  de ninguno más, y con una piel ajena —la gris de la cara dormida— los
  colores de Kip pasan a gris.

## Qué NO cubre

Conviene tenerlo escrito, porque la cobertura alta invita a confiar de más:

- **Nada toca hardware real.** Las conversiones de los sensores se prueban con
  los bytes de las hojas de datos, pero el I2C, el ADC, el SPI y el wifi de
  `esp32/` sólo se compilan: se prueban en la Fase 1 del [roadmap](roadmap.md).
- **El consumo es un modelo, no una medición.** Las cifras de autonomía salen de
  correr las funciones de `nodo/power.c` con parámetros que todavía no se
  verificaron con un multímetro. El reposo real del C3 y la corriente de cada
  retroiluminación son los dos números que pueden cambiar todo.
- **La regresión visual compara hashes, no aspecto.** Detecta que algo cambió;
  no dice si quedó mejor o peor. Para eso están `make sheet`, `make etapas`,
  `make despertar` y `make pantallas`, que hay que mirar con los ojos.
- **Nada verifica que una cara sea linda, ni que haga juego con su carcasa.**
  Eso se mira en la lámina y se ajusta en `core/persona.c`.
- **La interfaz de la app** se prueba en root-lab.
- **Las carcasas no están modeladas todavía.** `docs/carcasas.md` tiene el
  envolvente y las tolerancias, pero nada verifica que una pieza impresa
  encastre: eso se prueba imprimiendo.
- **El portal cautivo** se compila, pero que la página abra sola en cada
  teléfono sólo se ve con teléfonos reales.

## Cómo agregar una suite

1. Un archivo `test/test_<nombre>.c` con una función `suite_<nombre>(void)`.
2. Declararla en `test/rk_test.h` y llamarla en `test/main.c`.
3. Agregarla a `TESTSRC` en `firmware/Makefile`.

Los `CHECK_*` están en `test/rk_test.h`. La etiqueta de cada uno se lee en la
salida cuando falla, así que conviene que diga qué se rompió y no qué se
comparó: `"la cara dormida no usa la piel de ningún personaje"` sirve;
`"hash != 0"` no.

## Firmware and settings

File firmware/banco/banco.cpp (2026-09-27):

/* banco.cpp — el firmware de banco del prototipo NodeMCU de Rocío.
 *
 * PARA QUÉ ES
 *
 * Para probar el hardware recién soldado sin la ceremonia del producto: no
 * hay QR, ni vínculo, ni nube, ni cofre. Arranca directo en la cara de Kip, y
 * esa cara reacciona a los sensores DE VERDAD con el mismo motor de ánimo que
 * el producto (core/mood.c):
 *
 *   - el capacitivo al aire da sed; en un vaso de agua, ahogo
 *   - tapar la LDR da oscuridad, y a los 8 segundos se duerme (de noche)
 *   - un dedo sobre el HTU21D sube la temperatura: calor
 *
 * Las lecturas van en las franjas que le sobran al panel de 2,2" arriba y
 * abajo de la cara, y cada segundo por el puerto serie, con los valores
 * crudos al lado para ver si un sensor está vivo.
 *
 * EL BOTÓN BOOT
 *
 *   corto   pasa de modo: AUTO (el ánimo de los sensores) y después los
 *           once ánimos de Kip uno por uno, para ver todas las animaciones
 *   largo   cambia la piel: común, rara, épica
 *
 * Por el monitor serie (115200) se maneja todo con una letra: "?" muestra la
 * ayuda.
 *
 * LO QUE NO ES
 *
 * No es el firmware del producto: esta placa no tiene toque, ni batería, ni
 * BH1750, y la luz es una LDR (nodo/sensores.h, rk_ldr_lux), que da lux
 * aproximados. La noche llega en 8 segundos y no en dos horas porque se mide
 * una vez por segundo y no cada quince minutos.
 */
#include <Arduino.h>
#include <Wire.h>
#include <Preferences.h>
#include <esp_heap_caps.h>
#include "../esp32/placa.h"
#include "../esp32/pantalla.h"
extern "C" {
#include "../art/face.h"
#include "../core/mood.h"
#include "../core/persona.h"
#include "../core/species.h"
#include "../gfx/font.h"
#include "../nodo/sensores.h"
#include "../nodo/soil.h"
#include "../ui/cara.h"
}

#define BANCO_VERSION   "banco-1"
#define MEDIR_MS        1000u      /* una lectura completa por segundo       */
#define CUADRO_MS       33u        /* ~30 cuadros por segundo, si le da      */
#define BOTON_LARGO_MS  700u
#define VCC_MV          3300u      /* los módulos van a la línea de 3,3 V    */
#define N_MUESTRAS      9          /* mediana de los analógicos              */
/* El ADC del ESP32 a 11 dB no baja de ~140 mV: con mucha luz la AO de la
 * LDR cae a unos 30 mV y el ADC se queda en el piso. Ahí no se sabe cuánta
 * luz hay, sólo que es mucha: se toma como sol. */
#define LUZ_PISO_RAW    16u
#define LUZ_SATURADA    30000u

/* Los colores de las franjas: las del banco, no las de la cara. */
#define COL_FRANJA   RK_RGB(16, 18, 20)
#define COL_ROTULO   RK_RGB(130, 136, 142)
#define COL_VALOR    RK_RGB(240, 180, 80)
#define COL_FALLA    RK_RGB(255, 90, 80)

/* Los umbrales con los que arranca: los de una planta de interior que
 * perdona, con la luz corrida hacia abajo, porque la LDR mide aproximado y
 * una mesa de trabajo tiene 200 a 500 lux. Así, en la mesa y con el
 * capacitivo en tierra húmeda, Kip está contento, y cada sensor lo saca de
 * ahí por su lado: el capacitivo al aire (sed) o en agua (ahogo), la LDR
 * tapada (oscuro, y a los 8 s dormido) o con una linterna encima (sol), un
 * dedo sobre el HTU21D (calor). Con "e" se pasa a las especies de verdad. */
static const rk_species_t ESPECIE_BANCO = {
    "banco", "Banco de pruebas", 20, 60, 150, 300, 30, 100, 20000, 0
};

/* ----------------------------------------------------------- el estado -- */
typedef enum { MODO_AUTO = -1 } modo_t;   /* 0..10: un ánimo de DEMO */

/* El recorrido del botón: primero los cinco de las láminas de Rocío, en el
 * orden en que llegaron, y después los que salen de su vocabulario. */
static const rk_mood_t DEMO[] = {
    RK_MOOD_HAPPY, RK_MOOD_DROWNING, RK_MOOD_HOT, RK_MOOD_DARK, RK_MOOD_PARCHED_AIR,
    RK_MOOD_THIRSTY, RK_MOOD_COLD, RK_MOOD_SCORCHED, RK_MOOD_SLEEPING,
    RK_MOOD_UNKNOWN, RK_MOOD_OFFLINE,
};
#define N_DEMO ((int)(sizeof DEMO / sizeof DEMO[0]))

static const rk_persona_t *g_kip;
static const rk_species_t *g_especie;
static int                 g_especie_idx;
static uint8_t             g_rareza;
static int                 g_modo = MODO_AUTO;
static rk_cara_anim_t      g_anim;
static rk_mood_state_t     g_mst;
static rk_verdict_t        g_veredicto;
static rk_soil_cal_t       g_cal;
static Preferences         g_nvs;

/* Las lecturas: los analógicos se muestrean de a uno por cuadro (así la
 * animación no se frena), y la mediana de los últimos nueve es la lectura. */
static uint16_t g_suelo[N_MUESTRAS], g_luz_mv[N_MUESTRAS], g_luz_raw[N_MUESTRAS];
static bool     g_luz_saturada;
static int      g_i_muestra;
static bool     g_luz_do;
static bool     g_htu_ok, g_htu_presente;
static uint8_t  g_sht[6];
static rk_telemetry_t g_tel;
static uint16_t g_suelo_raw, g_luz_ao_mv;

/* El HTU21D mide temperatura y humedad en dos conversiones. Se esperan los
 * tiempos del SHT21, el más lento de la familia —85 ms a 14 bits y 29 a 12—,
 * así el mismo código sirve para los tres. Es una máquina de estados, para
 * no frenar los cuadros de la cara mientras el sensor convierte. */
typedef enum { HTU_QUIETO, HTU_TEMPERATURA, HTU_HUMEDAD } htu_paso_t;
static htu_paso_t g_htu = HTU_QUIETO;
static uint32_t   g_htu_t0;
static bool       g_htu_t_ok;

static rk_color_t *g_franja;      /* una franja de texto, ancho x alto */
static int         g_franja_alto;

/* Medidas de rendimiento, para el serie. */
static uint32_t g_cuadros, g_render_us, g_t_medida_fps;

/* ------------------------------------------------------------- nombres -- */
static const char *animo_corto(rk_mood_t m)
{
    switch (m) {
    case RK_MOOD_HAPPY:       return "CONTENTO";
    case RK_MOOD_THIRSTY:     return "SED";
    case RK_MOOD_DROWNING:    return "SE AHOGA";
    case RK_MOOD_COLD:        return "FRIO";
    case RK_MOOD_HOT:         return "CALOR";
    case RK_MOOD_SCORCHED:    return "SOL DIRECTO";
    case RK_MOOD_DARK:        return "OSCURO";
    case RK_MOOD_PARCHED_AIR: return "AIRE SECO";
    case RK_MOOD_SLEEPING:    return "DORMIDO";
    case RK_MOOD_OFFLINE:     return "DESCONECTADO";
    default:                  return "SIN DATOS";
    }
}

static rk_mood_t animo_en_pantalla(void)
{
    return g_modo == MODO_AUTO ? g_veredicto.mood : DEMO[g_modo];
}

/* ---------------------------------------------------------------- I2C --- */
static bool i2c_escribir(uint8_t dir, uint8_t b)
{
    Wire.beginTransmission(dir);
    Wire.write(b);
    return Wire.endTransmission() == 0;
}

static bool i2c_leer(uint8_t dir, uint8_t *b, size_t n)
{
    if (Wire.requestFrom((int)dir, (int)n) != (int)n) {
        return false;
    }
    for (size_t i = 0; i < n; i++) {
        b[i] = (uint8_t)Wire.read();
    }
    return true;
}

static void i2c_escanear(void)
{
    int encontrados = 0;

    Serial.print("  I2C (SDA ");
    Serial.print(RK_PIN_SDA);
    Serial.print(", SCL ");
    Serial.print(RK_PIN_SCL);
    Serial.print("):");
    for (uint8_t a = 1; a < 127; a++) {
        Wire.beginTransmission(a);
        if (Wire.endTransmission() == 0) {
            Serial.printf(" 0x%02X", a);
            if (a == RK_I2C_SHT21) {
                Serial.print(" (HTU21D)");
            }
            encontrados++;
        }
    }
    if (encontrados == 0) {
        Serial.print(" nada. Mirar SDA/SCL y los 3,3 V del HTU21D");
    }
    Serial.println();
    Wire.beginTransmission(RK_I2C_SHT21);
    g_htu_presente = Wire.endTransmission() == 0;
}

/* Un paso de la máquina del HTU21D; se llama en cada cuadro. */
static void htu_paso(void)
{
    uint32_t ahora = millis();

    switch (g_htu) {
    case HTU_QUIETO:
        break;
    case HTU_TEMPERATURA:
        if (ahora - g_htu_t0 >= 90u) {
            g_htu_t_ok = i2c_leer(RK_I2C_SHT21, g_sht, 3) && i2c_escribir(RK_I2C_SHT21, 0xF5);
            g_htu_t0 = ahora;
            g_htu = g_htu_t_ok ? HTU_HUMEDAD : HTU_QUIETO;
            if (!g_htu_t_ok) {
                g_htu_ok = false;
            }
        }
        break;
    case HTU_HUMEDAD:
        if (ahora - g_htu_t0 >= 35u) {
            g_htu_ok = i2c_leer(RK_I2C_SHT21, &g_sht[3], 3);
            g_htu = HTU_QUIETO;
        }
        break;
    }
}

static void htu_disparar(void)
{
    /* "No hold": el bus queda libre mientras el sensor convierte. */
    if (g_htu == HTU_QUIETO) {
        if (i2c_escribir(RK_I2C_SHT21, 0xF3)) {
            g_htu = HTU_TEMPERATURA;
            g_htu_t0 = millis();
        } else {
            g_htu_ok = false;
        }
    }
}

/* ---------------------------------------------------------- analógicos -- */
static void muestrear(void)
{
    g_suelo[g_i_muestra] = (uint16_t)analogRead(RK_PIN_SUELO_ADC);
    g_luz_mv[g_i_muestra] = (uint16_t)analogReadMilliVolts(RK_PIN_LUZ_ADC);
    g_luz_raw[g_i_muestra] = (uint16_t)analogRead(RK_PIN_LUZ_ADC);
    g_i_muestra = (g_i_muestra + 1) % N_MUESTRAS;
    g_luz_do = digitalRead(RK_PIN_LUZ_DIG) == HIGH;
}

/* ------------------------------------------------------------- medir ----- */
/* Arma la telemetría con la misma conversión que el producto
 * (rk_sensores_telemetria) y le suma la luz de la LDR; después, el ánimo. */
static void medir(void)
{
    rk_crudos_t c;

    memset(&c, 0, sizeof c);
    memcpy(c.suelo, g_suelo, sizeof c.suelo);
    c.n_suelo = N_MUESTRAS;
    if (g_htu_ok) {
        memcpy(c.sht, g_sht, sizeof c.sht);
        c.sht_leido = true;
    }
    rk_sensores_telemetria(&c, &g_cal, &g_tel);

    g_suelo_raw = g_tel.suelo_raw;
    g_luz_ao_mv = rk_soil_median(g_luz_mv, N_MUESTRAS);
    g_luz_saturada = rk_soil_median(g_luz_raw, N_MUESTRAS) < LUZ_PISO_RAW;
    g_tel.lux = g_luz_saturada ? LUZ_SATURADA : rk_ldr_lux(g_luz_ao_mv, VCC_MV);
    g_tel.fallas &= (uint8_t)~RK_FALLA_LUZ;
    g_tel.usb = true;                  /* el banco va enchufado            */
    g_tel.batt_mv = 0u;

    g_veredicto = rk_mood_eval(&g_mst, g_especie, &g_tel);
}

/* "23.4" o "-1.5": las décimas de grado, con el signo bien puesto. */
static void grados(char *s, size_t n, int16_t dc)
{
    int v = dc < 0 ? -(int)dc : (int)dc;
    snprintf(s, n, "%s%d.%d", dc < 0 ? "-" : "", v / 10, v % 10);
}

/* ------------------------------------------------------------- franjas --- */
static void franja_linea(rk_fb_t *fb, int y, const char *rotulo, const char *valor,
                         rk_color_t col_valor)
{
    int x = 6;
    x += rk_text(fb, x, y, rotulo, COL_ROTULO, 2);
    rk_text(fb, x + 10, y, valor, col_valor, 2);
}

/* Las dos franjas: arriba el suelo y la luz, abajo el aire y el ánimo. */
static void dibujar_franjas(void)
{
    rk_fb_t fb;
    char a[40], b[40];
    const int alto = g_franja_alto;
    const int l1 = (alto - 30) / 2 < 2 ? 2 : (alto - 30) / 2, l2 = l1 + 16;

    if (g_franja == NULL || alto < 30) {
        return;
    }
    rk_fb_init(&fb, g_franja, RK_TFT_W, alto);

    /* Arriba: suelo y luz. */
    rk_fb_clear(&fb, COL_FRANJA);
    if (g_tel.fallas & RK_FALLA_SUELO) {
        snprintf(a, sizeof a, "?? (%u)", g_suelo_raw);
        franja_linea(&fb, l1, "SUELO", a, COL_FALLA);
    } else {
        snprintf(a, sizeof a, "%u%% (%u)", g_tel.soil_pct, g_suelo_raw);
        franja_linea(&fb, l1, "SUELO", a, COL_VALOR);
    }
    if (g_luz_saturada) {
        snprintf(b, sizeof b, "MUCHA DO:%d", g_luz_do ? 1 : 0);
    } else {
        snprintf(b, sizeof b, "%lu LX DO:%d", (unsigned long)g_tel.lux, g_luz_do ? 1 : 0);
    }
    franja_linea(&fb, l2, "LUZ", b, COL_VALOR);
    pantalla_rect(0, 0, RK_TFT_W, alto, g_franja);

    /* Abajo: el aire y lo que la cara está mostrando. */
    rk_fb_clear(&fb, COL_FRANJA);
    if (g_tel.fallas & RK_FALLA_AIRE) {
        franja_linea(&fb, l1, "AIRE", g_htu_presente ? "NO MIDE" : "SIN HTU21D", COL_FALLA);
    } else {
        char t[12];
        grados(t, sizeof t, g_tel.temp_dc);
        snprintf(a, sizeof a, "%s~C %u%%", t, g_tel.rh_pct);
        franja_linea(&fb, l1, "AIRE", a, COL_VALOR);
    }
    if (g_modo == MODO_AUTO) {
        franja_linea(&fb, l2, "AUTO", animo_corto(g_veredicto.mood), COL_VALOR);
    } else {
        snprintf(a, sizeof a, "%d/%d", g_modo + 1, N_DEMO);
        snprintf(b, sizeof b, "%s", animo_corto(DEMO[g_modo]));
        franja_linea(&fb, l2, a, b, rk_mix(COL_VALOR, RK_RGB(255, 255, 255), 90));
    }
    pantalla_rect(0, RK_TFT_H - alto, RK_TFT_W, alto, g_franja);
}

/* ------------------------------------------------------------ el serie --- */
static void ayuda(void)
{
    Serial.println();
    Serial.println("  BOOT corto: siguiente modo (AUTO y los 11 animos). BOOT largo: piel.");
    Serial.println("  a  AUTO: la cara sigue a los sensores");
    Serial.println("  n  siguiente animo;  1-9, 0 y x  uno en particular:");
    Serial.println("     1 contento  2 agua  3 calor  4 oscuro  5 aire seco  6 sed");
    Serial.println("     7 frio  8 sol  9 dormido  0 sin datos  x desconectado");
    Serial.println("  p  siguiente piel (comun, rara, epica)");
    Serial.println("  e  siguiente especie (cambia los umbrales del animo)");
    Serial.println("  s  calibrar suelo SECO: el sensor al aire, limpio");
    Serial.println("  m  calibrar suelo MOJADO: el sensor en un vaso de agua, hasta la raya");
    Serial.println("  r  volver a la calibracion de fabrica");
    Serial.println("  i  escanear el I2C;  ?  esta ayuda");
    Serial.println();
}

static void informar(void)
{
    Serial.printf("suelo %4u (%s%3u%%)  luz AO %4u mV ~%5lu lx%s DO %d  ",
                  g_suelo_raw, (g_tel.fallas & RK_FALLA_SUELO) ? "??" : "",
                  g_tel.soil_pct, g_luz_ao_mv, (unsigned long)g_tel.lux,
                  g_luz_saturada ? " (saturada)" : "", g_luz_do ? 1 : 0);
    if (g_tel.fallas & RK_FALLA_AIRE) {
        Serial.print("aire: sin lectura  ");
    } else {
        char t[12];
        grados(t, sizeof t, g_tel.temp_dc);
        Serial.printf("aire %s C %u%%  ", t, g_tel.rh_pct);
    }
    Serial.printf("| %s: %s", g_especie->nombre, rk_mood_name(g_veredicto.mood));
    Serial.printf(" (%s)", g_veredicto.reason);
    if (g_modo != MODO_AUTO) {
        Serial.printf("  | pantalla: %s", rk_mood_name(DEMO[g_modo]));
    }
    Serial.println();
}

static void guardar_cal(void)
{
    g_nvs.putUShort("seco", g_cal.dry_raw);
    g_nvs.putUShort("mojado", g_cal.wet_raw);
}

static void cambiar_modo(int modo)
{
    g_modo = modo;
    Serial.printf("  modo: %s\n", modo == MODO_AUTO ? "AUTO (los sensores)"
                                                    : rk_mood_name(DEMO[modo]));
    dibujar_franjas();
}

static void cambiar_piel(void)
{
    g_rareza = (uint8_t)((g_rareza + 1u) % RK_RAREZA_COUNT);
    Serial.printf("  piel: %s (%s)\n", rk_persona_piel(g_kip, g_rareza)->nombre,
                  rk_rareza_nombre((rk_rareza_t)g_rareza));
}

static void comando(int c)
{
    switch (c) {
    case 'a': case 'A':
        cambiar_modo(MODO_AUTO);
        break;
    case 'n': case 'N':
        cambiar_modo(g_modo + 1 >= N_DEMO ? MODO_AUTO : g_modo + 1);
        break;
    case 'x': case 'X':
        cambiar_modo(10);
        break;
    case 'p': case 'P':
        cambiar_piel();
        break;
    case 'e': case 'E':
        /* -1 es la del banco; después, la tabla de core/species.c. */
        g_especie_idx = g_especie_idx + 1 >= rk_species_count ? -1 : g_especie_idx + 1;
        g_especie = g_especie_idx < 0 ? &ESPECIE_BANCO : &rk_species_table[g_especie_idx];
        rk_mood_state_init(&g_mst);
        Serial.printf("  especie: %s (suelo %u-%u%%, %d-%d C, HR >= %u%%, luz %lu-%lu lx)\n",
                      g_especie->nombre, g_especie->soil_min, g_especie->soil_max,
                      g_especie->temp_min_dc / 10, g_especie->temp_max_dc / 10,
                      g_especie->rh_min, (unsigned long)g_especie->lux_min,
                      (unsigned long)g_especie->lux_max);
        break;
    case 's': case 'S':
        g_cal.dry_raw = g_suelo_raw;
        Serial.printf("  suelo SECO = %u%s\n", g_cal.dry_raw,
                      rk_soil_cal_valid(&g_cal) ? "" : "  (falta MOJADO, o quedaron muy cerca)");
        guardar_cal();
        break;
    case 'm': case 'M':
        g_cal.wet_raw = g_suelo_raw;
        Serial.printf("  suelo MOJADO = %u%s\n", g_cal.wet_raw,
                      rk_soil_cal_valid(&g_cal) ? "" : "  (falta SECO, o quedaron muy cerca)");
        guardar_cal();
        break;
    case 'r': case 'R':
        g_cal = RK_SOIL_CAL_DEFAULT;
        guardar_cal();
        Serial.printf("  suelo: calibracion de fabrica (%u seco, %u mojado)\n",
                      g_cal.dry_raw, g_cal.wet_raw);
        break;
    case 'i': case 'I':
        i2c_escanear();
        break;
    case '?': case 'h': case 'H':
        ayuda();
        break;
    default:
        if (c >= '1' && c <= '9') {
            cambiar_modo(c - '1');
        } else if (c == '0') {
            cambiar_modo(9);
        }
        break;
    }
}

/* ------------------------------------------------------------- el botón -- */
static void boton(void)
{
    static bool antes = false;
    static uint32_t t_apretado;
    static bool largo_hecho;
    bool ahora = digitalRead(RK_PIN_BOTON) == LOW;
    uint32_t t = millis();

    if (ahora && !antes) {
        t_apretado = t;
        largo_hecho = false;
    } else if (ahora && !largo_hecho && t - t_apretado >= BOTON_LARGO_MS) {
        largo_hecho = true;
        cambiar_piel();
    } else if (!ahora && antes && !largo_hecho && t - t_apretado >= 30u) {
        cambiar_modo(g_modo + 1 >= N_DEMO ? MODO_AUTO : g_modo + 1);
    }
    antes = ahora;
}

/* ------------------------------------------------------ setup y loop ---- */
void setup(void)
{
    Serial.begin(115200);
    delay(300);
    Serial.println();
    Serial.println("ROOTKIT / firmware de banco " BANCO_VERSION " / " RK_PLACA_NOMBRE
                   " + " RK_PANTALLA_NOMBRE);

    pinMode(RK_PIN_BOTON, INPUT_PULLUP);
    pinMode(RK_PIN_LUZ_DIG, INPUT);
    analogReadResolution(12);
    analogSetPinAttenuation(RK_PIN_SUELO_ADC, ADC_11db);
    analogSetPinAttenuation(RK_PIN_LUZ_ADC, ADC_11db);
    Wire.begin(RK_PIN_SDA, RK_PIN_SCL, 100000);
    /* El HTU21D: reset por software, y a los 15 ms está listo. */
    i2c_escribir(RK_I2C_SHT21, 0xFE);
    delay(20);
    i2c_escanear();

    g_nvs.begin("banco", false);
    g_cal.dry_raw = g_nvs.getUShort("seco", RK_SOIL_CAL_DEFAULT.dry_raw);
    g_cal.wet_raw = g_nvs.getUShort("mojado", RK_SOIL_CAL_DEFAULT.wet_raw);
    Serial.printf("  suelo calibrado: %u seco, %u mojado%s\n", g_cal.dry_raw, g_cal.wet_raw,
                  rk_soil_cal_valid(&g_cal) ? "" : " (invalida: se usa la de fabrica)");
    if (!rk_soil_cal_valid(&g_cal)) {
        g_cal = RK_SOIL_CAL_DEFAULT;
    }

    g_kip = rk_persona_find("kip");
    g_especie_idx = -1;
    g_especie = &ESPECIE_BANCO;
    rk_mood_state_init(&g_mst);

    Serial.printf("  memoria: %u libres, bloque mas grande %u\n",
                  (unsigned)ESP.getFreeHeap(),
                  (unsigned)heap_caps_get_largest_free_block(MALLOC_CAP_8BIT));
    if (!pantalla_iniciar(100)) {
        Serial.println("  PANTALLA: no hubo memoria para el cuadro. Nada que dibujar.");
    } else {
        Serial.printf("  pantalla: cara de %dx%d en (%d, %d)\n", pantalla_lado(),
                      pantalla_lado(), pantalla_x0(), pantalla_y0());
        g_franja_alto = pantalla_y0();
        if (g_franja_alto >= 30) {
            g_franja = (rk_color_t *)malloc((size_t)RK_TFT_W * (size_t)g_franja_alto
                                            * sizeof(rk_color_t));
            if (g_franja != NULL) {
                pantalla_reservar_franjas(true);
            }
        }
    }

    for (int i = 0; i < N_MUESTRAS; i++) {
        muestrear();
    }
    htu_disparar();
    delay(100);
    htu_paso();
    delay(50);
    htu_paso();
    medir();
    rk_cara_anim_iniciar(&g_anim, animo_en_pantalla(), millis());
    ayuda();
    informar();
    dibujar_franjas();
    g_t_medida_fps = millis();
}

void loop(void)
{
    static uint32_t t_medir, t_cuadro;
    uint32_t ahora = millis();

    while (Serial.available() > 0) {
        comando(Serial.read());
    }
    boton();
    muestrear();
    htu_paso();

    if (ahora - t_medir >= MEDIR_MS) {
        t_medir = ahora;
        medir();
        htu_disparar();                  /* la próxima lectura del aire */
        informar();
        dibujar_franjas();
    }

    if (ahora - t_cuadro >= CUADRO_MS) {
        rk_fb_t *fb = pantalla_fb();
        uint32_t t0 = micros();
        t_cuadro = ahora;
        if (fb->px != NULL) {
            rk_cara_anim_animo(&g_anim, animo_en_pantalla(), ahora);
            rk_cara_anim_draw(fb, g_kip, g_rareza, &g_anim, g_veredicto.severity, 0u, 0u,
                              ahora);
            g_render_us += micros() - t0;
            pantalla_presentar(fb->px[0]);
            g_cuadros++;
        }
    }

    if (ahora - g_t_medida_fps >= 10000u && g_cuadros > 0u) {
        Serial.printf("  %lu cuadros/s, %lu ms por cara, %u de memoria libre\n",
                      (unsigned long)(g_cuadros * 1000u / (ahora - g_t_medida_fps)),
                      (unsigned long)(g_render_us / 1000u / g_cuadros),
                      (unsigned)ESP.getFreeHeap());
        g_cuadros = 0;
        g_render_us = 0;
        g_t_medida_fps = ahora;
    }
}

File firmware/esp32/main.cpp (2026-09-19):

/* main.cpp — el ROOTKIT: une el núcleo portable con el hardware.
 *
 * Todo lo que decide (qué pantalla mostrar, qué cara poner, cuándo hablar
 * con la nube, qué hacer con la respuesta) está en el núcleo C, probado en el
 * escritorio. Este archivo sólo traduce: lee pines y bytes, se los pasa al
 * núcleo, y hace lo que el núcleo pide.
 *
 * El bucle no bloquea nunca. Cada vuelta:
 *
 *   botón  ->  fábrica  ->  portal  ->  wifi  ->  medir  ->  nube  ->
 *   actualización  ->  enlace  ->  guardar  ->  energía  ->  dibujar
 *
 * Ver docs/firmware.md para el mapa completo y cómo compilar y flashear.
 */
#include <Arduino.h>
#include <esp_mac.h>

#include "placa.h"
#include "pantalla.h"
#include "sensores_hw.h"
#include "almacen.h"
#include "portal.h"
#include "red.h"
#include "energia.h"
#include "ota.h"
#include "fabrica.h"

extern "C" {
#include "../core/codigo.h"
#include "../core/enlace.h"
#include "../core/mood.h"
#include "../core/node.h"
#include "../core/persona.h"
#include "../art/face.h"
#include "../ui/cara.h"
#include "../nodo/soil.h"
#include "../ui/qr.h"
#include "../ui/despertar.h"
#include "../nodo/sampler.h"
#include "../nodo/power.h"
#include "../net/nube.h"
}

#ifndef RK_FW_VERSION
#define RK_FW_VERSION "0.6.1"
#endif
#ifndef RK_NUBE_URL
#define RK_NUBE_URL "https://ifbotech.com/rootkit"
#endif
/* A dónde lleva el QR. Normalmente es la misma nube; en desarrollo puede ser
 * un túnel HTTPS para que el teléfono pueda instalar la app y recibir
 * notificaciones mientras la placa habla con la PC por la red local. */
#ifndef RK_APP_URL
#define RK_APP_URL ""
#endif

/* Cuánto aguanta la pantalla prendida sin que la toquen, a batería. */
#define PANTALLA_OCIOSA_MS     20000u
/* Mantener apretado para borrar vínculo y wifi. */
#define BOTON_LARGO_MS         10000u
/* A partir de acá los ojos empiezan a cerrarse: el aviso sin palabras de
 * que, si seguís apretando, la maceta se olvida de todo. */
#define BOTON_AVISO_MS          2000u
#define WIFI_REINTENTO_MS      10000u
#define LECTURAS_POR_PEDIDO       20u
/* Con la app calibrando el sensor: medir y contar cada tanto, sin dormir. */
#define CALIBRANDO_CADA_MS      5000u

static rk_almacen_t   A;
static rk_enlace_t    E;
static rk_historial_t H;
static rk_sampler_t   S;
static rk_node_t      N;
static rk_qr_t        Q;
static rk_nube_resp_t R;

static char g_id[RK_ID_LEN + 1];
static char g_token[RK_TOKEN_LEN + 1];
static char g_codigo[RK_CODIGO_LEN + 1];
static char g_ssid_ap[20];
static char g_url_sync[140];
static uint32_t g_epoca_qr = 0xFFFFFFFFu;

static char g_cuerpo[4096];
static char g_respuesta[2048];
static uint16_t g_incluidas;

static uint32_t g_t_medir;
static uint32_t g_t_consulta;
static uint32_t g_t_actividad;
static uint32_t g_t_cuadro;
static uint32_t g_t_boton;
static uint32_t g_t_wifi_ok;
static uint32_t g_t_wifi_reintento;
static bool     g_largo_disparado;
static bool     g_transmitir = true;
static uint32_t g_intervalo_nube_s = 900u;
static rk_wifi_t g_wifi_prev = RK_WIFI_APAGADO;
static rk_enlace_estado_t g_estado_prev = RK_ENL_COUNT;
static bool     g_calibrando;
/* La versión recién instalada todavía no habló con la nube. */
static bool     g_ota_verificando;
static const char *g_ota_estado;     /* lo que se le cuenta a la nube */

RTC_DATA_ATTR static uint32_t g_dia_desde_s;
RTC_DATA_ATTR static bool     g_dia_urgente;
/* El detector de riego mira varias lecturas seguidas: vive en la memoria
 * RTC para sobrevivir al deep sleep entre una y otra. */
RTC_DATA_ATTR static rk_riego_t g_riego;
static rk_cara_anim_t g_anim;

/* --------------------------------------------------------- identidad ---- */
static void refrescar_codigo(void)
{
    char url_qr[128];
    bool ok;

    if (g_epoca_qr == E.nvs.epoca) {
        return;
    }
    g_epoca_qr = E.nvs.epoca;
    rk_codigo_vinculo(A.secreto, E.nvs.epoca, g_codigo);
    rk_codigo_ssid(g_codigo, g_ssid_ap, sizeof g_ssid_ap);
    ok = rk_codigo_url(A.app[0] != 0 ? A.app : A.nube, g_codigo, url_qr, sizeof url_qr);
    rk_qr_preparar(&Q, ok ? url_qr : NULL, g_codigo);
    snprintf(g_url_sync, sizeof g_url_sync, "%s%s", A.nube, RK_NUBE_RUTA_SYNC);
    Serial.printf("[enlace] codigo %s  red %s  qr %s\n", g_codigo, g_ssid_ap, ok ? url_qr : "(sin QR)");
}

static void aplicar_persona(void)
{
    const rk_persona_t *p = rk_persona_find(A.persona);
    N.persona = p != NULL ? p : rk_persona_at(0);
    N.rareza = A.rareza < RK_RAREZA_COUNT ? A.rareza : RK_RAREZA_COMUN;
}

static void aplicar_especie(void)
{
    N.sp = A.hay_especie ? rk_especie_ver(&A.especie) : NULL;
    rk_mood_state_init(&N.mst);
}

/* ------------------------------------------------------------- medir ---- */
static void medir(uint32_t ahora)
{
    rk_crudos_t crudos;
    uint32_t reloj = energia_reloj_s();

    sensores_leer(&crudos);
    rk_sensores_telemetria(&crudos, &A.cal, &N.tel);

    /* ¿El último riego empapó o se escurrió por los costados? */
    if (!(N.tel.fallas & RK_FALLA_SUELO)) {
        rk_riego_evento_t ev = rk_riego_paso(&g_riego, N.tel.soil_pct, reloj);
        if (ev == RK_RIEGO_ESCURRIO) {
            Serial.println("[riego] el agua se escurrio sin empapar");
        } else if (ev == RK_RIEGO_EMPAPO) {
            Serial.println("[riego] riego de verdad");
        }
    }
    if (rk_riego_escurriendo(&g_riego, reloj)) {
        N.tel.fallas |= RK_FALLA_ESCURRE;
    }

    if (N.sp != NULL) {
        N.verdict = rk_mood_eval(&N.mst, N.sp, &N.tel);
    } else {
        /* Sin especie todavía (la foto no se sacó): contento de conocerte. */
        N.verdict.mood = RK_MOOD_HAPPY;
        N.verdict.severity = RK_SEV_OK;
        N.verdict.reason = rk_mood_reason(RK_MOOD_HAPPY);
    }

    rk_registro_t reg = rk_registro_desde(&N.tel, reloj, (uint8_t)N.verdict.mood,
                                          (uint8_t)N.verdict.severity);
    rk_historial_agregar(&H, &reg);
    almacen_historial_guardar(&H);

    rk_sampler_decision_t d = rk_sampler_step(&S, &N.tel, reloj, N.sp);
    if (d.transmit) {
        g_transmitir = true;
    }
    g_t_medir = ahora + (uint32_t)d.sleep_s * 1000u;
    if (g_calibrando) {
        /* La app está mirando el número crudo en vivo. */
        g_t_medir = ahora + CALIBRANDO_CADA_MS;
        g_transmitir = true;
    }

    /* El día del vínculo: 24 h de reloj, sano si no hubo nada urgente. */
    if (N.verdict.severity == RK_SEV_URGENT) {
        g_dia_urgente = true;
    }
    if (E.estado == RK_ENL_ACTIVO && reloj - g_dia_desde_s >= 86400u) {
        rk_bond_dia(&A.vinculo, !g_dia_urgente);
        N.bond = A.vinculo;
        almacen_guardar_vinculo(&A);
        g_dia_desde_s = reloj;
        g_dia_urgente = false;
    }
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

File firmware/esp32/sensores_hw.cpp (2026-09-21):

#include "sensores_hw.h"
#include "placa.h"
#include <Wire.h>

/* ------------------------------------------------------------------ I2C -- */
static bool i2c_escribir(uint8_t dir, const uint8_t *b, size_t n)
{
    Wire.beginTransmission(dir);
    Wire.write(b, n);
    return Wire.endTransmission() == 0;
}

static bool i2c_leer(uint8_t dir, uint8_t *b, size_t n)
{
    if (Wire.requestFrom((int)dir, (int)n) != (int)n) {
        return false;
    }
    for (size_t i = 0; i < n; i++) {
        b[i] = (uint8_t)Wire.read();
    }
    return true;
}

/* --------------------------------------------------------------- 1-Wire -- */
/* Un DS18B20 solo en la línea: no hace falta la librería OneWire, y así se
 * evita su dependencia de registros por arquitectura. Los tiempos son los
 * de la nota de aplicación 126 de Maxim, dentro de una sección crítica
 * para que el wifi no los estire. */
static portMUX_TYPE g_mux = portMUX_INITIALIZER_UNLOCKED;

static void ow_bajo(void)  { digitalWrite(RK_PIN_UNOWIRE, LOW); }
static void ow_suelto(void) { digitalWrite(RK_PIN_UNOWIRE, HIGH); }

static bool ow_reset(void)
{
    bool presente;
    portENTER_CRITICAL(&g_mux);
    ow_bajo();
    delayMicroseconds(480);
    ow_suelto();
    delayMicroseconds(70);
    presente = digitalRead(RK_PIN_UNOWIRE) == LOW;
    portEXIT_CRITICAL(&g_mux);
    delayMicroseconds(410);
    return presente;
}

static void ow_bit_escribir(bool bit)
{
    portENTER_CRITICAL(&g_mux);
    ow_bajo();
    delayMicroseconds(bit ? 6 : 60);
    ow_suelto();
    portEXIT_CRITICAL(&g_mux);
    delayMicroseconds(bit ? 94 : 40);
}

static bool ow_bit_leer(void)
{
    bool bit;
    portENTER_CRITICAL(&g_mux);
    ow_bajo();
    delayMicroseconds(6);
    ow_suelto();
    delayMicroseconds(9);
    bit = digitalRead(RK_PIN_UNOWIRE) == HIGH;
    portEXIT_CRITICAL(&g_mux);
    delayMicroseconds(85);
    return bit;
}

static void ow_escribir(uint8_t v)
{
    for (int i = 0; i < 8; i++) {
        ow_bit_escribir((v >> i) & 1u);
    }
}

static uint8_t ow_leer(void)
{
    uint8_t v = 0;
    for (int i = 0; i < 8; i++) {
        if (ow_bit_leer()) {
            v |= (uint8_t)(1u << i);
        }
    }
    return v;
}

/* Deja la sonda a 10 bits (0,25 °C): sobra para tierra y mide en 188 ms. */
static bool ds18b20_leer(uint8_t sp[9])
{
    if (!ow_reset()) {
        return false;
    }
    ow_escribir(0xCC);                 /* SKIP ROM: hay una sola sonda  */
    ow_escribir(0x44);                 /* CONVERT T                     */
    delay(200);
    if (!ow_reset()) {
        return false;
    }
    ow_escribir(0xCC);
    ow_escribir(0xBE);                 /* READ SCRATCHPAD               */
    for (int i = 0; i < 9; i++) {
        sp[i] = ow_leer();
    }
    return true;
}

/* ------------------------------------------------------------- lectura -- */
void sensores_iniciar(void)
{
    pinMode(RK_PIN_SENSORES_EN, OUTPUT);
    digitalWrite(RK_PIN_SENSORES_EN, HIGH);        /* apagados */
    pinMode(RK_PIN_UNOWIRE, OUTPUT_OPEN_DRAIN);
    digitalWrite(RK_PIN_UNOWIRE, HIGH);
    analogReadResolution(12);
    analogSetPinAttenuation(RK_PIN_SUELO_ADC, ADC_11db);
    analogSetPinAttenuation(RK_PIN_RIEL_ADC, ADC_11db);
    Wire.begin(RK_PIN_SDA, RK_PIN_SCL, 100000);

#if RK_AIRE_SHT21
    /* SHT21/HTU21/Si7021: reset por software y a los 15 ms esta listo. Se
     * queda con su configuracion de fabrica, 14 bits de temperatura y 12 de
     * humedad, que es lo que asume el tiempo de espera de sensores_leer. */
    const uint8_t sht_reset = 0xFE;
    i2c_escribir(RK_I2C_SHT21, &sht_reset, 1);
    delay(20);
#else
    /* AHT20: si no reporta calibrado, se inicializa (0xBE 0x08 0x00). */
    uint8_t est = 0;
    if (i2c_leer(RK_I2C_AHT20, &est, 1) && !(est & 0x08)) {
        const uint8_t init[3] = { 0xBE, 0x08, 0x00 };
        i2c_escribir(RK_I2C_AHT20, init, 3);
        delay(10);
    }
#endif
    /* BH1750: encendido. */
    const uint8_t on = 0x01;
    i2c_escribir(RK_I2C_BH1750, &on, 1);
}
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

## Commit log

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2026-09-14 Terminal completa en el simulador: motor gráfico, Tuga.exe y pantalla
    Renderer RGB565 propio en vez de LVGL, y la decisión es específica de este
    hardware: el AXS15231B de la Guition no soporta refresco parcial, así que la
    optimización principal de LVGL no aplica; un buffer plano es exactamente lo
    que espera esp_lcd_panel_draw_bitmap(); y el pixel art necesita escalado por
    enteros, no el suavizado que LVGL asume. Lienzo lógico de 160x240 presentado
    a 320x480, exactamente 2x y sin interpolación.
    Tuga.exe no es un flipbook sino un rig: un cuerpo, ocho juegos de ojos, seis
    bocas y una capa de efectos que se combinan según el ánimo, más animación
    procedural — respiración senoidal,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
    [main.c]
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2026-09-14 Protocolo, núcleo del Spore, arnés de pruebas y optimización del render
    Protocolo binario de 24 bytes entre Spore y Terminal. Cada byte es tiempo de
    radio encendida y la radio es lo único que consume de verdad en el nodo, así
    que el formato es fijo y sin campos opcionales. La iluminancia va comprimida
    en mantisa y exponente porque hay que cubrir de 1 a 100.000 lux sin perder
    resolución abajo, que es donde vive el umbral de noche. CRC16-CCITT anclado
    al vector canónico, y un test verifica que los 192 flips de un bit se
    detecten.
    Núcleo del Spore en tres piezas. La conversión de suelo exige calibración por
    unidad y descarta lecturas físicamente imposibles: sin ese filtro el simbion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
    [main.c]
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2026-09-15 Vocabulario del kit y un verify que no puede pasar en falso
    Quedaban comentarios hablando de "el Spore" y "la Terminal" en mood.h,
    telemetry.h y nodo/*: se actualizan al vocabulario de nodos. Los que
    explican que la arquitectura CAMBIO se dejan como estaban, porque son
    justamente la parte util del registro.
    Y make verify tenia un agujero: desde WSL sobre /mnt/c, git falla con
    "dubious ownership", escribe el error en stderr y aun asi devuelve 0.
    Su salida vacia se leia como "no hay cambios que commitear", asi que el
    chequeo de frescura del arte pasaba en verde sin haber mirado nada.
    Ahora exige que git rev-parse devuelva algo antes de confiar en un git
    status vacio, y dice como arreglarlo.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
2026-09-16 El gachapon se vuelve fisico: carcasas impresas y una cara
    Cambio de producto, no refactor. Lo que varia entre unidades pasa a ser la
    CARCASA IMPRESA EN 3D y no un personaje dibujado; en pantalla queda solo la
    cara, que le hace juego a la carcasa que te toco. Se compra en caja ciega:
    cinco modelos a la vista y un secreto, como un Smiski.
    Por que: los doce simbiontes compartian silueta --una tortuga repintada doce
    veces-- y eso estaba anotado como compromiso explicito, pero documentar una
    debilidad no es resolverla. Ademas el esfuerzo estaba mal repartido: imprimir
    una carcasa cuesta filamento y unas horas de modelado, dibujar y animar un
    cuerpo cuesta semanas.
    El animo dice QUE siente, la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
    [face.c, main.c]
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2026-09-16 Roadmap al día: ROOTLAB, Rooties, sonido y lo que falta
    - roadmap: lo hecho en ROOTLAB (cuentas cifradas, recuperar contraseña,
    chat con la planta, tope de gasto y cuotas, paletas, seguridad web, VPS
    endurecido), lo urgente (clave de Anthropic nueva, guardar la clave
    maestra), la fase del parlantito, ROOTLAB Pro y los riesgos nuevos.
    - hardware: sección Sonido (buzzer, PAM8302 recomendado, I2S en el DevKit),
    cómo liberar un pin del C3 y la lista de compras.
    - firmware: accesorios y HTTPS con raíces fijadas.
    - carcasas: los ocho modelos. Conteos al día en el resto de los documentos
    y capturas regeneradas con los ocho Rooties.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
2026-09-19 El ingeniero de hardware: su instrucción, con todo el hardware adentro
    agentes/ingeniero-de-hardware.md es la instrucción completa para una sesión
    nueva que arranca sin contexto: diseñar la PCB (sustrato impreso en PETG con
    canaletas y pistas de cinta de cobre), el diagrama de conexiones y la guía de
    armado. Trae el cerebro (C3 SuperMini y el DevKit de banco), las dos
    pantallas (la de 1,44" del producto y la de 2,2" retirada, con los mismos
    pines), los sensores con el riel del que cuelga cada uno, las baterías y el
    circuito de carga, los mapas de pines, la lista de materiales y las reglas
    del proyecto.
    Y tres cosas que el diseño tiene que resolver con la placa en la mano: el
    pin BL d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
2026-09-20 Los Rooties en 3D: la carcasa y el personaje son la misma malla
    El cuerpo de la app dejó de ser un dibujo 2D "a partir del cual" alguien iba
    a modelar la carcasa. Ahora las cinco figuras son un modelo en milímetros del
    que salen las dos cosas: el personaje que gira en el teléfono y los STL de
    carcasas/, que se regeneran con `npm run carcasas` desde root-lab.
    Eso vuelve verificable lo que antes era una intención: la prueba de voladizos
    mide los triángulos que se van a imprimir, no una curva parecida.
    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
    [brote.stl, bulbo.stl, champi.stl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]
2026-09-20 La PCB impresa: sustrato con canaletas, cinta de cobre y su guia de armado
    El producto pasa de "modulos sueltos en una protoboard" a un nucleo comun que
    se arma igual cada vez: una placa de PETG impresa en 3D con canaletas, cinta
    de cobre soldada dentro de ellas, y los modulos montados encima. Uno solo
    para los cinco Rooties.
    Todo sale de un dato, como las caras. hardware/pcb/nucleo.json tiene los
    modulos, las redes y por donde corre cada pista; de ahi se generan el STL, la
    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
    [nucleo-sustrato.stl, sustrato.scad, sustrato_datos.scad]
2026-09-20 El personaje y la carcasa pasan a ser dos objetos
    Atar el diseño de los Rooties a que se imprimieran sin soportes dejó cinco
    cuerpos redondos y sin carácter. La restricción de fabricación va donde se
    fabrica: ahora el personaje de la app se esculpe libre y la carcasa se diseña
    aparte, en el CAD, tomando de él la silueta.
    carcasas/ pasa a tener los cinco personajes en STL como REFERENCIA de forma,
    no como el aparato.
    [brote.stl, bulbo.stl, champi.stl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]
2026-09-20 El elenco nuevo: Kip, Nori, Blink y Plum
    Los cinco Rooties botánicos se van y entran los cuatro personajes de Rocío,
    que son gente y no plantas: un piloto impetuoso, una crítica sofisticada, un
    cíclope optimista y una berenjenita empática. Una actitud se quiere más que
    una planta simpática, y en 128 × 128 una actitud se comunica con dos cejas.
    Lo que hubo que agregarle al motor de caras:
    - ojos RASGADOS (el corte angular de Kip) y ALMENDRADOS (Nori), tallados
    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
    [blink.stl, brote.stl, bulbo.stl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]
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2026-09-21 La estampadora: meter toda la cinta de cobre de una prensada
    Pegar los 51 tramos uno por uno es media tarde y 51 oportunidades de
    correrse. La estampadora es el negativo del sustrato -las mismas
    canaletas, pero en relieve-: se apoya una hoja de cinta sobre el
    sustrato, se baja esta pieza encima y se aprieta, y todas las pistas
    entran juntas. 77 x 109 x 7,5 mm, se imprime una sola vez y sirve para
    todas las unidades.
    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
    [encaje.scad, estampadora.scad, nucleo-estampadora.stl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]
2026-09-21 Sustrato v2.0: boquilla de 0,6, base plana y 24 % menos de placa
    La v1.0 se imprimio de verdad y la pieza dijo tres cosas. Esta es la
    respuesta a las tres, mas una cuarta que pidio Rogue.
    AGUJEROS QUE ENTREN. La placa estaba dibujada para una boquilla de 0,4 y
    se imprimio con una de 0,6: los agujeros de 1,0 mm salieron tapados,
    porque el perimetro se come el radio, y el pin no entra. Ahora el numero
    de la boquilla esta en el dato y todo sale de el: agujero minimo 1,4 mm,
    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
    [nucleo-estampadora.stl, nucleo-sustrato.stl, sustrato.scad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]
2026-09-21 Tres arreglos de la revisión del sustrato v2.0
    La versión estaba escrita dos veces —en `version` y como promesa al
    firmware— y ya se había desincronizado: el sustrato pasó a v2.0 y redes.h
    seguía afirmando "v1.0". Ahora sale del dato y no se puede volver a separar.
    El ruteador escribía su JSON con los finales de línea del sistema: en
    Windows dejaba el repo sucio y CI pedía "correr make pcb y commitear" por un
    ruteo idéntico. Escribe con LF, como todo el resto.
    Y la documentación razonaba sobre el elenco anterior: una de las razones para
    achicar la placa era que un domo bajo y ancho entrara en 116 mm, y ese Rooti
    ya no existe. La decisión sigue siendo buena por sí sola, pero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
2026-09-21 El sustrato v3.0: una protoboard impresa donde se clava todo
    La PCB deja de ser el chasis del producto y pasa a ser sólo lo que
    interconecta. Se fueron la ventana de la pantalla, el bolsillo del
    cargador y el hueco del USB: cada módulo se clava por su tira de pines
    —el ESP32 por sus 16, la pantalla por sus 9, el SHT21 por sus 4, el
    capacitivo por sus 3— y después vive donde la carcasa quiera.
    Manda la cinta. El rollo es de 5 mm y una canaleta de ancho a y hondo p
    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
    [estampadora.scad, nucleo-estampadora.stl, nucleo-sustrato.stl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]
2026-09-21 El cupón: media hora de impresora antes de tirar cinco placas
    Las tres preguntas que el sustrato v3.0 deja abiertas no se pueden
    contestar en la computadora, así que ahora hay una pieza que las contesta
    de una prensada:
    1. Hasta dónde se puede hundir la canaleta. Más profunda estira más la
    cinta sobre el borde y la deja más cerca de cortarse ahí sola, pero
    pasado un punto se rompe en el PISO, que es donde tiene que
    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
    [cupon-estampadora.stl, cupon-sustrato.stl, cupon.scad]
2026-09-21 El sustrato v3.1: los números del proceso, ya medidos
    El cupón se imprimió, se prensó y se lijó, y contestó las tres preguntas.
    Dos de las tres respuestas contradicen lo que decía el papel.
    La luz lateral de la nervadura pasa de 0,15 a 0,20 mm. Ganó la
    combinación del centro del cupón: 1,2 mm de profundidad con 0,20 de luz.
    Con 0,15 la nervadura agarra y la pieza no baja del todo; con 0,25 la
    cinta queda floja contra el borde y la lija no la corta pareja. La
    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
    [cupon-sustrato.stl, cupon.scad, nucleo-estampadora.stl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]
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
